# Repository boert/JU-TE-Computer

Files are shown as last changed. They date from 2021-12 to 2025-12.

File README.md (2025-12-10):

# JU+TE-Computer
Schaltpläne und z.T. Layouts für den JU+TE Computer

## JU+TE Tiny (2k-System)
Da vom JU+TE Computer kein zusammenhängender Schaltplan existierte, wurde er mit KiCAD erstellt.
Dieser Schaltplan wurde mit dem existierenden Layout verknüpft.
Schaltplan und Layout sind konsistent.

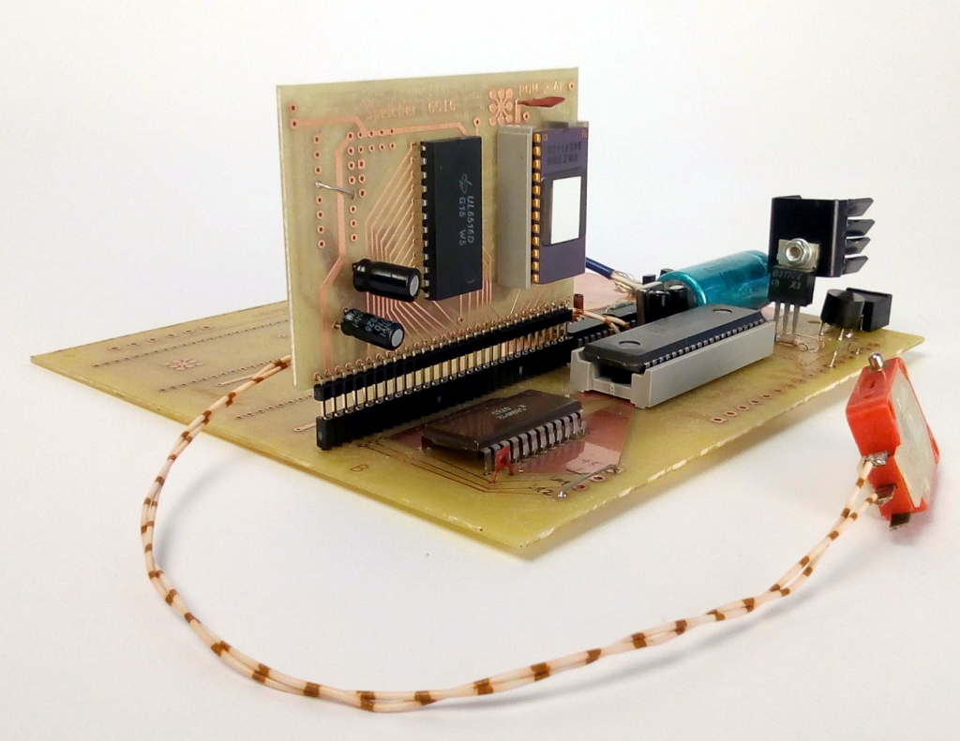
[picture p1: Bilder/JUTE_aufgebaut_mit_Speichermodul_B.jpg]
JU+TE 2k mit Speichermodul Typ B


Für den Minimalbetrieb sind ein Speichermodul (Typ A, B oder C) und eine Tastatur erforderlich.

## Erweiterungen zum JU+TE

### Speichermodul Typ A (2 kByte EPROM, 1 bis 8 kByte RAM) 
<p align="center">
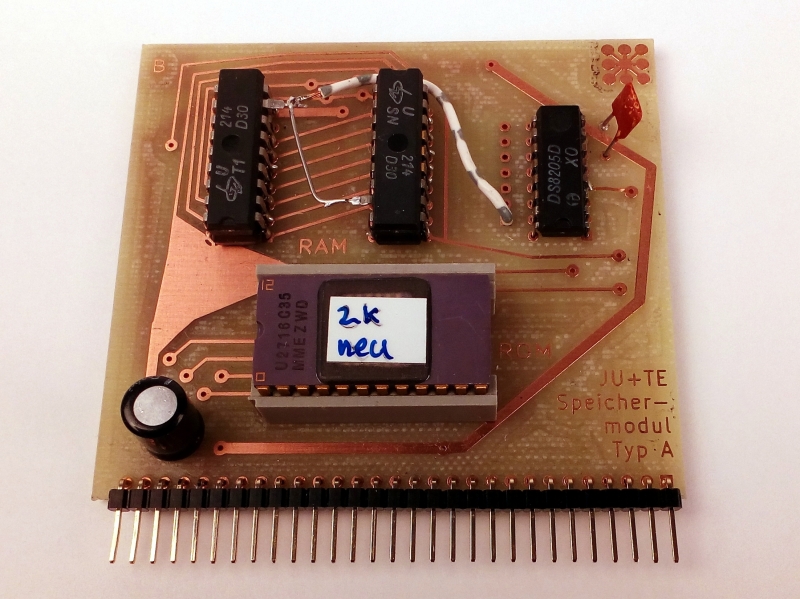
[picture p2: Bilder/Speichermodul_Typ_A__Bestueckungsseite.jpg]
Speichermodul Typ A, Bestückungsseite
  
&nbsp;
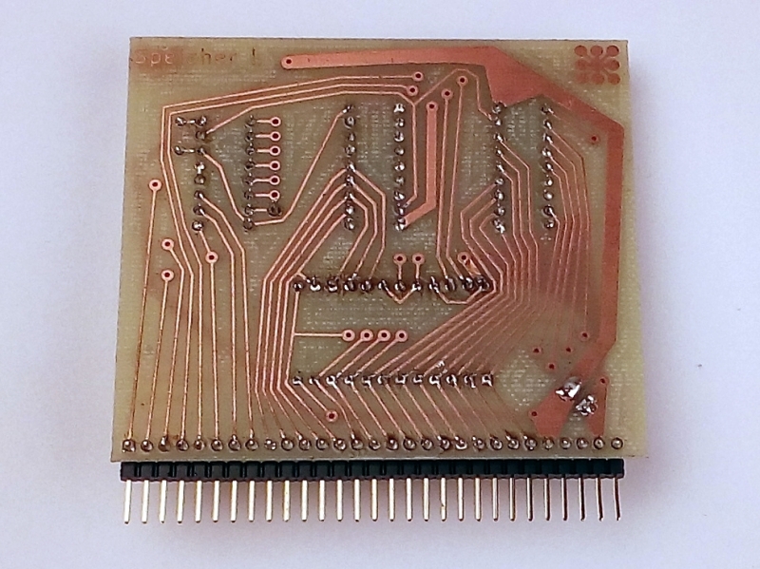
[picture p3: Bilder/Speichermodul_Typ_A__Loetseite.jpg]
Speichermodul Typ A, Lötseite
  
</p>
RAM erweiterbar bis auf 8 kByte durch zusätzliche U214 (Huckepack).
Für das 2k-System oder als unterer ROM für das 4k-System geeignet.<br>
Beim abgebildeten Modul wurde der RAM auf 2 kByte aufgestockt.
Bei mehr als 1 kByte RAM wird ein Adressdekoder DS8205D benötigt.

### Speichermodul Typ B (2 kByte EPROM, 2 bis 8 kByte RAM)
<p align="center">
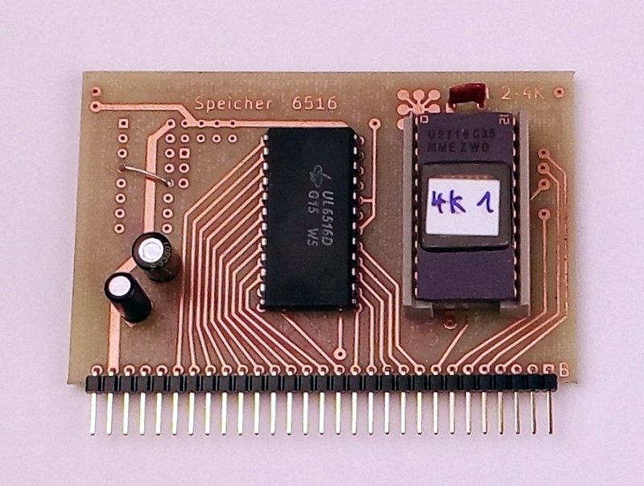
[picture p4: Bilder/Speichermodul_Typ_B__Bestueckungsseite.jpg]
Speichermodul Typ B, Bestückungsseite
  
&nbsp;
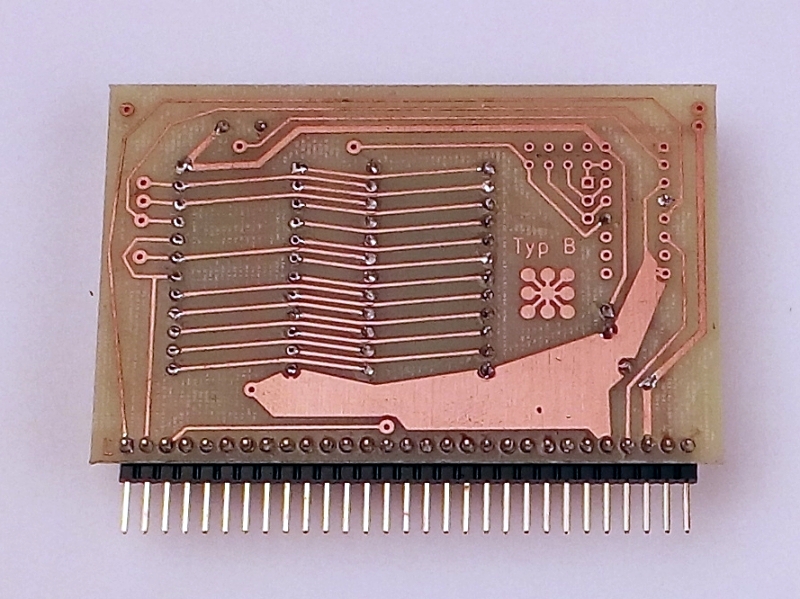
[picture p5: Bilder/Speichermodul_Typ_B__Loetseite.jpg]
Speichermodul Typ B, Lötseite
  
</p>
RAM erweiterbar bis auf 8 kByte durch zusätzliche U6516 (Huckepack).
Für das 2k-System oder als unterer ROM für das 4k-System geeignet.
Bei mehr als 2 kByte RAM wird ein Adressdekoder DS8205D benötigt.

### Speichermodul Typ C (8 kByte EPROM, 8 kByte RAM)
<p align="center">
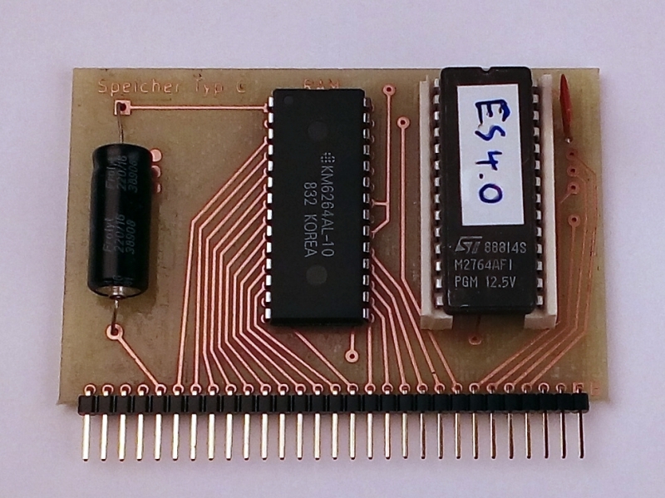
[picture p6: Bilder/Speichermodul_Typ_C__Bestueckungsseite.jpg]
Speichermodul Typ C, Bestückungsseite
  
&nbsp;
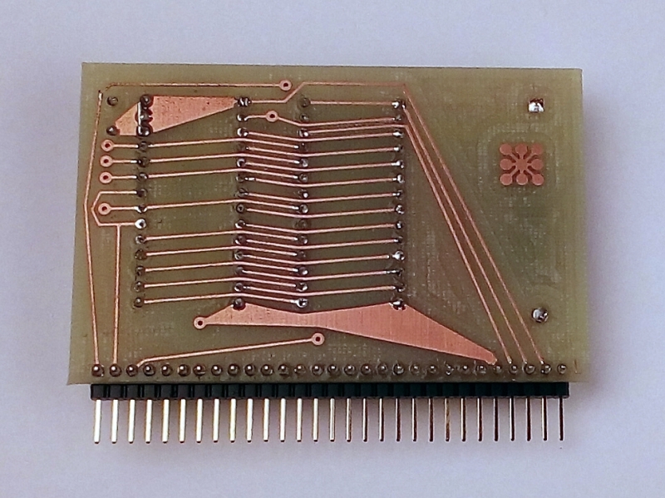
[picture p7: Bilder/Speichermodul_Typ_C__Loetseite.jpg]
Speichermodul Typ C, Lötseite
  
</p>
Für alle Ausbaustufen geeignet. Wenn das 2k-System oder das 4k-System in einen U2764 (8 kByte EPROM) gebrannt werden, muss das System ab Offset 0800h stehen.
Mit vier dieser Module läßt sich ein Vollausbau des Speichers realisieren (32 kByte RAM, 30 kByte EPROM).
Auch als Videospeicher für die Videoerweiterung nutzbar. In diesem Fall wird der EPROM nicht benötigt.

### Speichermodul Typ D (2 kByte EPROM)
<p align="center">
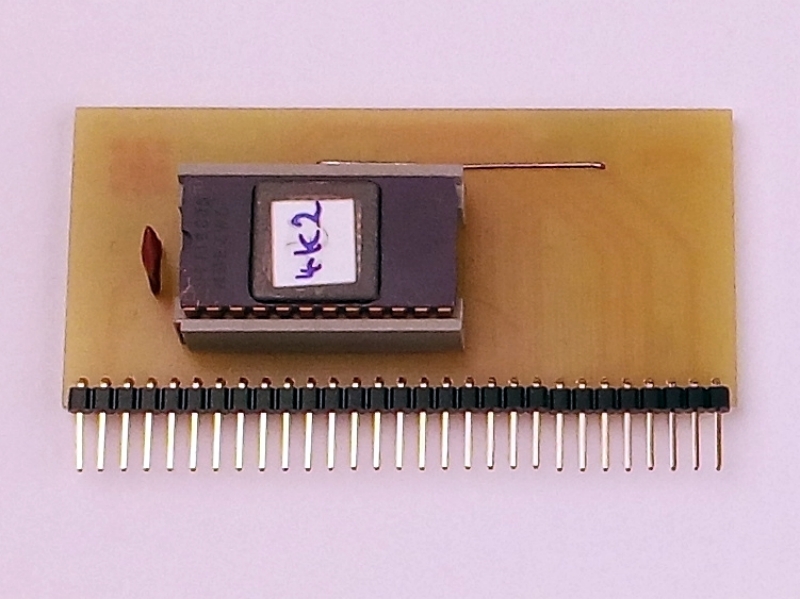
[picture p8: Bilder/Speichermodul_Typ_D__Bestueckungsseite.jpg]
Speichermodul Typ D, Bestückungsseite
  
&nbsp;
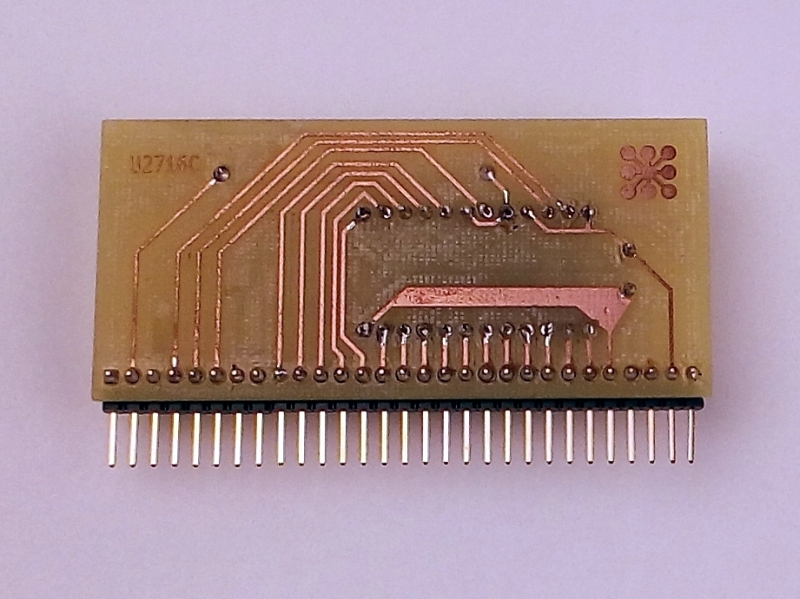
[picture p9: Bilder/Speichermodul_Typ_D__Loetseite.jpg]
Speichermodul Typ D, Lötseite
  
</p>
Das Modul wird nur als Ergänzungsspeicher für das 4k-System benötigt, falls Modul A oder Modul B schon vorhanden sind.

### RAM-Stütze
Dient dem Erhalt des RAM-Inhaltes im ausgeschalteten Zustand für Module mit CMOS-Schaltkreisen (U224, U6516 oder HM6264LP).
Mit verbesserter Reset-Schaltung. Die Reset-Schaltung nutzt die ~9V vom Ladekondesator.

### Magnetbandanschluss
<p align="center">
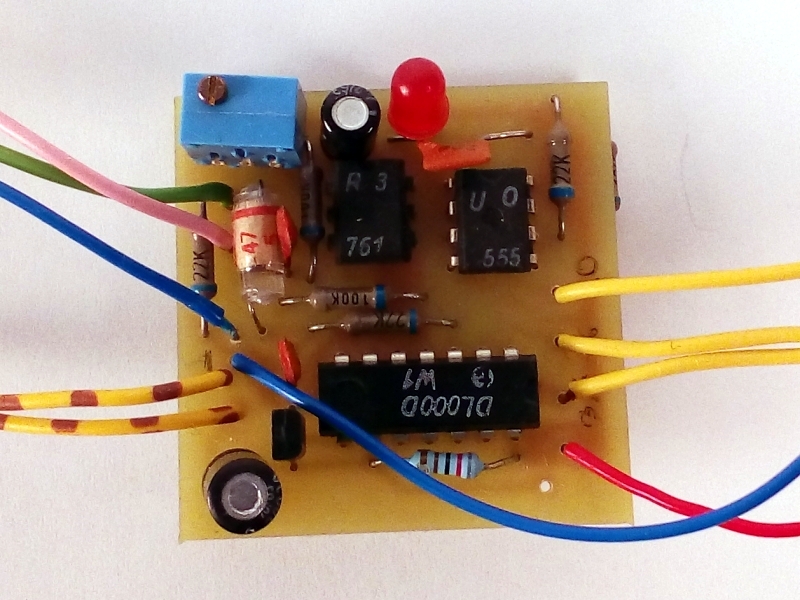
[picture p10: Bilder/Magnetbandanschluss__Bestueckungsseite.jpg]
Magnetbandanschluss, Bestückungsseite
  
&nbsp;
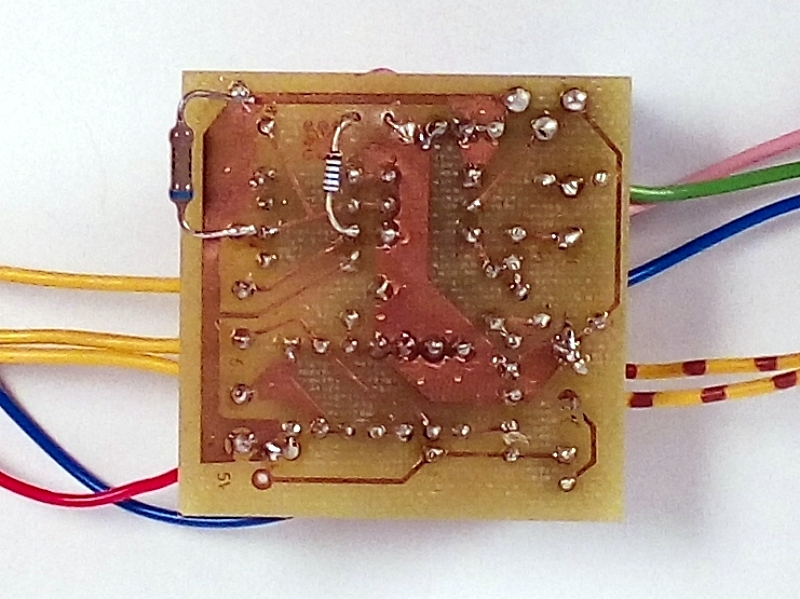
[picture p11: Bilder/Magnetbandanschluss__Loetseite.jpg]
Magnetbandanschluss, Lötseite
  
</p>
Damit lassen sich BASIC-Programme auf Band sichern und wieder zurücklesen.
Das Verfahren ist relativ einfach: Die Binärdaten werden über die SIO (Port P3.7) ausgegeben und mit 4,8 kHz vom Port P3.6 moduliert.
Es wird direkt der Speicherinhalt ausgegeben. Es gibt keine Fehlererkennung bzw. -korrektur, kein Dateiname und keine Adressinformation.
Die Schaltung läßt sich optimieren, indem der Pull-Up-Widerstand zwischen OPV (B761) und Inverter (B555) auf z.B. 8 kOhm reduziert wird.
Damit wird das Puls-/Pausverhältnis korrigiert.
Mit anderen Varianten des Magnektbankinterfaces (4k-System, 6k-System) läßt sich am 2k-System nichts mehr abspeichern, da dort der Modulator (DL000) fehlt.

### Magnetbandinterface 4k-System
<p align="center">
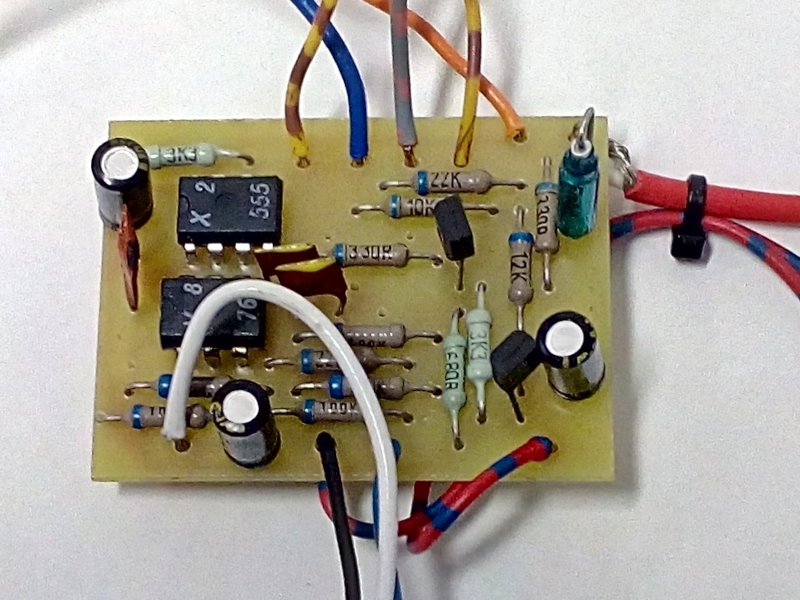
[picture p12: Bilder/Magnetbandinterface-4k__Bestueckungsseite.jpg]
Magnetbandinterface 4k-System, Bestückungsseite
  
&nbsp;
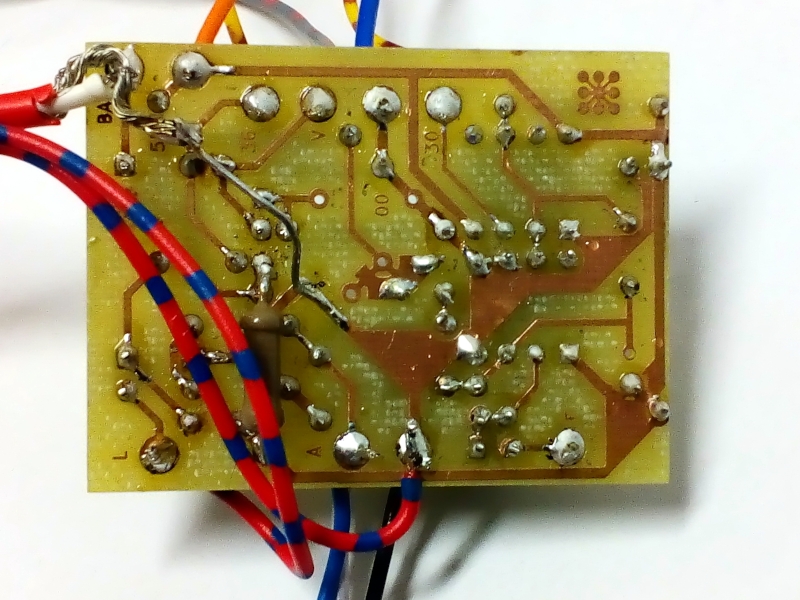
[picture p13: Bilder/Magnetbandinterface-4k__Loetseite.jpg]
Magnetbandinterface 4k-System, Lötseite
  
</p>
Weiterentwickeltes Magnetband-Interface für das 4k-System, zusätzlich mit integriertem Videosignalinverter.
Im 4k-System wird ein anderes Aufzeichnungsformat verwendet: Es gibt Trennzeichen (600 Hz), 0-Bits (1200 Hz) und 1-Bits (2400 Hz). Das Format entsprich dem des KC85 und enthält Dateinamen, Ladeadresse und Prüfsummen.

### Tastatur
Schaltungsvorschlag für eine 4x12 Matrixtastatur.

### Videoinverter
Ändert die Polarität des Videosignals und erzeugt ein BAS-Signal.
Die Originalschaltung ist sehr empfindlich. Robuster ist die Variante, die auf dem 4k-Magnetbandinterface realisiert ist. 

### UHF-Modulator
Mischt das BAS-Signal auf TV-Kanal 36. Die Erweiterung wird hier nicht weiter beschrieben.

### EPROM-Programmierzusatz
Erweiterung des JU+TE zum EPROM-Programmiergerät für die Typen U2716, U2764 und U27128.

### S3004-Interface
Potentialgetrennte Schnittstelle für die elektronische Schreibmaschine Erika S3004.
Nutzung der Schreibmaschine als Drucker.
Da der Rückkanal nicht verwendet wird, kann die Schreimaschine nicht als Tastatur genutzt werden.

### V.24-Interface
Pegelwandlerstufe zur Kopplung mit seriellen Perioheriegeräten (z.B. Drucker) oder zur Rechnerkopplung.
Die Interfaceschaltung nutzt die 9V-Spannung vom Ladekondensator.

### IFSS-Interface
Schnittstelle nach dem Prinzip der gekoppelten Stromschleifen, IFSS (Interface seriell sternförmig).
Das IFSS-Interface benötigt die 9V-Spannung vom Ladekondensator.

### AD-Wandler
Zur Messung von Spannungen zwischen 0 und 999 mV.

### Videoerweiterung
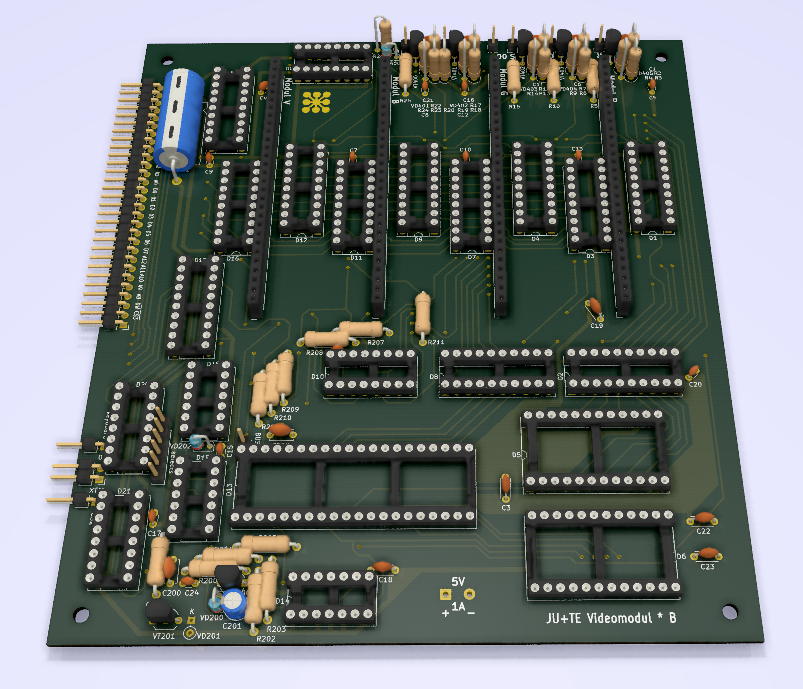
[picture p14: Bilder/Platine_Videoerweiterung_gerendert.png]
Videoerweiterung (Visualisierung)

Damit wird die Videosignalerzeugung von einem separaten Prozessor (UB8810, UB8830 oder UB8860) übernommen.
Der Bildspicher wird im Bereich zwischen %4000 und %5FFF im System eingeblendet.
Über Steuerregister (Adressen %6000-%63FF) wird festgelegt, auf welche Speicherebenen des Videospeicher zugegriffen wird.

Die mögliche Bildschirmauflösung und die nutzbare Farbtiefe hängt vom Speicherausbau ab:

Speichermodule | Video-RAM | Auflösung | Farbtiefe
-------------- | --------: | :-------: | ---------
1              | 8 kByte   |  320x192  | s/w
2              | 16 kByte  |  640x192  | s/w
4              | 32 kByte  |  320x192  | 16 Farben   
4              | 32 kByte  |  640x192  | 8 Farben

Ob es Software gibt, welche die hochauflösenden 640x192 Pixel-Modi nutzt, entzieht sich meiner Kenntniss.
Die Installation der Videoerweiterung erfordert die Verdrahtung zusätzlicher Signale, die nicht am Modulsteckplatz anliegen: TAKT, /CS3, KEY und BUSY

## JU+TE Kompakt (6k-System)
Im JU+TE Kompakt sind die Videoerweiterung, das Magnetbandinterface (4k-Version), 32 kByte RAM, die RAM-Stütze und 8 kByte EPROM integriert.
Um die Videoerweiterung zu nutzen wird im EPROM das 6k-System eingespielt.

## Nutzung der frei verfügbaren Ports

| Ports | P2.0 | P2.1 | P2.2 | P2.3 | P2.4 | P2.5 | P2.6 | P2.7 | P3.0 | P3.1 | P3.2 | P3.3 | P3.4 | P3.5 | P3.6 | P3.7 |
| --- |:----:|:----:|:----:|:----:|:----:|:----:|:----:|:----:|:----:|:----:|:----:|:----:|:----:|:----:|:----:|:---:|
| JU+TE-Grundplatine (7/1987) | | | | | | | | | | | | | (BS) | | | SYN |
| Magnetbandinterface (2k, 12/1987) | | | | | | | | | LOAD | | | | | | SAVE | Umschalt |
| Lauflicht (4/1988) | LED  | LED  | LED  | LED  | LED  | LED  | LED  | LED  | | | | | | | | |
| EPROM-Programmierzusatz (10/1988) | A+D  | A+D  | A+D  | A+D  | A+D  | A+D  | A+D  | A+D  | | | | | CTRL | CTRL | CTRL | |
| Magnetbankinterface (4k, 3/1989) | | | | | | | | | LOAD | | | | | | SAVE | |
| S3004-Interface (HW-SIO, 5/1989) | | | | | | | | | | | | | | | | TxD |
| S3004-Interface (SW, 5/1989) | | | | | | | | | | DSR  | | | | TxD  | | |
| IFSS-Inferface (10/1989) | | | | | | | | | E | | | | | | | S |
| V.24-Interface (HW-SIO, 10/1989) | | | | | | | | | RxD  | | | | | | | TxD |
| V.24-Interface (SW, K6340, 10/1989) | | | | | | | | | | DSR  | | | | TxD  | | |
| Streifenkorrektur (11/1989) | | | | | | | | | | | | | | VSYN | | |
| AD-Wandler (12/1989) | QA | QB | QC | QD | NSD  | MSD  | ISD  | | | | | | | | | |
| Magnetbankinterface (ES4.0, 1990) | | | | | | | | | LOAD | | | | | | SAVE | |
| Videoerweiterung (6/1990) | | | | | | | | | | | BUSY | | /HR  | | | |
| ROM-Bank (ES4.0, 2019) | | | | | | | | | | | | | | /BR  | | STEP |
| ROM-Bank (ES1988, 10/2021) | | | | | | | | | | | | | | STEP | | |
| | | | | | | | | | | | | | | | | |

Legende:  
A+D = Adresse und Daten  
BR = bank reset, Bank zurücksetzen  
BS = bank switch, Bankumschaltung, bisher keine Nutzung bekannt  
BUSY = Zugriff ohne Bildstörung  
CTRL = Steuerleitung  
DSR = Dataset Read, Empfangsbereitschaft  
E = Empfang  
HR = high resolution, Umschaltung Grafikmodus  
RxD = Empfangsdaten  
S = Senden  
STEP = Bank weiterschalten  
SYN = Synchronsignal für Video  
TxD = Sendedaten  
VSYN = Zeilensynchronisierung  

## Quellen  
https://hc-ddr.hucki.net/wiki/lib/exe/fetch.php/tiny/jutecomp1.pdf  
https://hc-ddr.hucki.net/wiki/lib/exe/fetch.php/tiny/jutecomp2.pdf  
https://hc-ddr.hucki.net/wiki/lib/exe/fetch.php/tiny/jutecomp3.pdf 

## Wikipedia
https://de.wikipedia.org/wiki/Ju-Te-Computer

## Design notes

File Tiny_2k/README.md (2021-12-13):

# KiCad-Projekt für JU+TE Computer

## Versionsgeschichte

### Version 1
nach Originallayout

### Version 2
- Bestückungsdruck ergänzt
- Footprint für C5 verlängert
- U14 stehend, statt liegend
- Footprint für D3 überarbeitet
- Footprints für Widerstände überarbeitet

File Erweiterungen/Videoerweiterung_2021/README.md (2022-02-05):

# JU+TE Videoerweiterung, 2021

Mit der Videoerweiterung läßt sich das Grundsystem zum 6k-System erweitern.

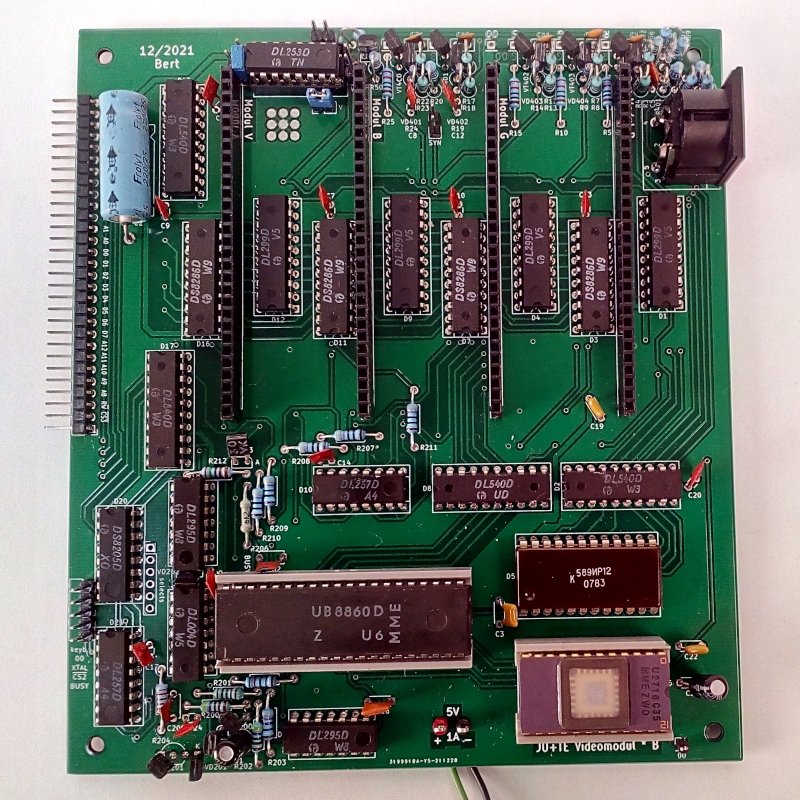
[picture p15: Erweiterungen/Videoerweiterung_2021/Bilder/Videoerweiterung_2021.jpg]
Videoerweiterung 2021


## Voraussetzungen
Folgende Voraussetzungen sind dafür zu erfüllen:
- im Steckplatz 1 (/CS0, /CS7) muß der EPROM mit dem 6k-System stecken
- im Steckplatz 1 müssen 8 kByte RAM bestückt sein
- im Steckplatz 4 wird die Videoerweiterung gesteckt
- ggf. muß eine angepasste Tastatur verwendet werden
- die Zusatzverbindungen für Takt, /CS2, /KEY und BUSY sind herzustellen
- es wird ein Bildschirm mit SCART-Eingang und ein entprechendes Adapterkabel benötigt

## Veränderungen gegenüber der Originalplatine
Die Version 2021 der Videoerweiterung enthält gegenüber dem Original von 1990 folgende Veränderungen:
- Videobuchse (DIN 5-polig) inklusive der nötigen Widerstände integriert;
  es passt das SCART-Adapterkabel vom Z9001
- Verbindungen zur Hauptplatine (Takt, /CS2, BUSY und /KEY) auf einer Steckleiste zusammengefasst
- BUSY-Signal zum Rand geführt
- Jumper für Umschaltsignal (high resolution) /HR ergänzt (Auswahl: low, high oder P3.4)
- am Videomultiplexer wurden Jumper für die Signale B und V ergänzt
- Jumper W hinzugefügt, um den Widerstandswert von R36 anpassen zu können (6,8 kOhm bzw. 2,2 kOhm)
- Jumper für SYN-Signal hinzugefügt
- frei Flächen mit 00 (GND) gefüllt
- Workaround für Timingprobleme ergänzt: R212 (1,5k) und VD203 (SAY32), Beschreibung in jutecomp3.pdf (Seite 46, Mitte unten)
- Massepunkt hinzugefügt (erleichtert die Fehlersuche)

## Belegung der Videobuchse (DIN 5-polig)
Pin    | Signal
------ | ------
1      | Grün
2      | Blau
3      | Synchronsignal bzw. BAS
4      | Rot
5      | Umschaltsignal /AV-RGB
Schirm | GND

Die Beschreibung eines passenden SCART-Kabels ist bei Ulrich Zander zu finden:
https://www.sax.de/~zander/z9001/tp.html#TV

## Anpassungen an der Grundplatine
Die Stromaufnahme der Videoerweiterung beträgt (ohne Video-RAM-Module) ca. 800 mA.
Damit ist der Spannungsregler der Grundplatine (B3170V) überfordert.
Es ist eine separate Einspeisung von geregelten 5V über die Videoerweiterung nötig.
Zum Schutz des B3170V (Spannung am Ausgang ggf. höher, als am Eingang) wird eine Diode zwischen Pin 2 (Ausgang, Anode) und Pin 3 (Eingang, Kathode) plaziert.

Für den Speicherbereich zwischen %6000 und %7FFF gibt es einen separaten Adressdekoder auf der Videoerweiterung. Damit neben der Bildschirmsteuerung die Tastatur weiterhin funktioniert, muß das /CS3-Signal zum Tastaturlatch (V40098D, Pin 1 und 15) aufgetrennt werden. Die Tastatur bekommt ihr Auswahlsignal (/KEY) nun von der Videoerweiterung.
Ein Rückbau ist durch Einsatz einer Steckbrücke möglich.

Der Videospeicher (VRAM) wird im Bereich %4000 bis %5FFF eingeblendet und benötig dazu das /CS2-Signal vom Steckplatz 3.

Außerdem wird noch der Systemtakt benötigt. Dieser läßt sich direkt nebem dem Taktgenerator abgreifen.

Das BUSY-Signal kann über einen 100 kOhm-Widerstand mit Port P3.2 der Haupt-CPU verbunden werden.

Wenn man alle zusätzlich Signale auf eine separate Buchsenleiste führt, ist der Einbau und auch der Rückbau der Videoerweiterung schnell und unkompliziert.

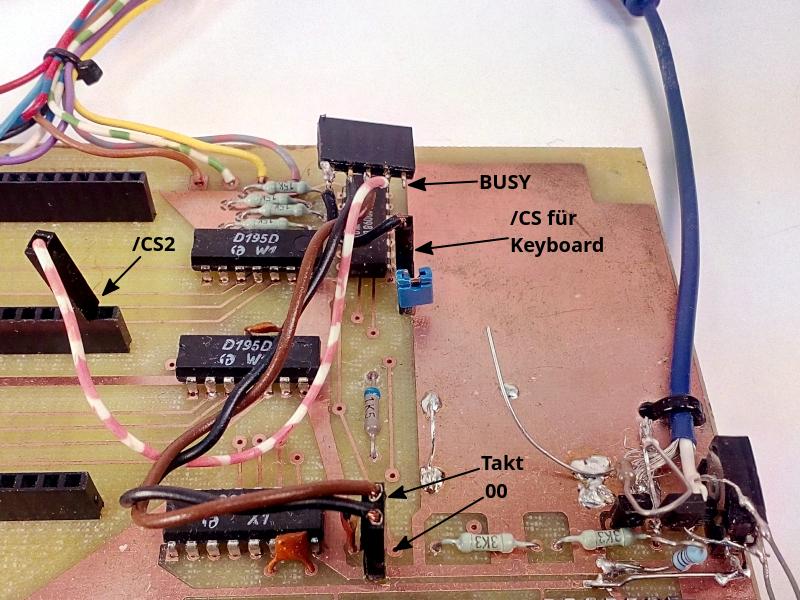
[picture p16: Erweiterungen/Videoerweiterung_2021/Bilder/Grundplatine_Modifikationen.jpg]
Videoerweiterung 2021


## Änderungen an der Grundplatine (Kurzform)
- Schutzdiode für B3170V einbauen
- Auftrennung /CS3, Steckbrücke für den Betrieb ohne Videoerweiterung ergänzen
- /CS2-Signal vom vorletzten Steckplatz verdrahten
- Systemtakt anschließen
- optional BUSY über 100 kOhm mit P3.2 verbinden

## Einbausituation
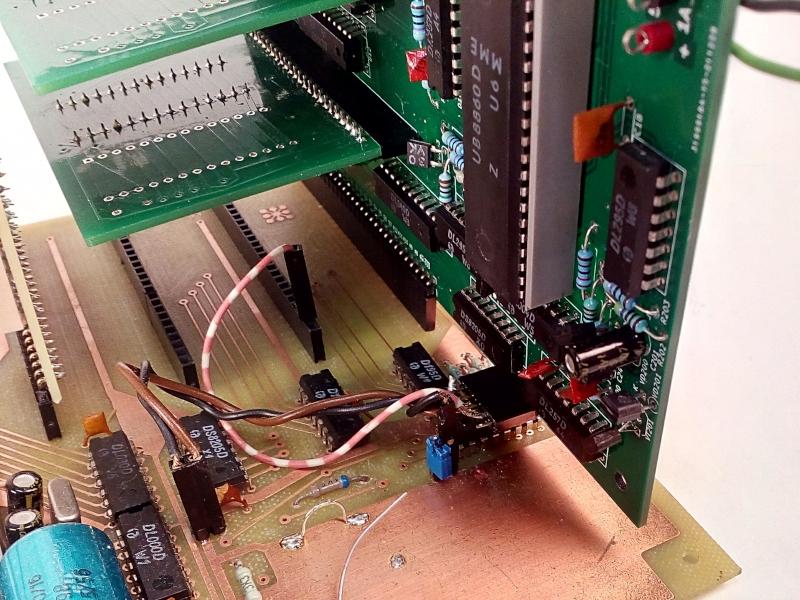
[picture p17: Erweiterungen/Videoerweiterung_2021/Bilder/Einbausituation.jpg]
Videoerweiterung 2021


Die senkrechte Montage hat den Nachteil, das hohe Speichermodule - wie der Typ C - die Modulsteckplätze 2 und 3 blockieren. Mit niedrigeren Speichermodulen oder einer waagerechten Montage (andere Steckverbinder) umgeht man das Problem.

## Quellen
https://hc-ddr.hucki.net/wiki/lib/exe/fetch.php/tiny/jutecomp3.pdf  
https://hc-ddr.hucki.net/wiki/doku.php/tiny/nachbauten

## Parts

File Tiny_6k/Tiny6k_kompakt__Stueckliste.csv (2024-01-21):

Source | Tiny6k_kompakt.sch
Kicad Rev | Eeschema 5.1.5+dfsg1-2build2
Generated Date | Sun Jan 21 20:19:16 2024
Title | JU+TE Tiny mit Videoerweiterung
Company | Jugend+Technik
Revision | 3
Date Issue | 21.01.24
Comment | Bert
Reference | Value | Library | Library Ref
D31 | UB8830 | RFT_Digitalschaltkreise | UB8830
D30 | DS8212D | RFT_Digitalschaltkreise | DS8212D
D28 | DL000D | RFT_Digitalschaltkreise | DL000D
D27 | DS8205D | RFT_Digitalschaltkreise | DS8205D
D25 | HM62256BLP | Memory_RAM | HM62256BLP
D34 | MB104 | RFT_Optoelektronik | MB104
X100 | Port 2 | Connector_Generic | Conn_01x08
X101 | Port 3 | Connector_Generic | Conn_01x08
VD105 | VQA15 | RFT_Optoelektronik | VQA15
VD104 | VQA15 | RFT_Optoelektronik | VQA15
D29 | B555D | RFT_Analogschaltkreise | B555D
VD103 | SAY | Device | D
C104 | 2.2µF | Device | CP_Small
VT101 | SC236 | RFT_Transistoren_und_Dioden | SC236
R105 | 220 | Device | R_Small
R106 | 2.4k | Device | R_Small
R107 | 1.2k | Device | R_Small
R110 | 22k | Device | R_Small
R111 | 75 | Device | R_Small
R112 | 8.2k | Device | R_Small
R100 | 1.2k | Device | R_Small
Q100 | 8 MHz | Device | Crystal_Small
VT100 | SC308 | RFT_Transistoren_und_Dioden | SC308
VD102 | SAY | Device | D
R103 | 820 | Device | R_Small
X104 | Batterie | Connector_Generic | Conn_01x02
R101 | 470 | Device | R_Small
D26 | U2764 (U27128) | RFT_Digitalschaltkreise | U27128
VD100 | 3PM 05 | Device | D_Bridge_+-AA
X103 | AC in | Connector_Generic | Conn_01x02
D100 | B3170V | RFT_Analogschaltkreise | B3170V
C101 | 4700µF | Device | CP_Small
C102 | 22nF | Device | C_Small
R108 | 180 | Device | R_Small
VD101 | SZX21/5.6 | Device | D_Zener_Small
R104 | 220 | Device | R_Small
C103 | 100nF | Device | C_Small
D24 | DL540D | RFT_Digitalschaltkreise | DL540D
X130 | Zeilen | Connector_Generic | Conn_01x08
R113 | 8x15k | Device | R_Network08
X131 | Key | Connector_Generic | Conn_01x01
D22 | DS8205D | RFT_Digitalschaltkreise | DS8205D
D23 | DS8205D | RFT_Digitalschaltkreise | DS8205D
X133 | Spalten | Connector_Generic | Conn_01x08
X132 | Spalten | Connector_Generic | Conn_01x08
X122 | Videomodul | Connector_Generic | Conn_01x29
X110 | Modul 2 | Connector_Generic | Conn_01x29
X120 | XTAL | Connector_Generic | Conn_01x02
D32 | B861D | RFT_Analogschaltkreise | B861D
R123 | 2.4k | Device | R_Small
R124 | 47k | Device | R_Small
R120 | 47k | Device | R_Small
R121 | 47k | Device | R_Small
C109 | 2.2µF | Device | CP_Small
R122 | 100k | Device | R_Small
C108 | 2.2µF | Device | CP_Small
R119 | 47k | Device | R_Small
X142 | Tape IN | Connector_Generic | Conn_01x01
R115 | 12k | Device | R_Small
VT102 | SC236 | RFT_Transistoren_und_Dioden | SC236
R114 | 220 | Device | R_Small
C105 | 1µF | Device | CP_Small
X140 | Speaker | Connector_Generic | Conn_01x02
R116 | 22k | Device | R_Small
R118 | 1k | Device | R_Small
X141 | Tape OUT | Connector_Generic | Conn_01x01
C116 | 10µF | Device | CP_Small
C117 | 10µF | Device | CP_Small
C114 | 10µF | Device | CP_Small
C115 | 10µF | Device | CP_Small
C110 | 22nF | Device | C_Small
C111 | 22nF | Device | C_Small
C112 | 22nF | Device | C_Small
C113 | 22nF | Device | C_Small
R109 | 560 | Device | R_Small
C100 | 10µF | Device | CP_Small
R102 | 10k | Device | R_Small
X121 | ~CS2 | Connector_Generic | Conn_01x01
X102 | BUSY | Connector_Generic | Conn_01x01
X106 | Bankumschaltung | Jumper | SolderJumper_2_Open
X105 | Reset | Connector_Generic | Conn_01x02
VD120 | SAY | Device | D
VD121 | SAY | Device | D
VD122 | SAY | Device | D
VD123 | SAY | Device | D
VD124 | SAY | Device | D
VD125 | SAY | Device | D
VD126 | SAY | Device | D
VD127 | SAY | Device | D
VD131 | SAY | Device | D
VD130 | SAY | Device | D
VD132 | SAY | Device | D
VD134 | SAY | Device | D
VD136 | SAY | Device | D
VD133 | SAY | Device | D
VD135 | SAY | Device | D
VD137 | SAY | Device | D
VT201 | SC236 | RFT_Transistoren_und_Dioden | SC236
VD201 | SZX21/7.5 | Diode | ZPDxx
VT200 | SC308 | RFT_Transistoren_und_Dioden | SC308
R201 | 1k | Device | R
R200 | 4.7k | Device | R
R202 | 4.7k | Device | R
R203 | 470 | Device | R
C201 | 1µF | Device | CP_Small
VD200 | SAY32 | Device | D
C200 | 33pF | Device | C_Small
R204 | 8.2k | Device | R
D19 | DL004D | RFT_Digitalschaltkreise | DL004D
R205 | 1.2k | Device | R
D5 | DS8212D | RFT_Digitalschaltkreise | DS8212D
D13 | UB8830 | RFT_Digitalschaltkreise | UB8830
D6 | U2716 | RFT_Digitalschaltkreise | U2716
D15 | DL540D | RFT_Digitalschaltkreise | DL540D
D17 | DL540D | RFT_Digitalschaltkreise | DL540D
D2 | DL540D | RFT_Digitalschaltkreise | DL540D
D8 | DL540D | RFT_Digitalschaltkreise | DL540D
D14 | DL295D | RFT_Digitalschaltkreise | DL295D
D21 | DL257D | RFT_Digitalschaltkreise | DL257D
D10 | DL257D | RFT_Digitalschaltkreise | DL257D
X200 | Bus | Connector_Generic | Conn_01x29
D20 | DS8205D | RFT_Digitalschaltkreise | DS8205D
D18 | DL295D | RFT_Digitalschaltkreise | DL295D
C202 | 220p | Device | C_Small
R206 | 6.2k | Device | R
VD202 | SAY32 | Device | D
R211 | 470 | Device | R
X203 | select | Connector_Generic | Conn_01x06
R207 | 470 | Device | R_Small
R208 | 470 | Device | R_Small
R210 | 470 | Device | R_Small
R209 | 470 | Device | R_Small
X201 | ~CS2 | Connector_Generic | Conn_01x01
X202 | XTAL | Connector_Generic | Conn_01x02
X204 | ~KEY | Connector_Generic | Conn_01x01
X205 | BUSY | Connector_Generic | Conn_01x01
D16 | DS8286D | RFT_Digitalschaltkreise | DS8286D
D12 | DL299D | RFT_Digitalschaltkreise | DL299D
X300 | 8k RAM-Modul | Connector_Generic | Conn_01x29
D11 | DS8286D | RFT_Digitalschaltkreise | DS8286D
D9 | DL299D | RFT_Digitalschaltkreise | DL299D
X302 | 8k RAM-Modul | Connector_Generic | Conn_01x29
D3 | DS8286D | RFT_Digitalschaltkreise | DS8286D
D1 | DL299D | RFT_Digitalschaltkreise | DL299D
X301 | 8k RAM-Modul | Connector_Generic | Conn_01x29
D7 | DS8286D | RFT_Digitalschaltkreise | DS8286D
D4 | DL299D | RFT_Digitalschaltkreise | DL299D
X303 | 8k RAM-Modul | Connector_Generic | Conn_01x29
X400 | SCART-F | Connector | SCART-F
R408 | 100 | Device | R
D0 | DL253D | RFT_Digitalschaltkreise | DL253D
R26 | 6.8k | Device | R_Small
R24 | 2.2k | Device | R_Small
VD400 | SAY32 | Device | D_Small
VD401 | SAY32 | Device | D_Small
R22 | 1k | Device | R_Small
R23 | 1k | Device | R_Small
VT400 | SC236 | RFT_Transistoren_und_Dioden | SC236
R25 | 220 | Device | R_Small
C21 | 33pF | Device | C_Small
R19 | 2.2k | Device | R_Small
VD402 | SAY32 | Device | D_Small
R17 | 1k | Device | R_Small
R18 | 1k | Device | R_Small
R20 | 220 | Device | R_Small
C16 | 33pF | Device | C_Small
R14 | 2.2k | Device | R_Small
VD403 | SAY32 | Device | D_Small
R12 | 1k | Device | R_Small
R13 | 1k | Device | R_Small
R15 | 220 | Device | R_Small
C11 | 33pF | Device | C_Small
R9 | 2.2k | Device | R_Small
VD404 | SAY32 | Device | D_Small
R7 | 1k | Device | R_Small
R8 | 1k | Device | R_Small
R10 | 220 | Device | R_Small
R4 | 2.2k | Device | R_Small
VD405 | SAY32 | Device | D_Small
R3 | 1k | Device | R_Small
R5 | 220 | Device | R_Small
C6 | 33pF | Device | C_Small
C1 | 33pF | Device | C_Small
VT401 | SC236 | RFT_Transistoren_und_Dioden | SC236
VT402 | SC236 | RFT_Transistoren_und_Dioden | SC236
VT404 | SC236 | RFT_Transistoren_und_Dioden | SC236
VT403 | SC236 | RFT_Transistoren_und_Dioden | SC236
R2 | 1k | Device | R_Small
R407 | 220 | Device | R_Small
R406 | 220 | Device | R_Small
R405 | 220 | Device | R_Small
R400 | 160 | Device | R_Small
R401 | 75 | Device | R_Small
R402 | 160 | Device | R_Small
R403 | 160 | Device | R_Small
R404 | 51 | Device | R_Small
JP400 | HR direkt | Device | Jumper_NC_Small
JP401 | HR_VCC | Device | Jumper_NO_Small
JP402 | HR_GND | Device | Jumper_NO_Small
D500 | U6264D | RFT_Digitalschaltkreise | U6264D
X500 | Bus | Connector_Generic | Conn_01x29
D501 | U2764 | RFT_Digitalschaltkreise | U2764
C501 | 33nF | Device | C_Small
C500 | 220µF | Device | CP_Small

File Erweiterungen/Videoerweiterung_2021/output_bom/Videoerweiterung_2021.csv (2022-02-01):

Source | Videoerweiterung.sch
Kicad Rev | Eeschema 5.1.10
Generated Date | Di 01 Feb 2022 20:56:21 CET
Title | JU+TE Videoerweiterung 2021
Company | Jugend+Technik
Revision | 3
Date Issue | 1.2.22
Comment | Bert
Reference | Value | Library | Library Ref
H1 | MountingHole | Mechanical | MountingHole
H2 | MountingHole | Mechanical | MountingHole
H4 | MountingHole | Mechanical | MountingHole
H3 | MountingHole | Mechanical | MountingHole
VT201 | SC236 | RFT_Transistoren_und_Dioden | SC236
VD201 | SZX21/7.5 | Diode | ZPDxx
VT200 | SC308 | RFT_Transistoren_und_Dioden | SC308
R201 | 1k | Device | R
R200 | 4 | 7k | Device | R
R202 | 4 | 7k | Device | R
R203 | 470 | Device | R
C201 | 1µF | Device | CP_Small
VD200 | SAY32 | Device | D
C200 | 33pF | Device | C_Small
R204 | 8 | 2k | Device | R
D19 | DL004D | RFT_Digitalschaltkreise | DL004D
R205 | 1 | 2k | Device | R
D5 | DS8212D | RFT_Digitalschaltkreise | DS8212D
D13 | UB8860 | RFT_Digitalschaltkreise | UB8830
D6 | U2716 | RFT_Digitalschaltkreise | U2716
D15 | DL540D | RFT_Digitalschaltkreise | DL540D
D17 | DL540D | RFT_Digitalschaltkreise | DL540D
D2 | DL540D | RFT_Digitalschaltkreise | DL540D
D8 | DL540D | RFT_Digitalschaltkreise | DL540D
D14 | DL295D | RFT_Digitalschaltkreise | DL295D
D21 | DL257D | RFT_Digitalschaltkreise | DL257D
D10 | DL257D | RFT_Digitalschaltkreise | DL257D
X200 | Bus | Connector_Generic | Conn_01x29
D20 | DS8205D | RFT_Digitalschaltkreise | DS8205D
D18 | DL295D | RFT_Digitalschaltkreise | DL295D
C202 | 220p | Device | C_Small
R206 | 6 | 2k | Device | R
VD202 | SAY32 | Device | D
R211 | 470 | Device | R
X203 | select | Connector_Generic | Conn_01x06
R207 | 470 | Device | R_Small
R208 | 470 | Device | R_Small
R210 | 470 | Device | R_Small
R209 | 470 | Device | R_Small
X201 | ~CS2 | Connector_Generic | Conn_01x01
X202 | XTAL | Connector_Generic | Conn_01x02
X204 | ~KEY | Connector_Generic | Conn_01x01
X205 | BUSY | Connector_Generic | Conn_01x01
X206 | POWER | Connector_Generic | Conn_01x02
TP201 | 00 | Connector | TestPoint_Small
R212 | 1 | 5k | Device | R_Small
VD203 | SAY32 | Device | D_Small
D16 | DS8286D | RFT_Digitalschaltkreise | DS8286D
D12 | DL299D | RFT_Digitalschaltkreise | DL299D
X300 | 8k RAM-Modul | Connector_Generic | Conn_01x29
D11 | DS8286D | RFT_Digitalschaltkreise | DS8286D
D9 | DL299D | RFT_Digitalschaltkreise | DL299D
X302 | 8k RAM-Modul | Connector_Generic | Conn_01x29
D3 | DS8286D | RFT_Digitalschaltkreise | DS8286D
D1 | DL299D | RFT_Digitalschaltkreise | DL299D
X301 | 8k RAM-Modul | Connector_Generic | Conn_01x29
D7 | DS8286D | RFT_Digitalschaltkreise | DS8286D
D4 | DL299D | RFT_Digitalschaltkreise | DL299D
X303 | 8k RAM-Modul | Connector_Generic | Conn_01x29
R406 | 100 | Device | R
R404 | 220 | Device | R_Small
R403 | 220 | Device | R_Small
R402 | 220 | Device | R_Small
R405 | 160 | Device | R_Small
R407 | 75 | Device | R_Small
R408 | 160 | Device | R_Small
R409 | 160 | Device | R_Small
R401 | 51 | Device | R_Small
X401 | DIN-5_180degree | Tiny2k_Bauteile | DIN-5_180degree
D0 | DL253D | RFT_Digitalschaltkreise | DL253D
R26 | 6 | 8k | Device | R_Small
R24 | 2 | 2k | Device | R_Small
VD400 | SAY32 | Device | D_Small
VD401 | SAY32 | Device | D_Small
R22 | 1k | Device | R_Small
R23 | 1k | Device | R_Small
VT400 | SC236 | RFT_Transistoren_und_Dioden | SC236
R25 | 220 | Device | R_Small
C21 | 33pF | Device | C_Small
R19 | 2 | 2k | Device | R_Small
VD402 | SAY32 | Device | D_Small
R17 | 1k | Device | R_Small
R18 | 1k | Device | R_Small
R20 | 220 | Device | R_Small
C16 | 33pF | Device | C_Small
R14 | 2 | 2k | Device | R_Small
VD403 | SAY32 | Device | D_Small
R12 | 1k | Device | R_Small
R13 | 1k | Device | R_Small
R15 | 220 | Device | R_Small
C11 | 33pF | Device | C_Small
R9 | 2 | 2k | Device | R_Small
VD404 | SAY32 | Device | D_Small
R7 | 1k | Device | R_Small
R8 | 1k | Device | R_Small
R10 | 220 | Device | R_Small
R4 | 2 | 2k | Device | R_Small
VD405 | SAY32 | Device | D_Small
R3 | 1k | Device | R_Small
R5 | 220 | Device | R_Small
C6 | 33pF | Device | C_Small
C1 | 33pF | Device | C_Small
VT401 | SC236 | RFT_Transistoren_und_Dioden | SC236
VT402 | SC236 | RFT_Transistoren_und_Dioden | SC236
VT404 | SC236 | RFT_Transistoren_und_Dioden | SC236
VT403 | SC236 | RFT_Transistoren_und_Dioden | SC236
R2 | 1k | Device | R_Small
X405 | 00 | Connector_Generic | Conn_01x01
C2 | 220µF/16V | Device | CP_Small
C3 | 100nF | Device | C_Small
C12 | 22nF | Device | C_Small
C13 | 22nF | Device | C_Small
C14 | 22nF | Device | C_Small
C15 | 22nF | Device | C_Small
C17 | 22nF | Device | C_Small
C18 | 22nF | Device | C_Small
C4 | 22nF | Device | C_Small
C5 | 22nF | Device | C_Small
C7 | 22nF | Device | C_Small
C8 | 22nF | Device | C_Small
C9 | 22nF | Device | C_Small
C10 | 22nF | Device | C_Small
C19 | 100nF | Device | C_Small
C22 | 100nF | Device | C_Small
C20 | 22nF | Device | C_Small
C24 | 22nF | Device | C_Small
JP507 | B | Device | Jumper_NO_Small
JP506 | SYN | Device | Jumper_NO_Small
JP502 | V | Device | Jumper_NO_Small
JP504 | HR_low | Device | Jumper_NO_Small
JP501 | HR_high | Device | Jumper_NO_Small
JP503 | HR_P34 | Device | Jumper_NO_Small
JP505 | W | Device | Jumper_NO_Small
R501 | 3 | 3k | Device | R_Small
TP400 | V | Connector | TestPoint_Small
TP401 | B | Connector | TestPoint_Small
TP402 | S | Connector | TestPoint_Small
TP403 | G | Connector | TestPoint_Small
TP404 | R | Connector | TestPoint_Small
C23 | 47µF/10V | Device | CP_Small

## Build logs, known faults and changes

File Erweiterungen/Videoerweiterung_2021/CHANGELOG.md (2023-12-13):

# Changelog

## 13.12.2023

* Verbindung zwischen Signal 'b' und R18 getrennt

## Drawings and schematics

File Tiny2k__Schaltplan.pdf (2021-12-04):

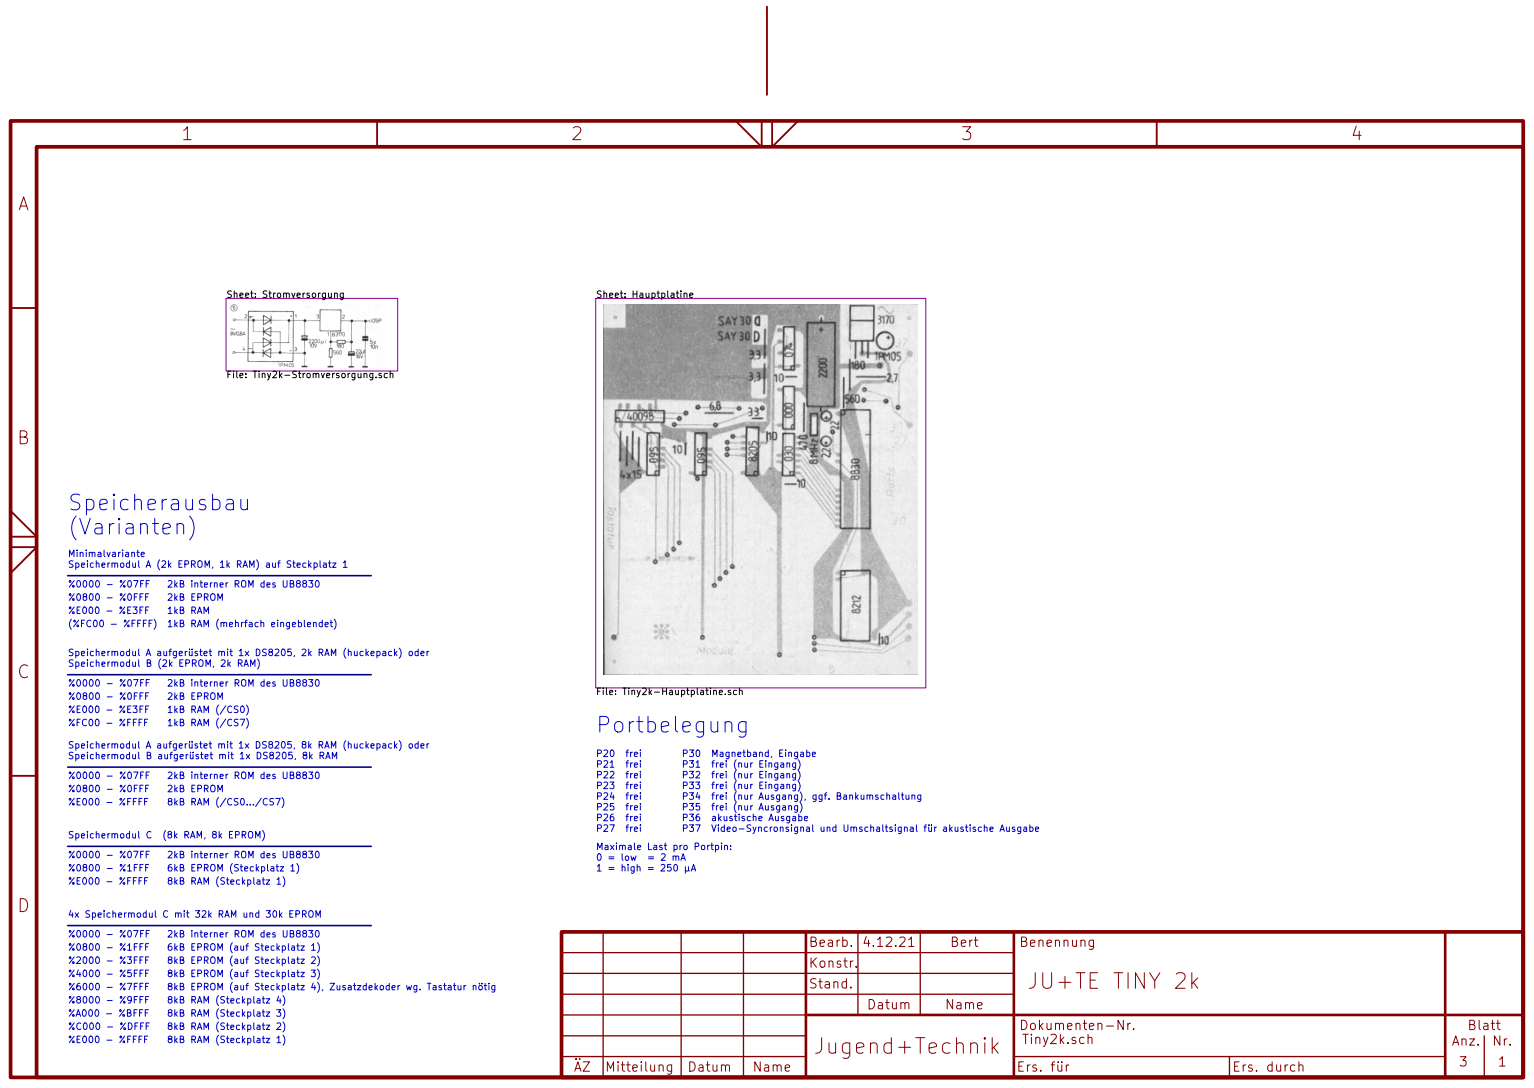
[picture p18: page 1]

Speichermodul A aufgerüstet mit 1x DS8205, 2k RAM (huckepack) oder

File: Tiny2k-Hauptplatine.sch %E000 - %FFFF %E000 - %FFFF

Speichermodul A aufgerüstet mit 1x DS8205, 8k RAM (huckepack) oder

P30 Magnetband, Eingabe
P31 frei (nur Eingang)
P32 frei (nur Eingang)
P33 frei (nur Eingang)
P34 frei (nur Ausgang), ggf. Bankumschaltung
P35 frei (nur Ausgang)
P36 akustische Ausgabe
P37 Video-Syncronsignal und Umschaltsignal für akustische Ausgabe

Maximale Last pro Portpin: 0 = low = 2 mA

Datum | Name

Dokumenten-Nr. | | Blatt

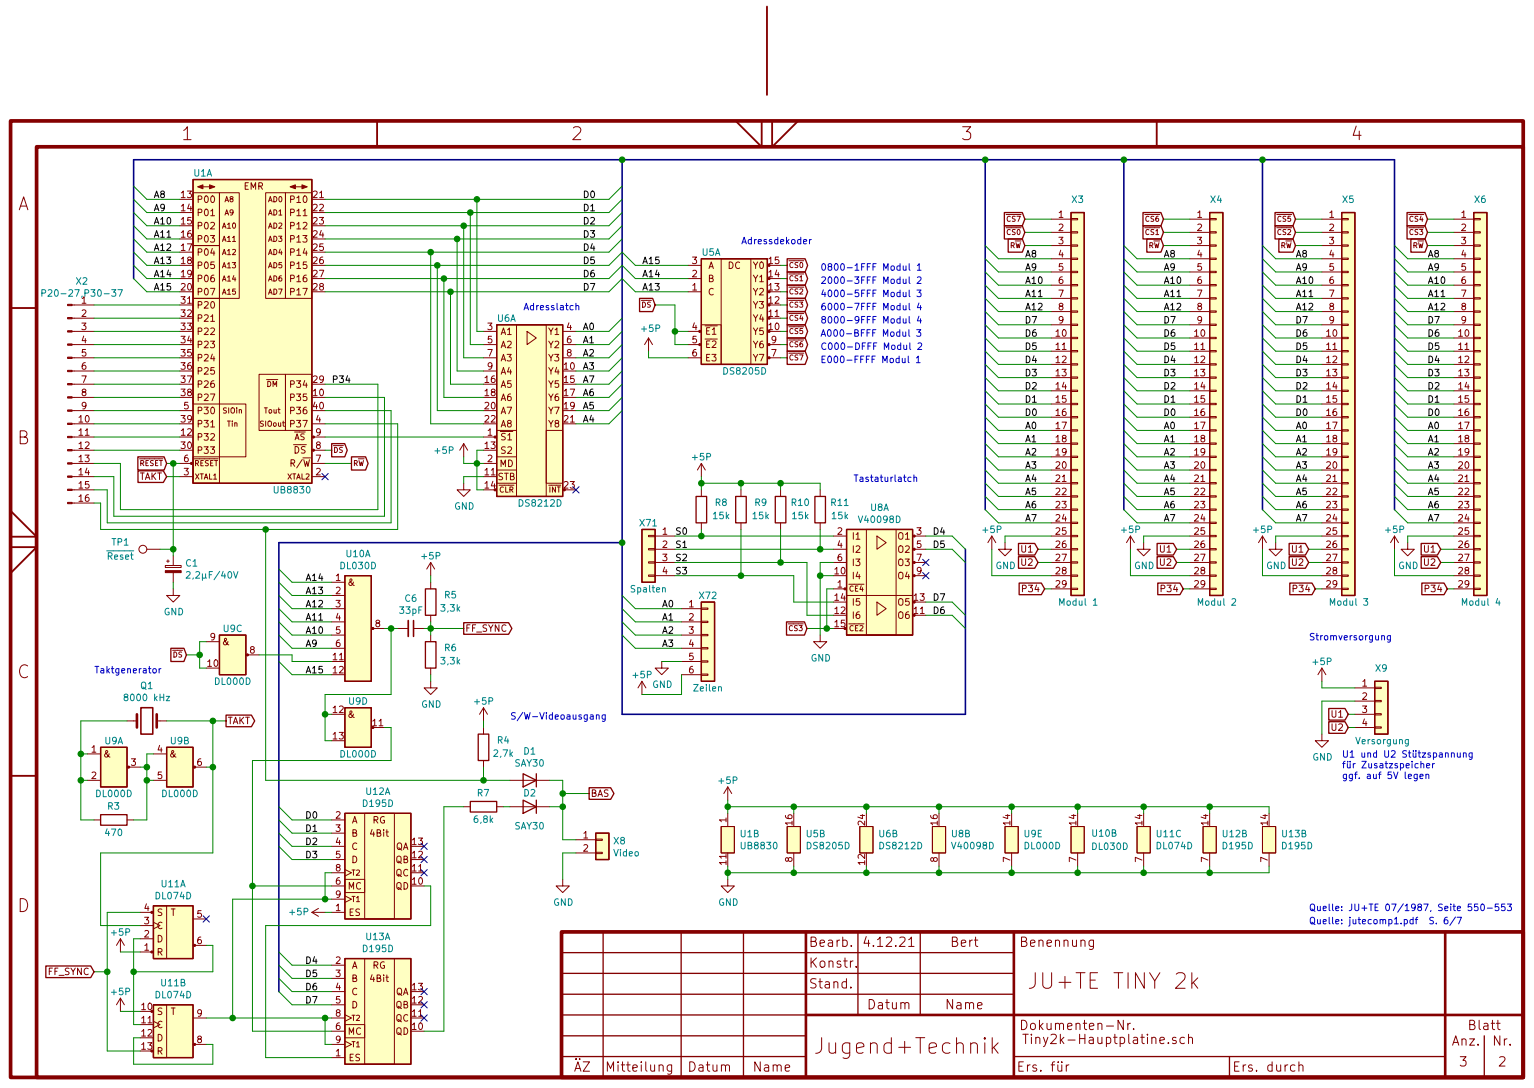
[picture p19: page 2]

0800-1FFF Modul 1 C000-DFFF Modul 2 S/W-Videoausgang

I5
12 | | 11

BC ESMC D | 4Bit A RG | QAQBQCQD

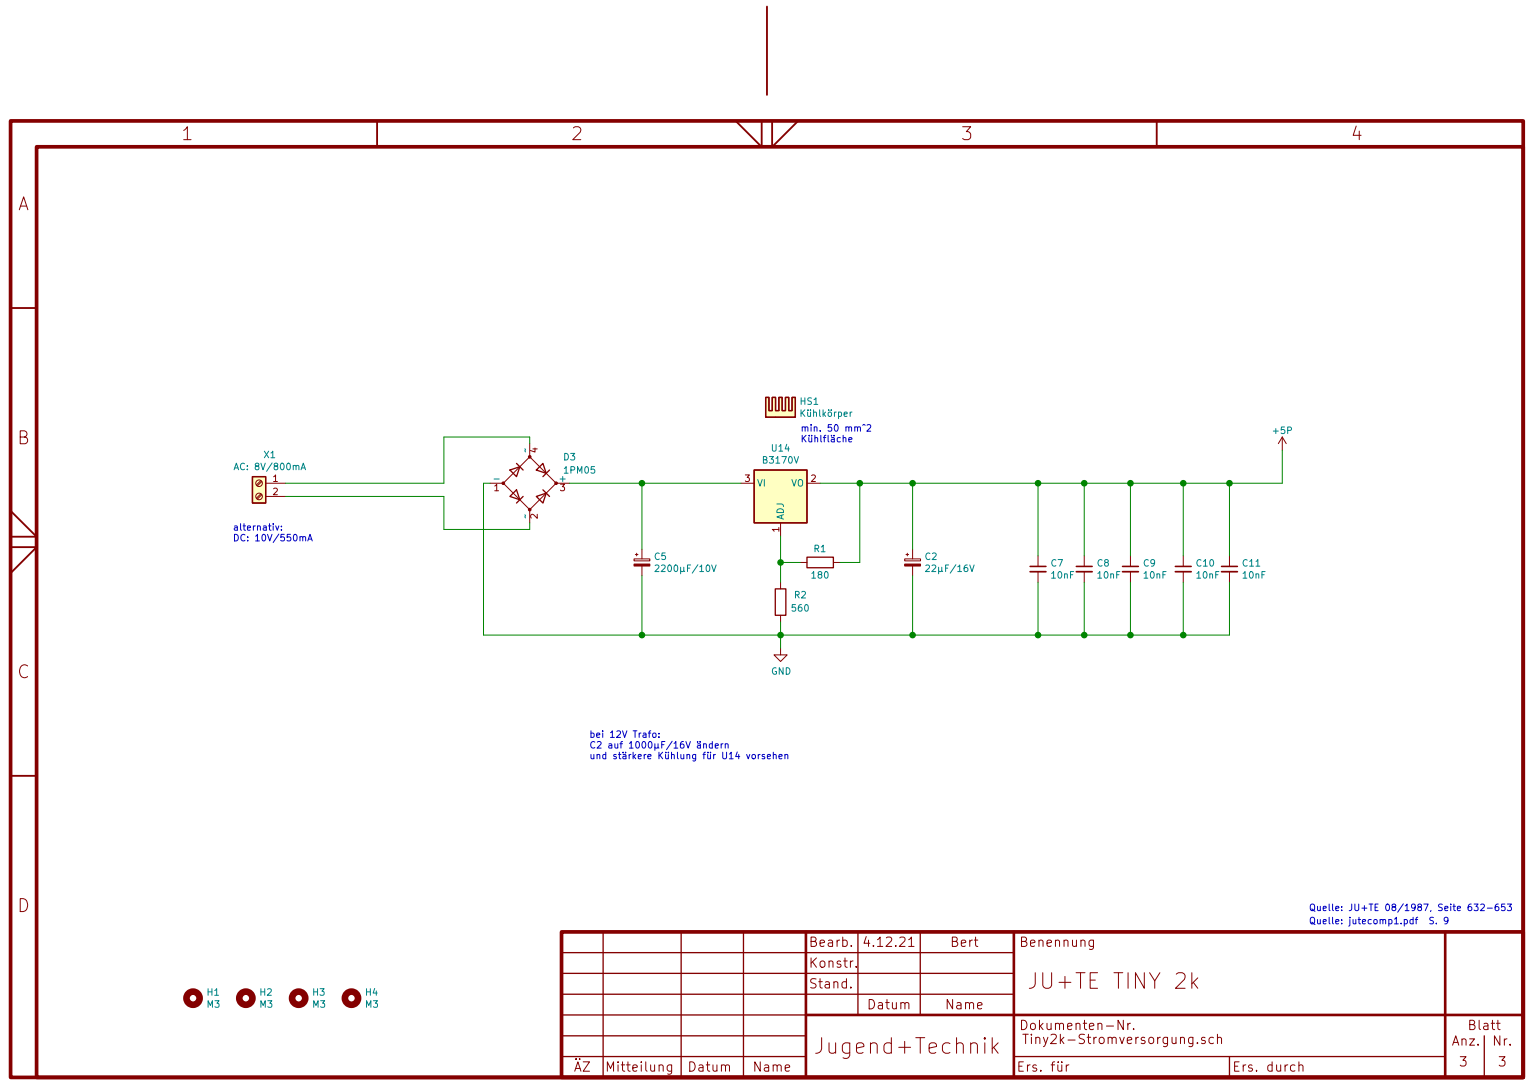
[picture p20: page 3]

bei 12V Trafo: C2 auf 1000µF/16V ändern

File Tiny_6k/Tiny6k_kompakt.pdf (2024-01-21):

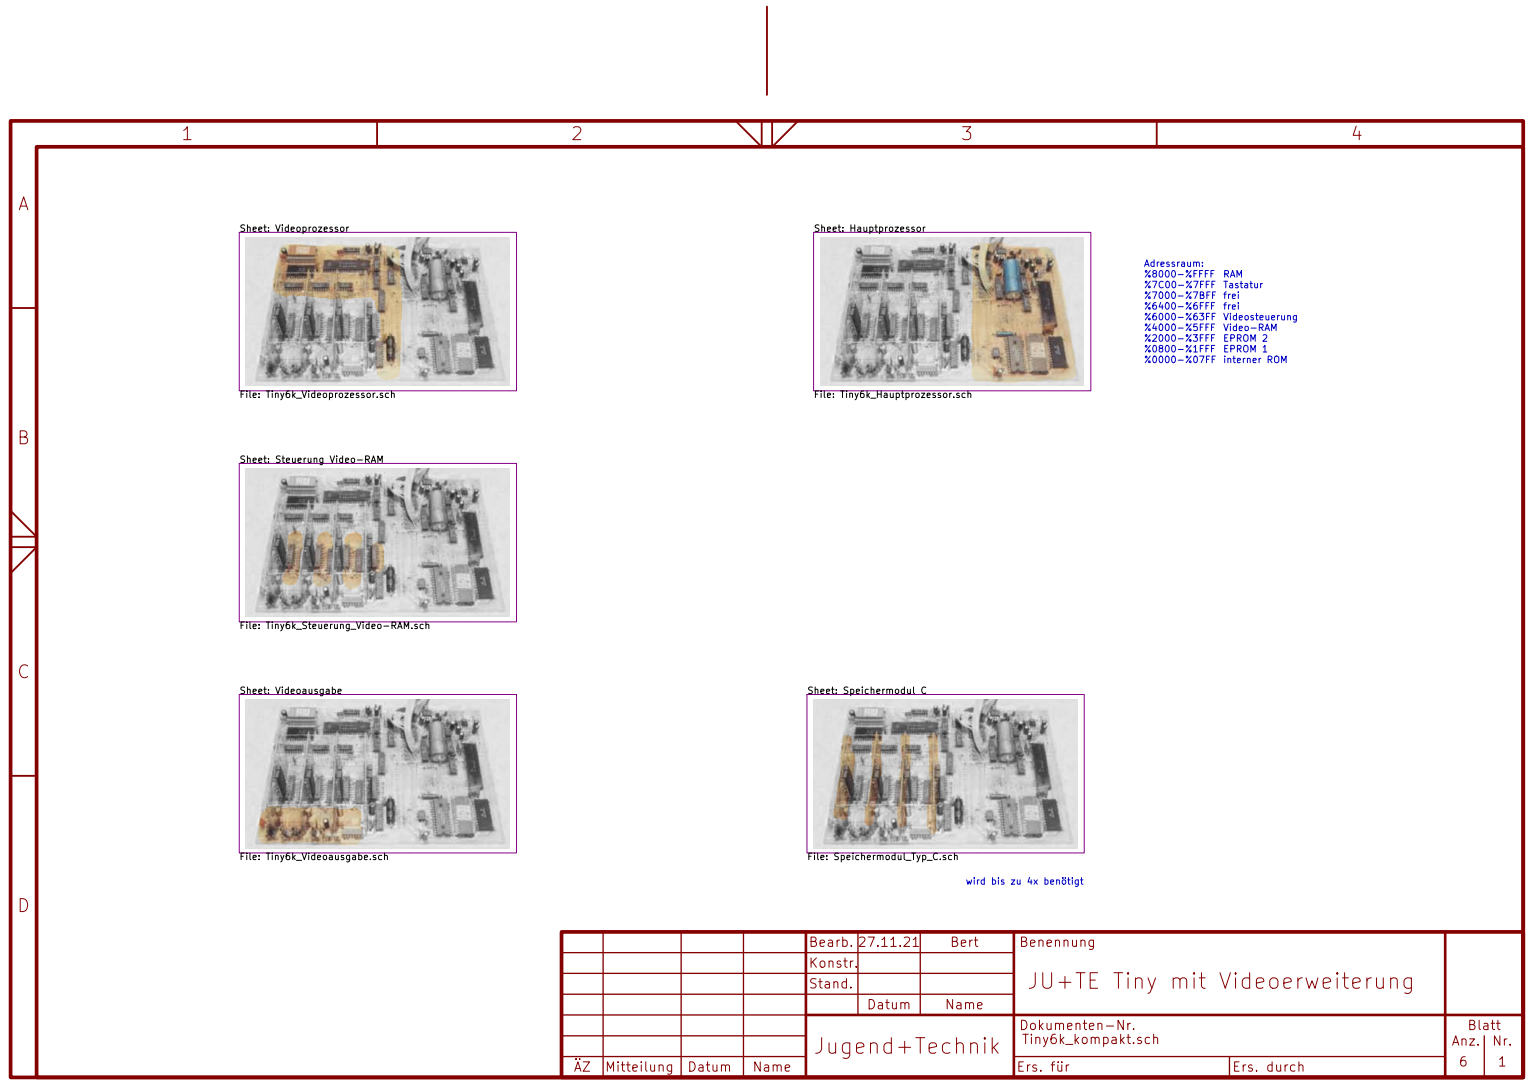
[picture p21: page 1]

Tastatur
frei frei Videosteuerung Video-RAM

Sheet: Steuerung Video-RAM

wird bis zu 4x benötigt

Benennung
JU+TE Tiny mit Videoerweiterung

Datum | Name

Dokumenten-Nr. | | Blatt

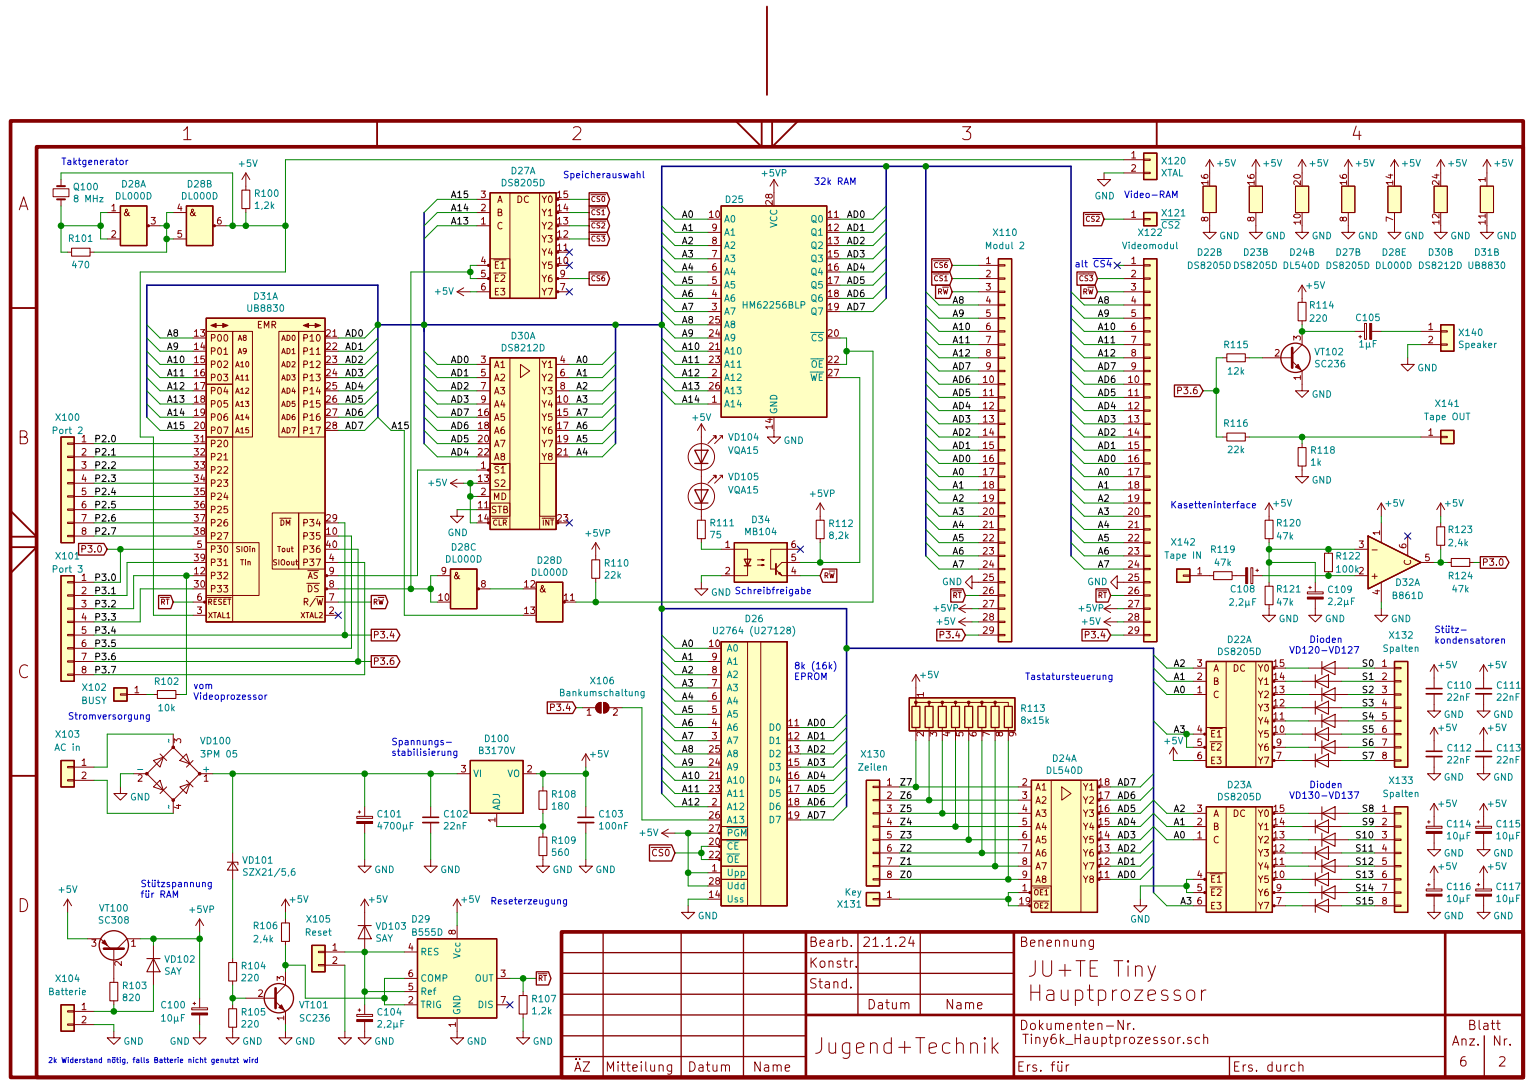
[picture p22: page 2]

Y1Y2Y3Y4Y5Y6Y7Y8 CLR INT S1 1

2 | 32
3 | 33
4 | 34 | 13

22k GND
2k Widerstand nötig, falls Batterie nicht genutzt wird Stromversorgung

Upp 1 A0 10 CE 20 A10 21 OE 22 A11 23 A9 24 A8 25 A13 26 PGM 27 Udd 28 A7 3 A6 4 A5 5 A4 6 A3 7 A2 8 A1 9 | D26 U2764 (U27128) | D0 D3 | 11 D1 12 D2 13 Uss 14 15 D4 16 D5 17 D6 18 D7 19 A12 2

3 | 4 | 16
4 | 5 | 15
5 | 6 | 14
6 | 7 | 13
7 | 8 | 12

1 TRIG 2 OUT 3 RES 4 Ref 5 COMP 6 DIS 7 Vcc 8 D29 B555D

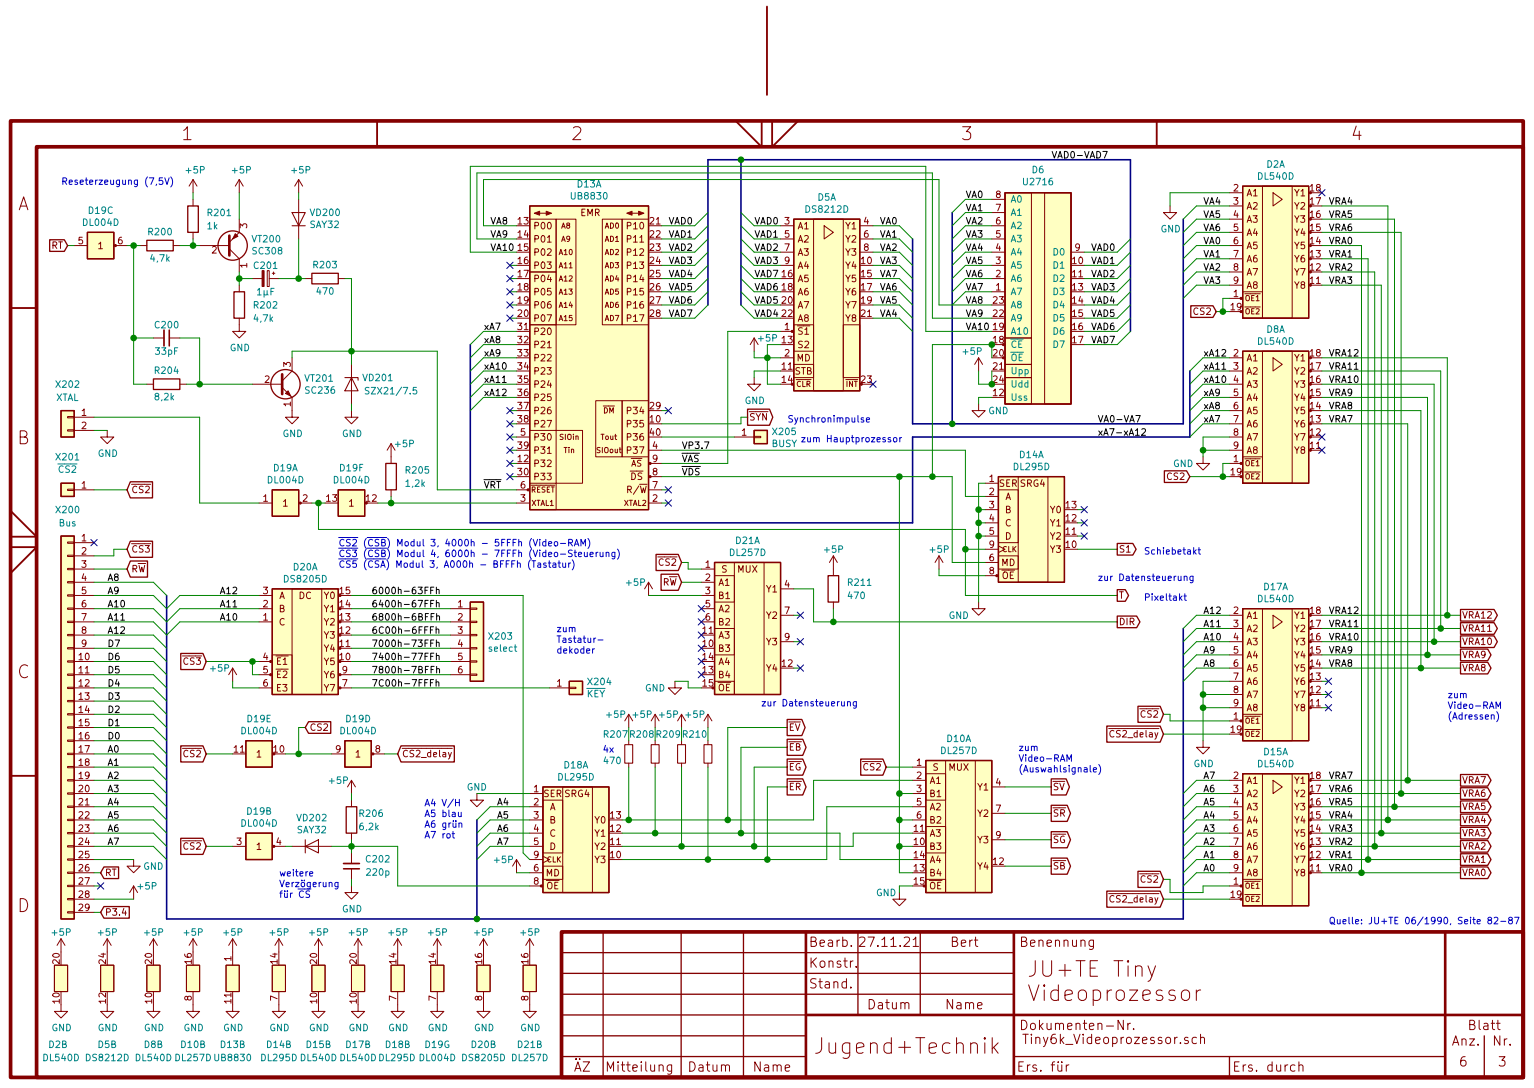
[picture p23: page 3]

CS3 (CSB) Modul 4, 6000h - 7FFFh (Video-Steuerung)
CS5 (CSA) Modul 3, A000h - BFFFh (Tastatur)

1 11 D13B UB8830 12 24 D5B DS8212D GND GND GND GND

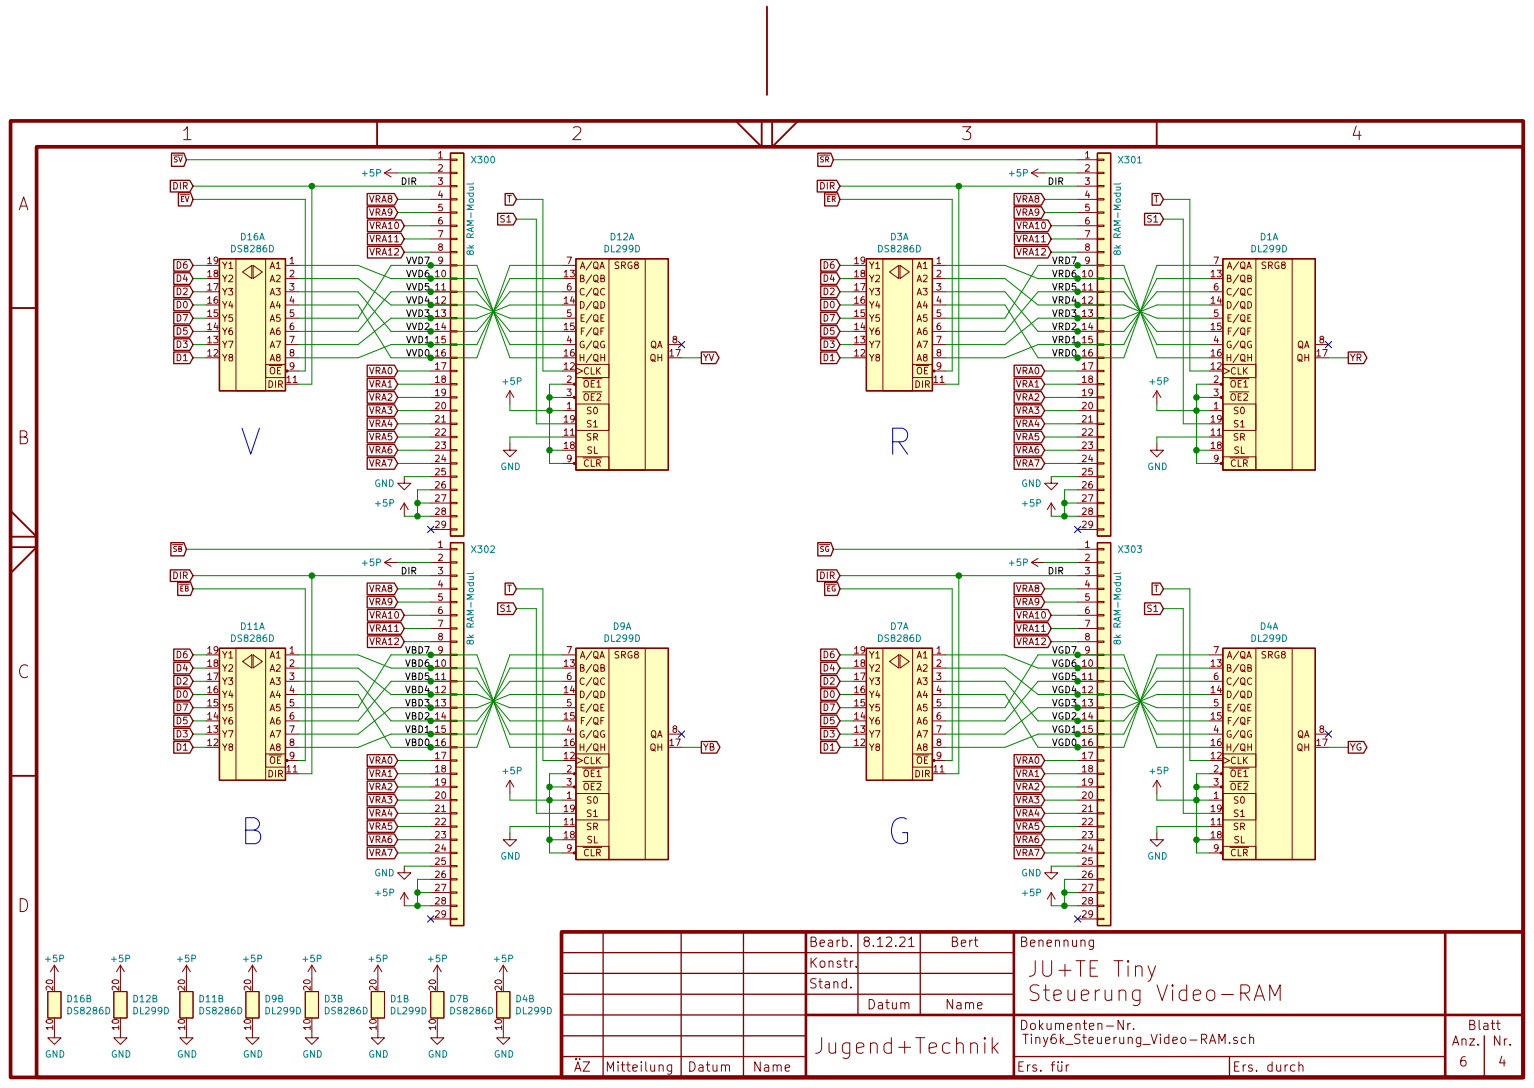
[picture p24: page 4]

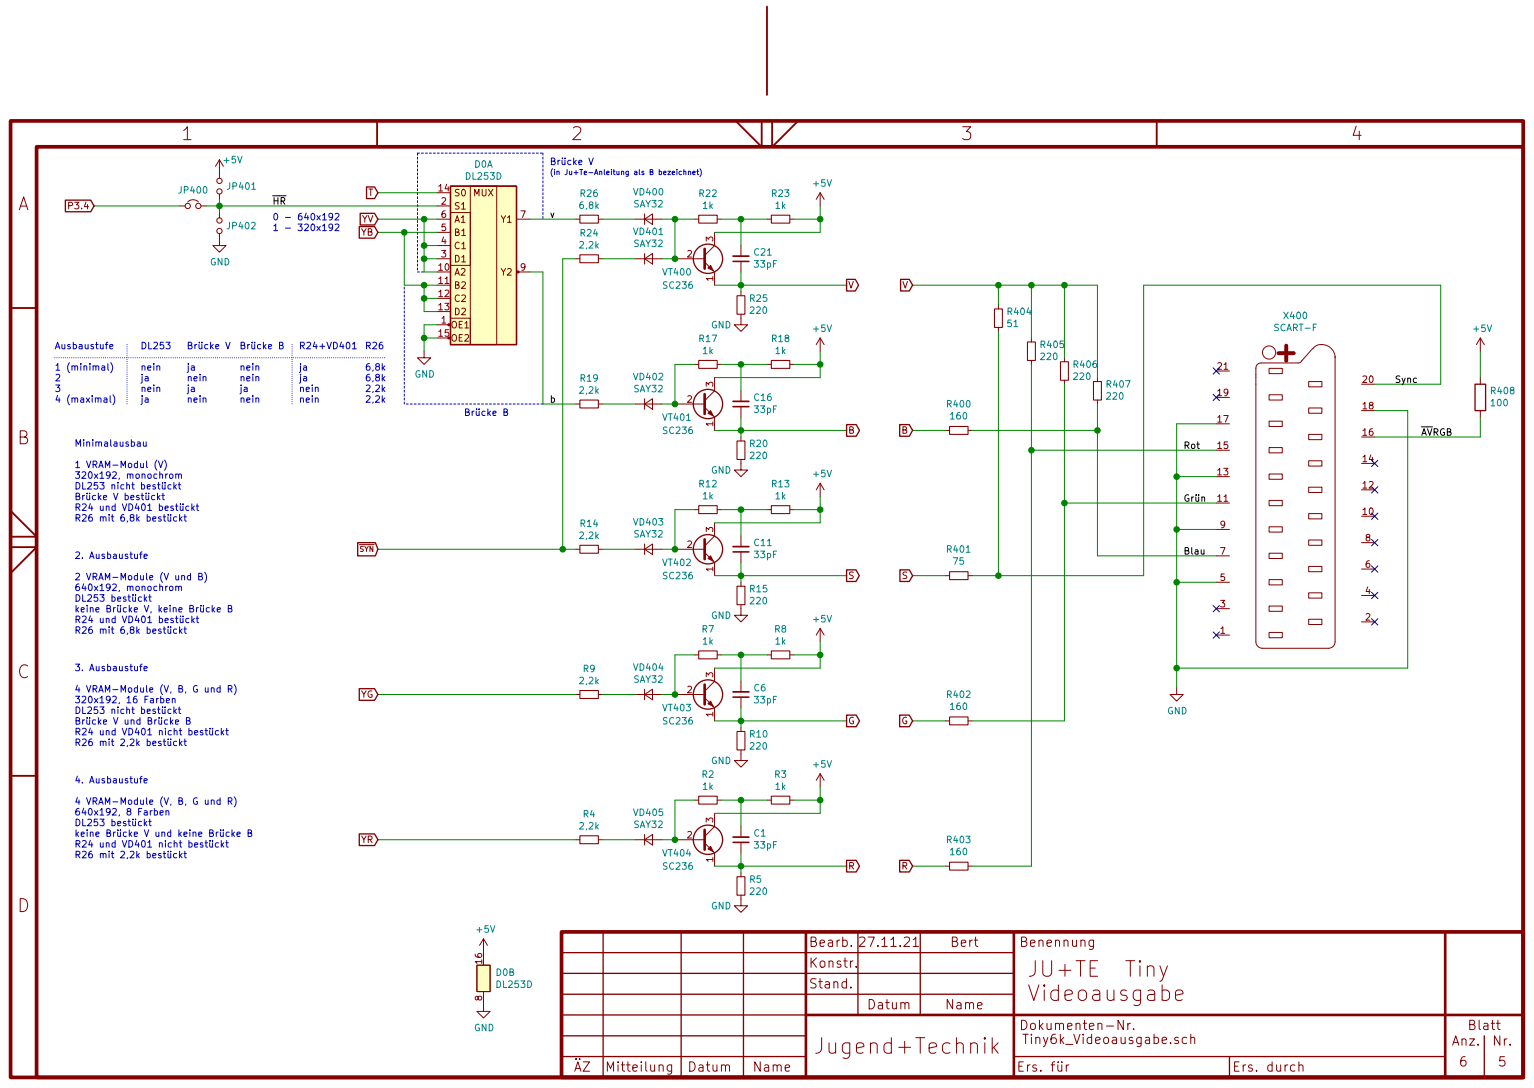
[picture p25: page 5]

(in Ju+Te-Anleitung als B bezeichnet) R26

DL253 nicht bestückt Brücke V bestückt R24 und VD401 bestückt R26 mit 6,8k bestückt

2 VRAM-Module (V und B) 640x192, monochrom

4 VRAM-Module (V, B, G und R) 320x192, 16 Farben DL253 nicht bestückt Brücke V und Brücke B R24 und VD401 nicht bestückt R26 mit 2,2k bestückt

4 VRAM-Module (V, B, G und R) 640x192, 8 Farben DL253 bestückt keine Brücke V und keine Brücke B R24 und VD401 nicht bestückt R26 mit 2,2k bestückt

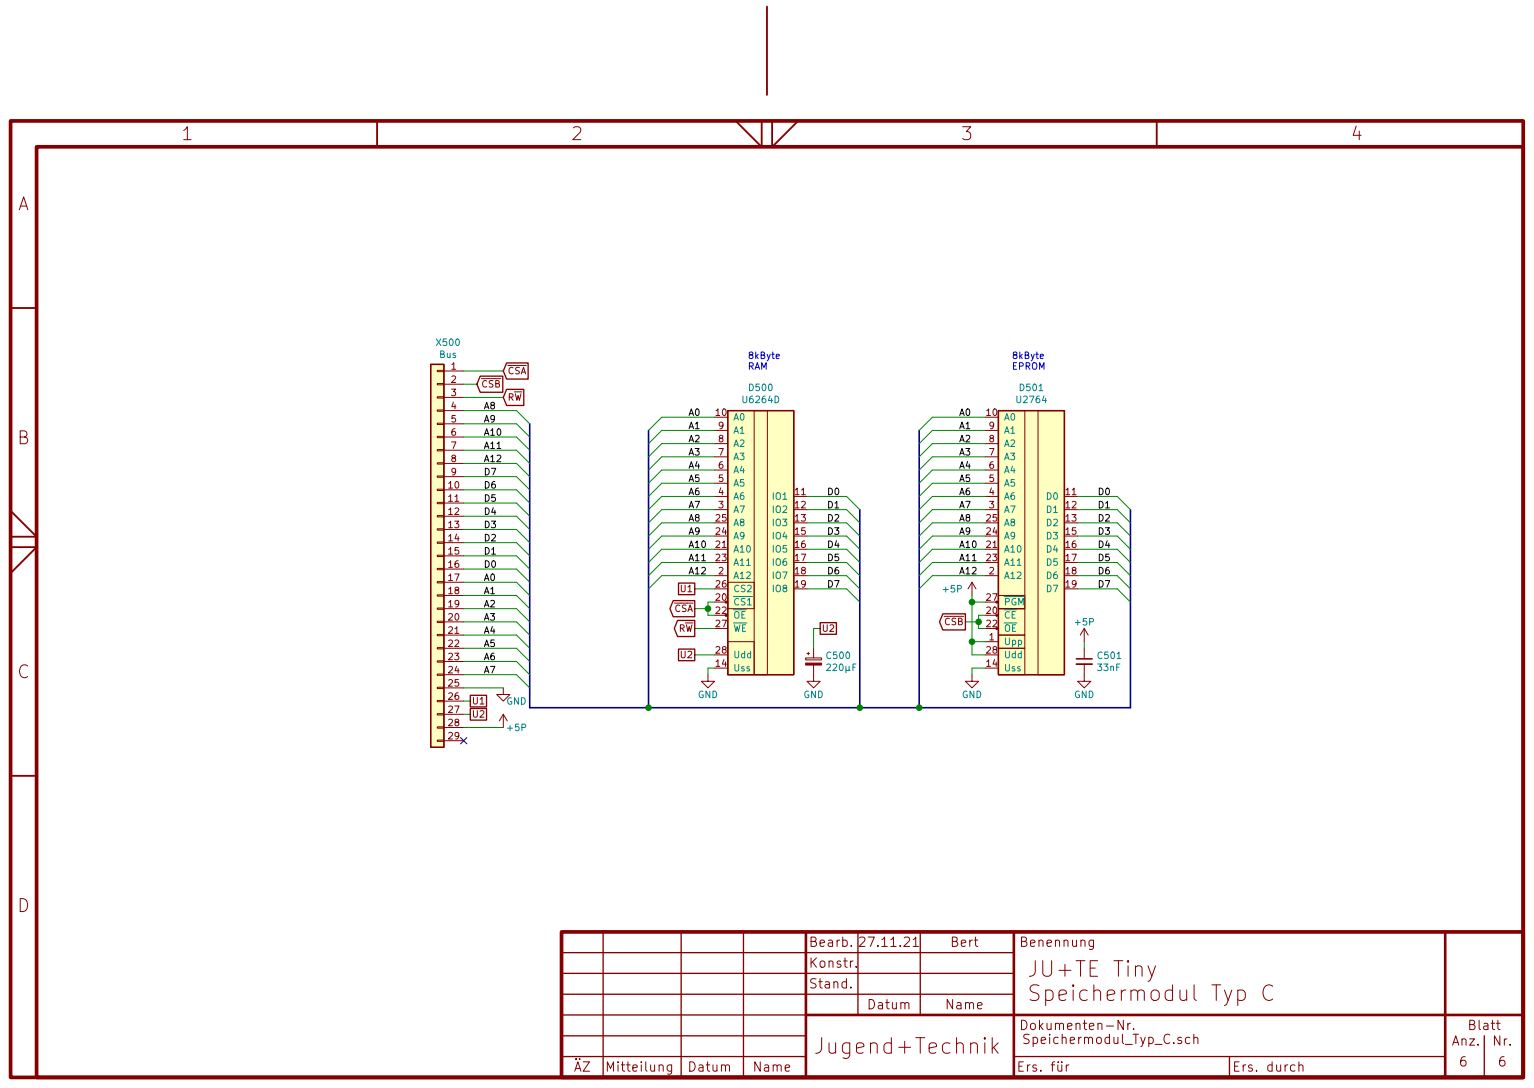
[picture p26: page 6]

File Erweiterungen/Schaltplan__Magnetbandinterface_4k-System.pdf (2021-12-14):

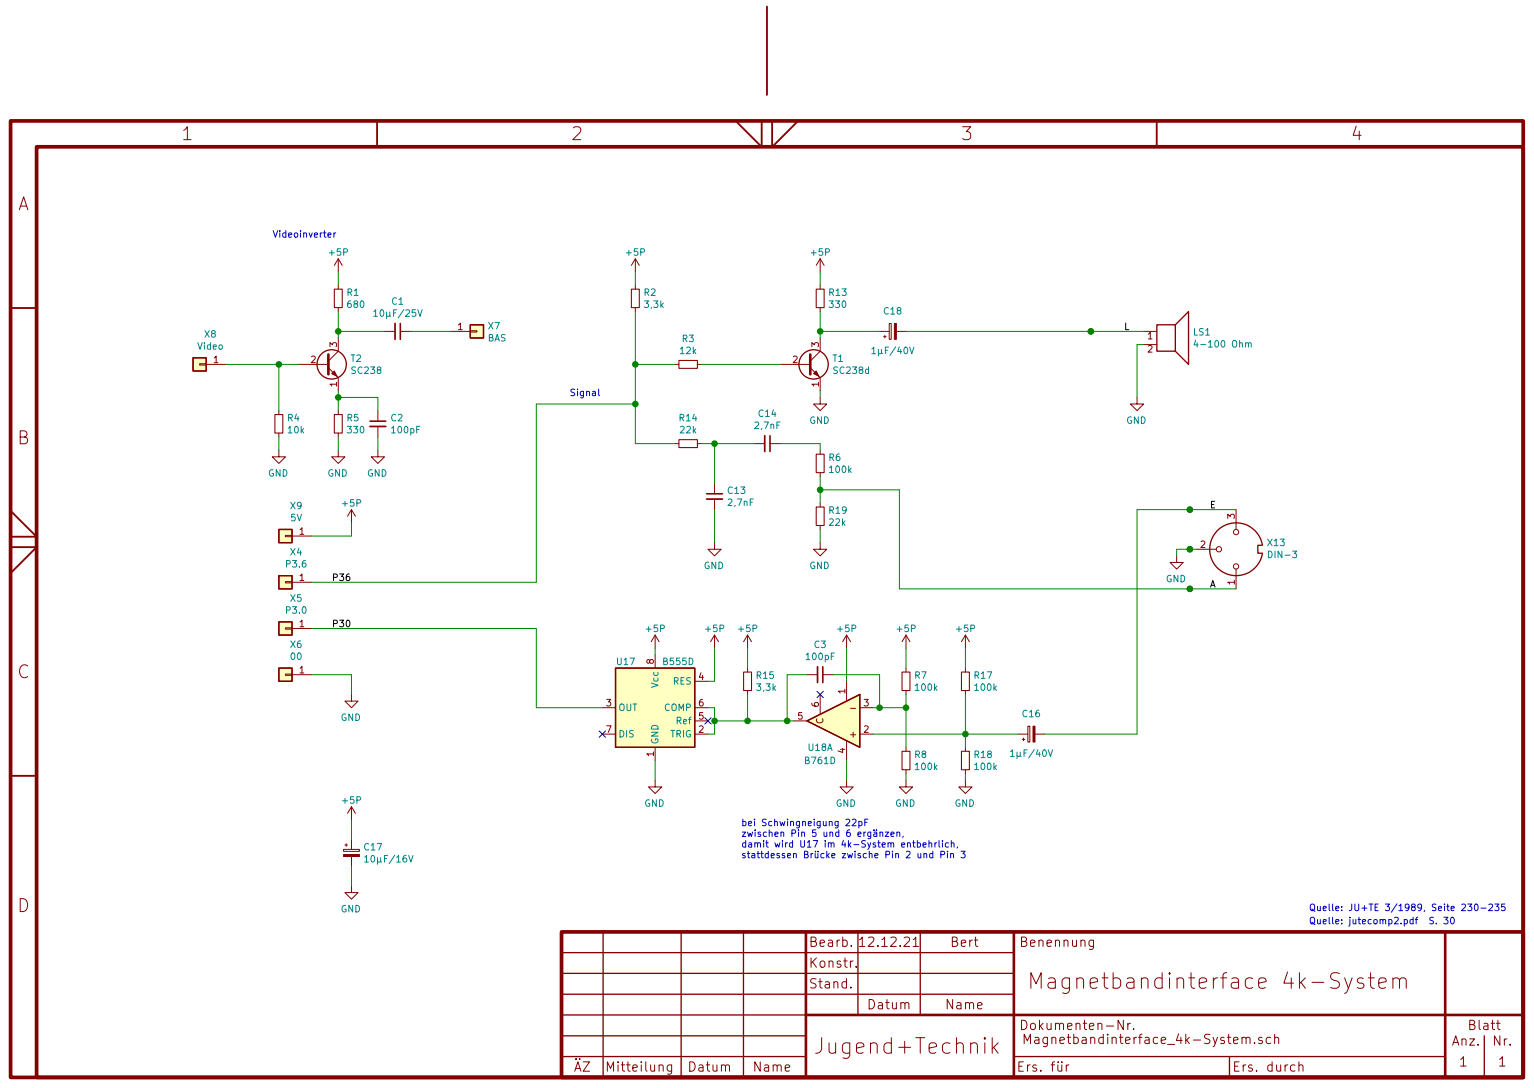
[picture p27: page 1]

1 TRIG 2 OUT 3 RES 4 Ref 5 COMP 6 DIS 7 Vcc U17 8B555D GND

bei Schwingneigung 22pF
zwischen Pin 5 und 6 ergänzen,

Datum | Name

Dokumenten-Nr. | | Blatt

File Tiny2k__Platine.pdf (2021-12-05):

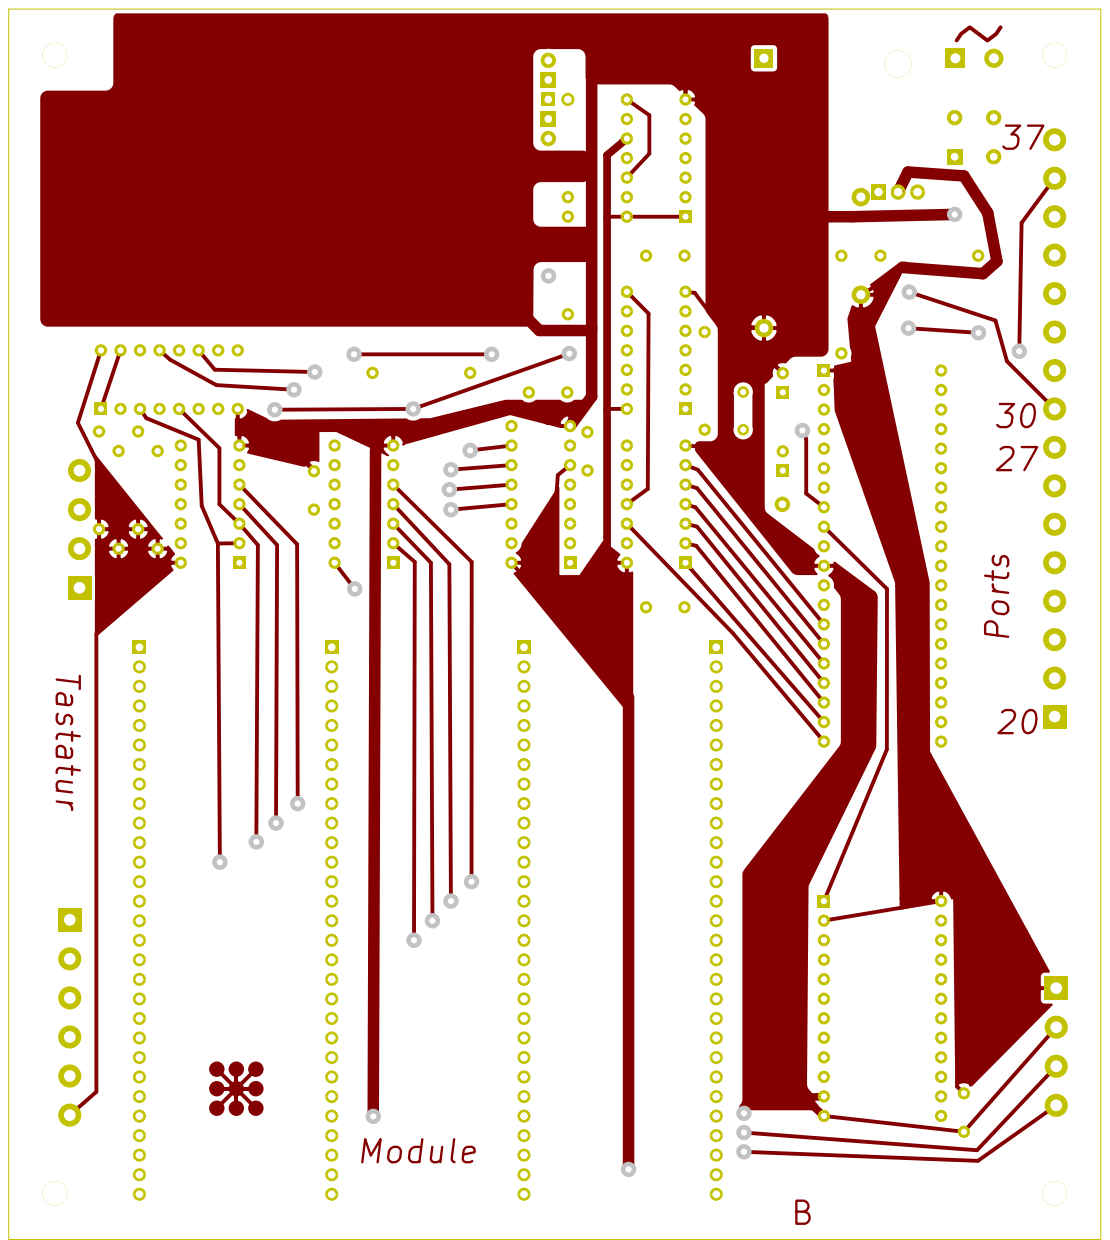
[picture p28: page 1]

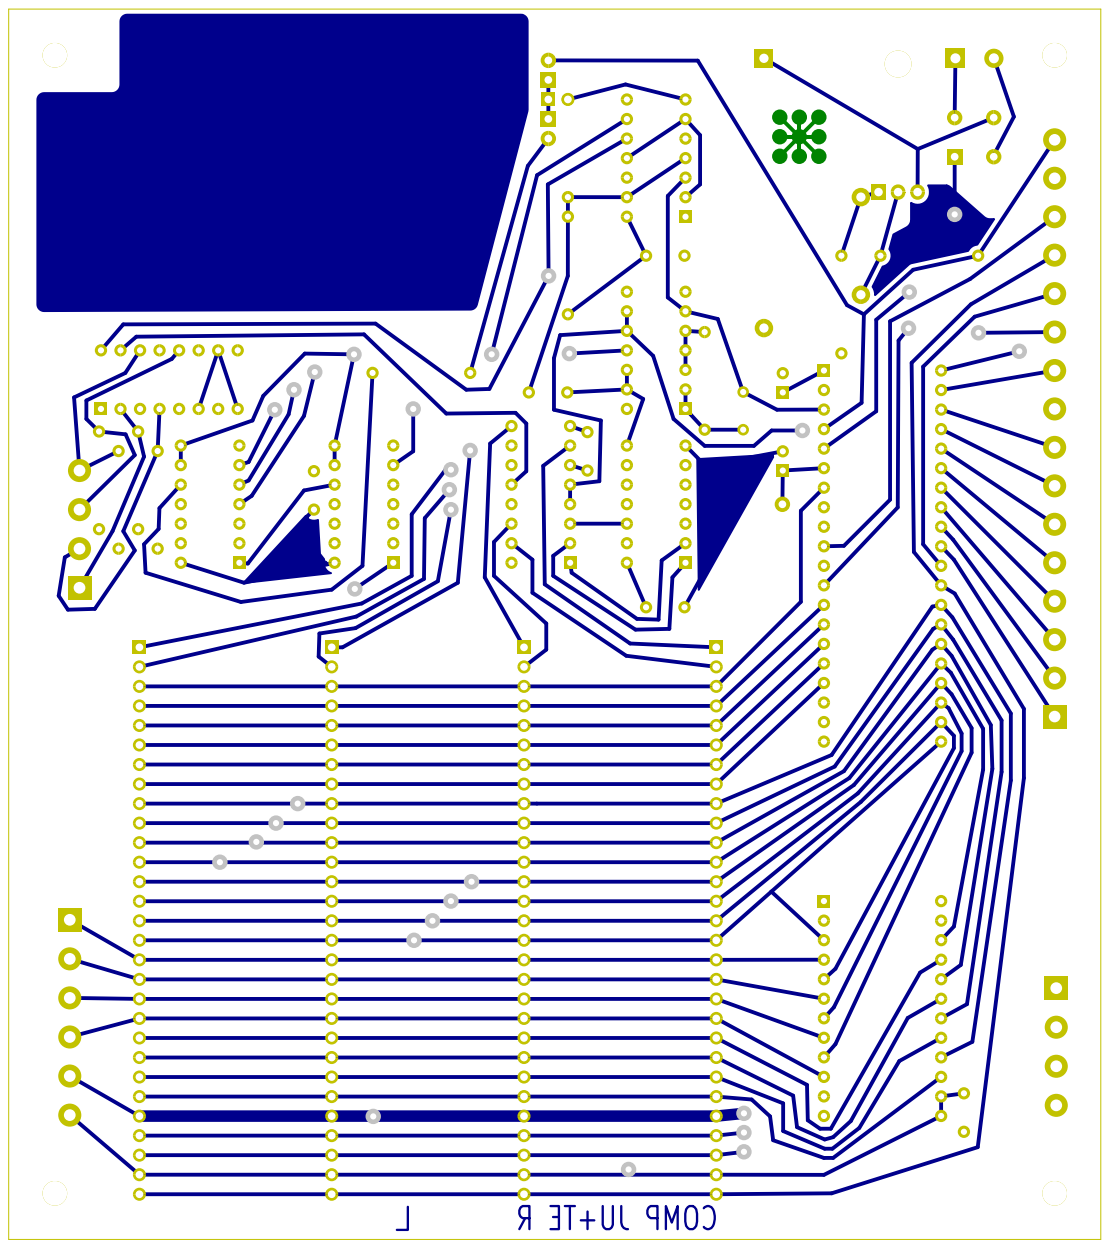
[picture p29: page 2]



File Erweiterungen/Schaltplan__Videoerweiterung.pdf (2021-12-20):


Sheet: Steuerung Video-RAM

Datum | Name

Dokumenten-Nr. | | Blatt


CS2 (CSB) Modul 3, 4000h - 5FFFh (Video-RAM)
CS3 (CSB) Modul 4, 6000h - 7FFFh (Video-Steuerung)



(in Ju+Te-Anleitung als B bezeichnet) 0 - 640x192

Brücke B DL253
DL253 nicht bestückt Brücke V bestückt R24 und VD401 bestückt R26 mit 6,8k bestückt 4. Ausbaustufe

4 VRAM-Module (V, B, G und R) 320x192, 16 Farben DL253 nicht bestückt Brücke V und Brücke B R24 und VD401 nicht bestückt R26 mit 2,2k bestückt 2. Ausbaustufe

2 VRAM-Module (V und B) 640x192, monochrom

DL253 bestückt keine Brücke V, keine Brücke B R24 und VD401 bestückt R26 mit 6,8k bestückt

4 VRAM-Module (V, B, G und R) 640x192, 8 Farben DL253 bestückt keine Brücke V und keine Brücke B R24 und VD401 nicht bestückt R26 mit 2,2k bestückt 3. Ausbaustufe

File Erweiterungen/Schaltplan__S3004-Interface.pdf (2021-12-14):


Datum | Name

Dokumenten-Nr. | | Blatt



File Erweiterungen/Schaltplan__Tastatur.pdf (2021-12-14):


SW13 CUL/CUR | 1 SW37 Space SW14 Q | 2 SW38 Y SW15 W | 3 SW39 X SW16 E | 4 SW40 C SW29 F SW17 R | 5 SW41 V | 6 SW42 B | 7 SW43 N J SW20 U | 8 SW44 M SW21 | SW10 L SW22 O | 0 SW46 > SW34 * SW23 P

SW25 Shift C12 | | | | | | | | | | SW47

Datum | Name

Dokumenten-Nr. | | Blatt

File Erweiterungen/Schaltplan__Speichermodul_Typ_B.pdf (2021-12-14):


bis auf 4 Schaltkreise erweiterbar Huckepack, CS/OE jeweils mit einem select verbinden

Datum | Name

Dokumenten-Nr. | | Blatt




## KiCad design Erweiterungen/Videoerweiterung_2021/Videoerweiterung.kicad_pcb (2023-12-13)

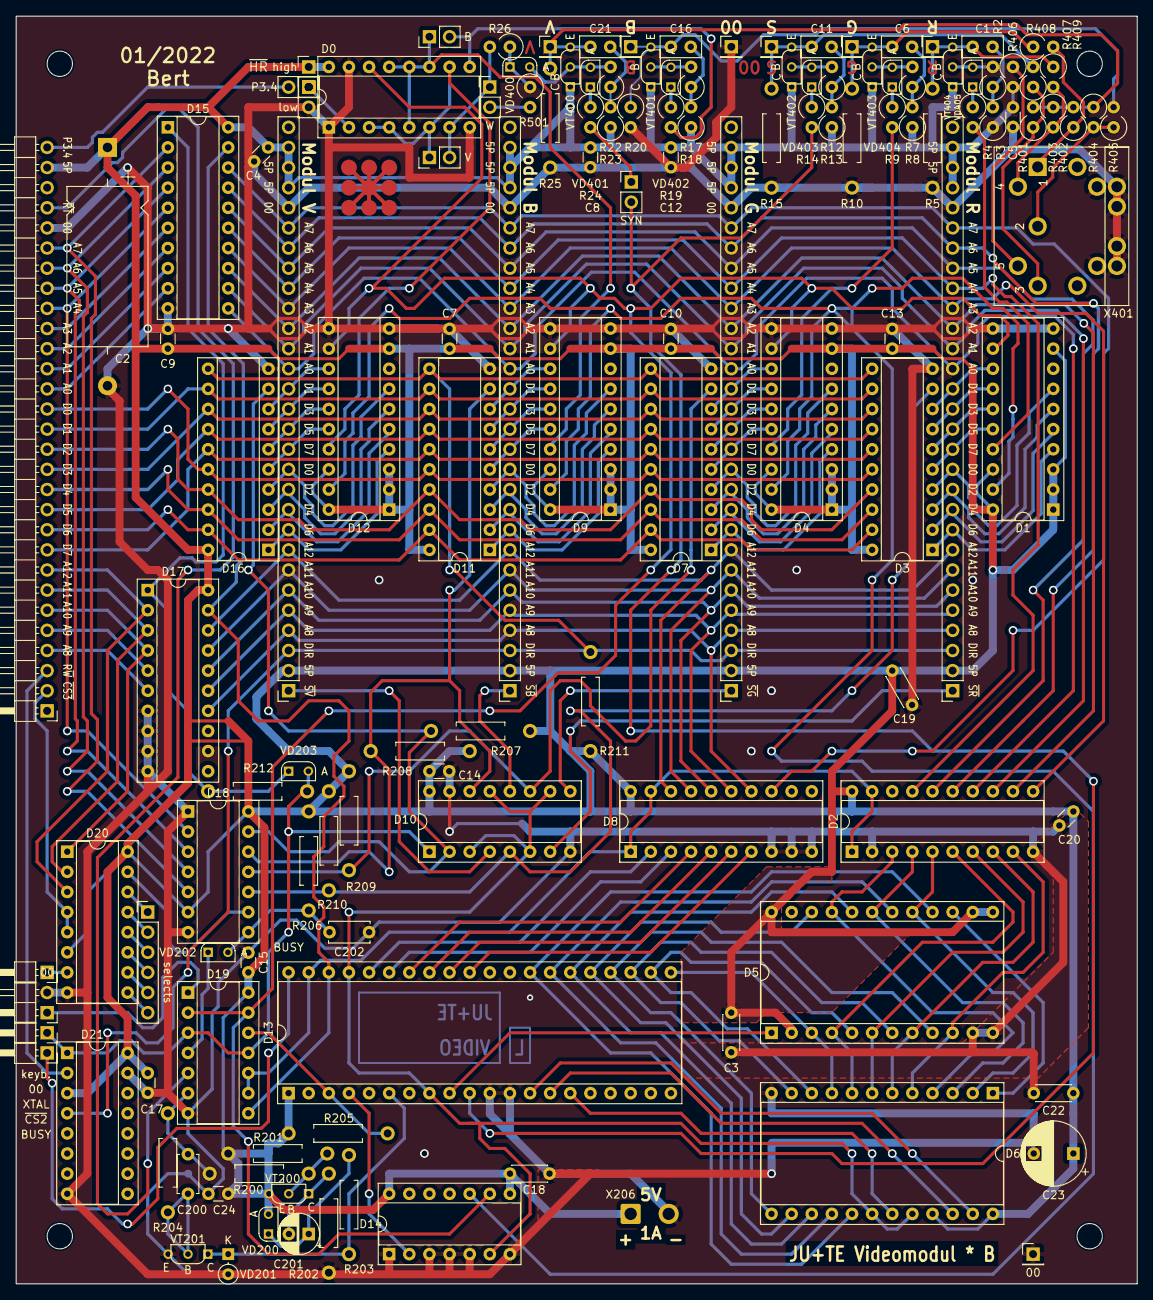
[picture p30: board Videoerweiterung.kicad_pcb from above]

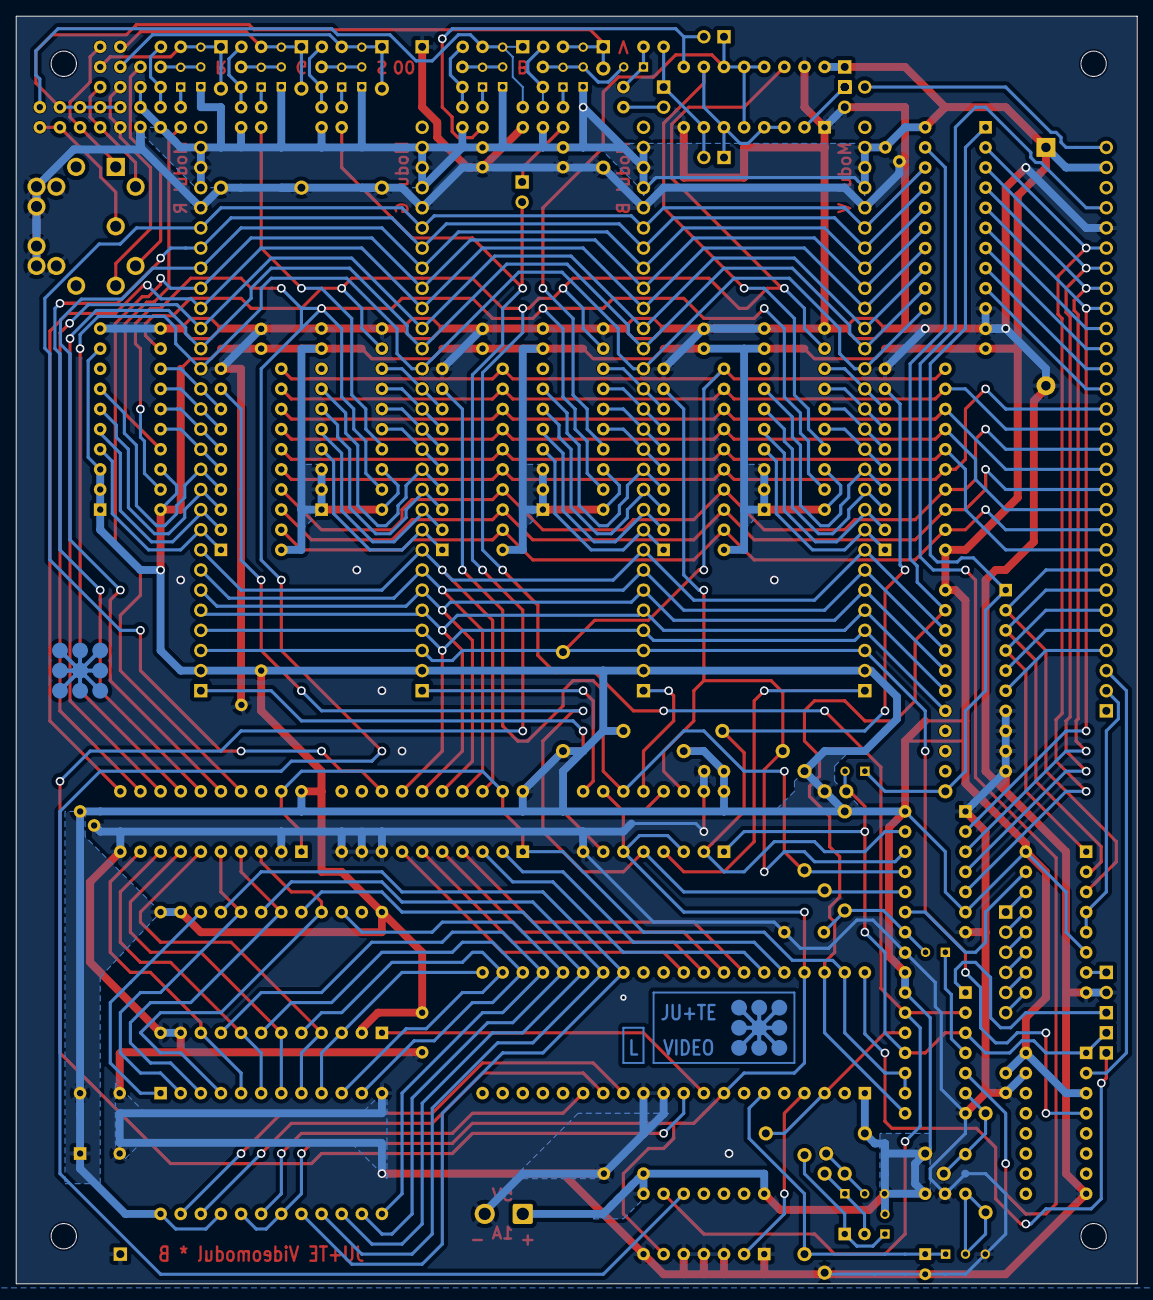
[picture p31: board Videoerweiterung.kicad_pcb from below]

Board: 2 copper layers, 141.5 x 160.0 mm, 143 parts (2 on the bottom side), 170 nets.

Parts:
C1, C6, C11, C16, C21: 33pF; C_Disc_D5.0mm_W2.5mm_P2.50mm
C2: 220µF/16V; CP_Axial_L25.0mm_D10.0mm_P30.00mm_Horizontal
C3, C19, C22: 100nF; C_Disc_D4.3mm_W1.9mm_P5.00mm
C4, C5, C7, C8, C9, C10, C12, C13, C14, C15, C17, C20, C24: 22nF; C_Disc_D3.0mm_W1.6mm_P2.50mm
C18: 22nF; C_Disc_D4.3mm_W1.9mm_P5.00mm
C23: 47µF/10V; CP_Radial_D8.0mm_P5.00mm
C200: 33pF; C_Disc_D4.7mm_W2.5mm_P5.00mm
C201: 1µF; CP_Radial_D5.0mm_P2.50mm
C202: 220p; C_Disc_D5.0mm_W2.5mm_P5.00mm
D0: DL253D; DIP-16_W7.62mm_Socket
D1, D4, D9, D12: DL299D; DIP-20_W7.62mm_Socket
D2, D8, D15, D17: DL540D; DIP-20_W7.62mm_Socket
D3, D7, D11, D16: DS8286D; DIP-20_W7.62mm_Socket
D5: DS8212D; DIP-24_W15.24mm_Socket
D6: U2716; DIP-24_W15.24mm_Socket
D10, D21: DL257D; DIP-16_W7.62mm_Socket
D13: UB8860; DIP-40_W15.24mm_Socket
D14, D18: DL295D; DIP-14_W7.62mm_Socket
D19: DL004D; DIP-14_W7.62mm_Socket
D20: DS8205D; DIP-16_W7.62mm_Socket
H1, H2, H3, H4: MountingHole; MountingHole_3.2mm_M3_DIN965
JP501: HR_high; PinHeader_1x02_P2.54mm_Vertical
JP502: V; PinHeader_1x02_P2.54mm_Vertical
JP503: HR_P34; PinHeader_1x02_P2.54mm_Vertical
JP504: HR_low; PinHeader_1x02_P2.54mm_Vertical
JP505: W; PinHeader_1x02_P2.54mm_Vertical
JP506: SYN; PinHeader_1x02_P2.54mm_Vertical
JP507: B; PinHeader_1x02_P2.54mm_Vertical
LOGO1, LOGO2, LOGO2#2: jute_pcb_logo
R2, R3, R7, R8, R12, R13, R17, R18, R22, R23: 1k; R_Axial_DIN0309_L9.0mm_D3.2mm_P2.54mm_Vertical
R4, R9, R14, R19, R24: 2,2k; R_Axial_DIN0309_L9.0mm_D3.2mm_P2.54mm_Vertical
R5, R10, R15, R25: 220; R_Axial_TGL8728_L5.9mm_D2.4mm_P12.50mm_Horizontal
R20, R402, R403, R404: 220; R_Axial_DIN0309_L9.0mm_D3.2mm_P2.54mm_Vertical
R26: 6,8k; R_Axial_DIN0309_L9.0mm_D3.2mm_P2.54mm_Vertical
R200, R202: 4,7k; R_Axial_TGL8728_L5.9mm_D2.4mm_P12.50mm_Horizontal
R201: 1k; R_Axial_TGL8728_L5.9mm_D2.4mm_P12.50mm_Horizontal
R203, R207, R208, R209, R210, R211: 470; R_Axial_TGL8728_L5.9mm_D2.4mm_P12.50mm_Horizontal
R204: 8,2k; R_Axial_TGL8728_L5.9mm_D2.4mm_P12.50mm_Horizontal
R205: 1,2k; R_Axial_TGL8728_L5.9mm_D2.4mm_P12.50mm_Horizontal
R206: 6,2k; R_Axial_TGL8728_L5.9mm_D2.4mm_P12.50mm_Horizontal
R212: 1,5k; R_Axial_TGL8728_L5.9mm_D2.4mm_P12.50mm_Horizontal
R401: 51; R_Axial_DIN0309_L9.0mm_D3.2mm_P2.54mm_Vertical
R405, R408, R409: 160; R_Axial_DIN0309_L9.0mm_D3.2mm_P2.54mm_Vertical
R406: 100; R_Axial_DIN0309_L9.0mm_D3.2mm_P2.54mm_Vertical
R407: 75; R_Axial_DIN0309_L9.0mm_D3.2mm_P2.54mm_Vertical
R501: 3,3k; R_Axial_DIN0309_L9.0mm_D3.2mm_P2.54mm_Vertical
TP201: 00; PinHeader_1x01_P2.54mm_Vertical
TP400: V; PinHeader_1x01_P2.54mm_Vertical
TP401: B; PinHeader_1x01_P2.54mm_Vertical
TP402: S; PinHeader_1x01_P2.54mm_Vertical
TP403: G; PinHeader_1x01_P2.54mm_Vertical
TP404: R; PinHeader_1x01_P2.54mm_Vertical
VD200, VD202, VD203, VD400, VD401, VD402, VD403, VD404, VD405: SAY32; D_E-Line_P2.5mm_Vertical
VD201: SZX21/7.5; D_DO-34_SOD68_P2.54mm_Vertical_KathodeUp
VT200: SC308; T_E-Line_Wide_P2.5mm_Vertical
VT201, VT400, VT401, VT402, VT403, VT404: SC236; T_E-Line_Wide_P2.5mm_Vertical
X200: Bus; PinHeader_1x29_P2.54mm_Horizontal
X201: ~{CS2}; PinHeader_1x01_P2.54mm_Horizontal
X202: XTAL; PinHeader_1x02_P2.54mm_Horizontal
X203: select; PinHeader_1x06_P2.54mm_Vertical
X204: ~{KEY}; PinHeader_1x01_P2.54mm_Horizontal
X205: BUSY; PinHeader_1x01_P2.54mm_Horizontal
X206: POWER; SolderWire-0.75sqmm_1x02_P4.8mm_D1.25mm_OD2.3mm
X300, X301, X302, X303: 8k RAM-Modul; PinSocket_1x29_P2.54mm_Vertical
X401: DIN-5_180degree; DIN-Buchse_5polig_halbrund_Print_erweitert
X405: 00; PinHeader_1x01_P2.54mm_Vertical

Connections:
+5V: C2.1, C3.1, C4.1, C5.1, C7.1, C8.1, C9.1, C10.1, C12.1, C13.1, C14.1, C15.1, C17.1, C18.1, C19.1, C20.1, C22.1, C23.1, C24.1, D0.16, D1.1, D1.2, D1.3, D1.9, D1.18, D1.20, D2.20, D3.20, D4.1, D4.2, D4.3, D4.9, D4.18, D4.20, D5.2, D5.13, D5.14, D5.24, D6.21, D6.24, D7.20, D8.20, D9.1, D9.2, D9.3, D9.9, D9.18, D9.20, D10.16, D11.20, D12.1, D12.2, D12.3, D12.9, D12.18, D12.20, D13.1, D14.8, D14.14, D15.20, D16.20, D17.20, D18.6, D18.14, D19.14, D20.6, D20.16, D21.3, D21.16, JP501.1, R3.1, R8.1, R13.1, R18.1, R23.1, R201.1, R205.1, R206.1, R207.1, R208.1, R209.1, R210.1, R211.1, R406.2, VD200.2, VT200.3, VT400.1, VT401.1, VT402.1, VT403.1, VT404.1, X200.28, X206.1, X300.2, X300.26, X300.27, X300.28, X301.2, X301.26, X301.27, X301.28, X302.2, X302.26, X302.27, X302.28, X303.2, X303.26, X303.27, X303.28
/Scart-Ausgang/Blau: R404.2, R405.1, X401.2
/Scart-Ausgang/Grün: R402.1, R408.2, X401.1
/Scart-Ausgang/Rot: R403.2, R409.2, X401.4
/Scart-Ausgang/Sync_BAS: R401.1, R407.1, X401.3
/Scart-Ausgang/~AVRGB: R406.1, X401.5
/Steuerung Video-RAM/VBD0: D9.7, D11.4, X302.12
/Steuerung Video-RAM/VBD1: D9.13, D11.8, X302.16
/Steuerung Video-RAM/VBD2: D9.6, D11.3, X302.11
/Steuerung Video-RAM/VBD3: D9.14, D11.7, X302.15
/Steuerung Video-RAM/VBD4: D9.5, D11.2, X302.10
/Steuerung Video-RAM/VBD5: D9.15, D11.6, X302.14
/Steuerung Video-RAM/VBD6: D9.4, D11.1, X302.9
/Steuerung Video-RAM/VBD7: D9.16, D11.5, X302.13
/Steuerung Video-RAM/VGD0: D4.7, D7.4, X303.12
/Steuerung Video-RAM/VGD1: D4.13, D7.8, X303.16
/Steuerung Video-RAM/VGD2: D4.6, D7.3, X303.11
/Steuerung Video-RAM/VGD3: D4.14, D7.7, X303.15
/Steuerung Video-RAM/VGD4: D4.5, D7.2, X303.10
/Steuerung Video-RAM/VGD5: D4.15, D7.6, X303.14
/Steuerung Video-RAM/VGD6: D4.4, D7.1, X303.9
/Steuerung Video-RAM/VGD7: D4.16, D7.5, X303.13
/Steuerung Video-RAM/VRD0: D1.7, D3.4, X301.12
/Steuerung Video-RAM/VRD1: D1.13, D3.8, X301.16
/Steuerung Video-RAM/VRD2: D1.6, D3.3, X301.11
/Steuerung Video-RAM/VRD3: D1.14, D3.7, X301.15
/Steuerung Video-RAM/VRD4: D1.5, D3.2, X301.10
/Steuerung Video-RAM/VRD5: D1.15, D3.6, X301.14
/Steuerung Video-RAM/VRD6: D1.4, D3.1, X301.9
/Steuerung Video-RAM/VRD7: D1.16, D3.5, X301.13
/Steuerung Video-RAM/VVD0: D12.7, D16.4, X300.12
/Steuerung Video-RAM/VVD1: D12.13, D16.8, X300.16
/Steuerung Video-RAM/VVD2: D12.6, D16.3, X300.11
/Steuerung Video-RAM/VVD3: D12.14, D16.7, X300.15
/Steuerung Video-RAM/VVD4: D12.5, D16.2, X300.10
/Steuerung Video-RAM/VVD5: D12.15, D16.6, X300.14
/Steuerung Video-RAM/VVD6: D12.4, D16.1, X300.9
/Steuerung Video-RAM/VVD7: D12.16, D16.5, X300.13
/Videoausgabe/b: D0.9, JP507.2, R19.2
/Videoausgabe/v: D0.7, JP502.2, JP505.1, R26.2
/Videoausgabe/~HR: D0.2, JP501.2, JP503.1, JP504.1
/Videoprozessor/6C00h-6FFFh: D20.12, X203.3
/Videoprozessor/7C00h-7FFFh: D20.7, X204.1
/Videoprozessor/6000h-63FFh: D18.9, D20.15
/Videoprozessor/6400h-67FFh: D20.14, X203.1
/Videoprozessor/6800h-6BFFh: D20.13, X203.2
/Videoprozessor/7000h-73FFh: D20.11, X203.4
/Videoprozessor/7400h-77FFh: D20.10, X203.5
/Videoprozessor/7800h-7BFFh: D20.9, X203.6
/Videoprozessor/A0: D15.9, X200.17
/Videoprozessor/A1: D15.8, X200.18
/Videoprozessor/A2: D15.7, X200.19
/Videoprozessor/A3: D15.6, X200.20
/Videoprozessor/A4: D15.5, D18.2, X200.21
/Videoprozessor/A5: D15.4, D18.3, X200.22
/Videoprozessor/A6: D15.3, D18.4, X200.23
/Videoprozessor/A7: D15.2, D18.5, X200.24
/Videoprozessor/A8: D17.6, X200.4
/Videoprozessor/A9: D17.5, X200.5
/Videoprozessor/A10: D17.4, D20.1, X200.6
/Videoprozessor/A11: D17.3, D20.2, X200.7
/Videoprozessor/A12: D17.2, D20.3, X200.8
/Videoprozessor/BUSY: D13.40, X205.1
/Videoprozessor/VA0: D2.6, D5.4, D6.8
/Videoprozessor/VA1: D2.7, D5.6, D6.7
/Videoprozessor/VA2: D2.8, D5.8, D6.6
/Videoprozessor/VA3: D2.9, D5.10, D6.5
/Videoprozessor/VA4: D2.3, D5.21, D6.4
/Videoprozessor/VA5: D2.4, D5.19, D6.3
/Videoprozessor/VA6: D2.5, D5.17, D6.2
/Videoprozessor/VA7: D5.15, D6.1
/Videoprozessor/VA8: D6.23, D13.13
/Videoprozessor/VA9: D6.22, D13.14
/Videoprozessor/VA10: D6.19, D13.15
/Videoprozessor/VAD0: D5.3, D6.9, D13.21
/Videoprozessor/VAD1: D5.5, D6.10, D13.22
/Videoprozessor/VAD2: D5.7, D6.11, D13.23
/Videoprozessor/VAD3: D5.9, D6.13, D13.24
/Videoprozessor/VAD4: D5.22, D6.14, D13.25
/Videoprozessor/VAD5: D5.20, D6.15, D13.26
/Videoprozessor/VAD6: D5.18, D6.16, D13.27
/Videoprozessor/VAD7: D5.16, D6.17, D13.28
/Videoprozessor/VP3.7: D13.4, D14.2
/Videoprozessor/xA7: D8.7, D13.31
/Videoprozessor/xA8: D8.6, D13.32
/Videoprozessor/xA9: D8.5, D13.33
/Videoprozessor/xA10: D8.4, D13.34
/Videoprozessor/xA11: D8.3, D13.35
/Videoprozessor/xA12: D8.2, D13.36
/Videoprozessor/~VAS: D5.1, D13.9
/Videoprozessor/~VDS: D6.18, D6.20, D10.3, D10.6, D10.10, D10.13, D13.8, D13.37, D14.6
/Videoprozessor/~VRT: D13.6, R203.1, VD201.1, VT201.1
B: C16.1, R20.1, R405.2, TP401.1, VT401.3
CS2: D2.1, D2.19, D8.1, D8.19, D13.39, D19.9, D19.10
D0: D3.16, D7.16, D11.16, D16.16, X200.16
D1: D3.12, D7.12, D11.12, D16.12, X200.15
D2: D3.17, D7.17, D11.17, D16.17, X200.14
D3: D3.13, D7.13, D11.13, D16.13, X200.13
D4: D3.18, D7.18, D11.18, D16.18, X200.12
D5: D3.14, D7.14, D11.14, D16.14, X200.11
D6: D3.19, D7.19, D11.19, D16.19, X200.10
D7: D3.15, D7.15, D11.15, D16.15, X200.9
DIR: D3.11, D7.11, D11.11, D16.11, D21.4, R211.2, X300.3, X301.3, X302.3, X303.3
G: C6.1, R10.2, R408.1, TP403.1, VT403.3
GND: C2.2, C3.2, C4.2, C5.2, C7.2, C8.2, C9.2, C10.2, C12.2, C13.2, C14.2, C15.2, C17.2, C18.2, C19.2, C20.2, C22.2, C23.2, C24.2, C202.1, D0.1, D0.8, D0.15, D1.10, D1.11, D2.2, D2.10, D3.10, D4.10, D4.11, D5.11, D5.12, D6.12, D7.10, D8.8, D8.9, D8.10, D9.10, D9.11, D10.8, D10.15, D11.10, D12.10, D12.11, D13.11, D13.12, D14.1, D14.3, D14.4, D14.5, D14.7, D15.10, D16.10, D17.7, D17.8, D17.9, D17.10, D18.1, D18.7, D19.7, D20.8, D21.8, D21.15, JP504.2, R5.1, R10.1, R15.1, R20.2, R25.1, R202.2, TP201.1, VD201.2, VT201.3, X200.25, X202.2, X206.2, X300.25, X301.25, X302.25, X303.25, X401.S, X405.1
unnamed: C1.2, R2.1, R3.2
unnamed: C6.2, R7.1, R8.2
unnamed: C11.2, R12.1, R13.2
unnamed: C16.2, R17.1, R18.2
unnamed: C21.2, R22.1, R23.2
unnamed: C200.1, R204.1, VT201.2
unnamed: C200.2, D19.6, R200.2, R204.2
unnamed: C201.1, R203.2, VD200.1
unnamed: C201.2, R202.1, VT200.1
unnamed: C202.2, D18.8, R206.2, VD202.2
unnamed: D13.3, D19.12, R205.2
unnamed: D15.1, D17.1, R212.1, VD203.1
unnamed: D19.1, X202.1
unnamed: D19.4, VD202.1
unnamed: JP505.2, R501.2
unnamed: JP506.1, R24.2
unnamed: R2.2, VD405.2, VT404.2
unnamed: R4.1, VD405.1
unnamed: R7.2, VD404.2, VT403.2
unnamed: R9.1, VD404.1
unnamed: R12.2, VD403.2, VT402.2
unnamed: R14.1, VD403.1
unnamed: R17.2, VD402.2, VT401.2
unnamed: R19.1, VD402.1
unnamed: R22.2, VD400.2, VD401.2, VT400.2
unnamed: R24.1, VD401.1
unnamed: R26.1, R501.1, VD400.1
unnamed: R200.1, R201.2, VT200.2
P3.4: JP503.2, X200.29
R: C1.1, R5.2, R409.1, TP404.1, VT404.3
RT: D19.5, X200.26
R~W: D21.2, X200.3
S: C11.1, R15.2, R407.2, TP402.1, VT402.3
S1: D1.19, D4.19, D9.19, D12.19, D14.10
T: D0.14, D1.12, D4.12, D9.12, D12.12, D14.9, D19.2, D19.13
V: C21.1, R25.2, R401.2, R402.2, R403.1, R404.1, TP400.1, VT400.3
VRA0: D2.14, D15.11, X300.17, X301.17, X302.17, X303.17
VRA1: D2.13, D15.12, X300.18, X301.18, X302.18, X303.18
VRA2: D2.12, D15.13, X300.19, X301.19, X302.19, X303.19
VRA3: D2.11, D15.14, X300.20, X301.20, X302.20, X303.20
VRA4: D2.17, D15.15, X300.21, X301.21, X302.21, X303.21
VRA5: D2.16, D15.16, X300.22, X301.22, X302.22, X303.22
VRA6: D2.15, D15.17, X300.23, X301.23, X302.23, X303.23
VRA7: D8.13, D15.18, X300.24, X301.24, X302.24, X303.24
VRA8: D8.14, D17.14, X300.4, X301.4, X302.4, X303.4
VRA9: D8.15, D17.15, X300.5, X301.5, X302.5, X303.5
VRA10: D8.16, D17.16, X300.6, X301.6, X302.6, X303.6
VRA11: D8.17, D17.17, X300.7, X301.7, X302.7, X303.7
VRA12: D8.18, D17.18, X300.8, X301.8, X302.8, X303.8
YB: D0.5, D0.11, D0.12, D0.13, D9.17, JP507.1
YG: D4.17, R9.2
YR: D1.17, R4.2
YV: D0.3, D0.4, D0.6, D0.10, D12.17, JP502.1
~CS2_delay: D13.38, D15.19, D17.19, D19.8
~CS2: D10.1, D19.3, D19.11, D21.1, R212.2, VD203.2, X201.1
~CS3: D20.4, D20.5, X200.2
~EB: D10.14, D11.9, D18.12, R208.2
~EG: D7.9, D10.11, D18.11, R209.2
~ER: D3.9, D10.5, D18.10, R210.2
~EV: D10.2, D16.9, D18.13, R207.2
~SB: D10.12, X302.1
~SG: D10.9, X303.1
~SR: D10.7, X301.1
~SV: D10.4, X300.1
~SYN: D13.10, JP506.2, R14.2

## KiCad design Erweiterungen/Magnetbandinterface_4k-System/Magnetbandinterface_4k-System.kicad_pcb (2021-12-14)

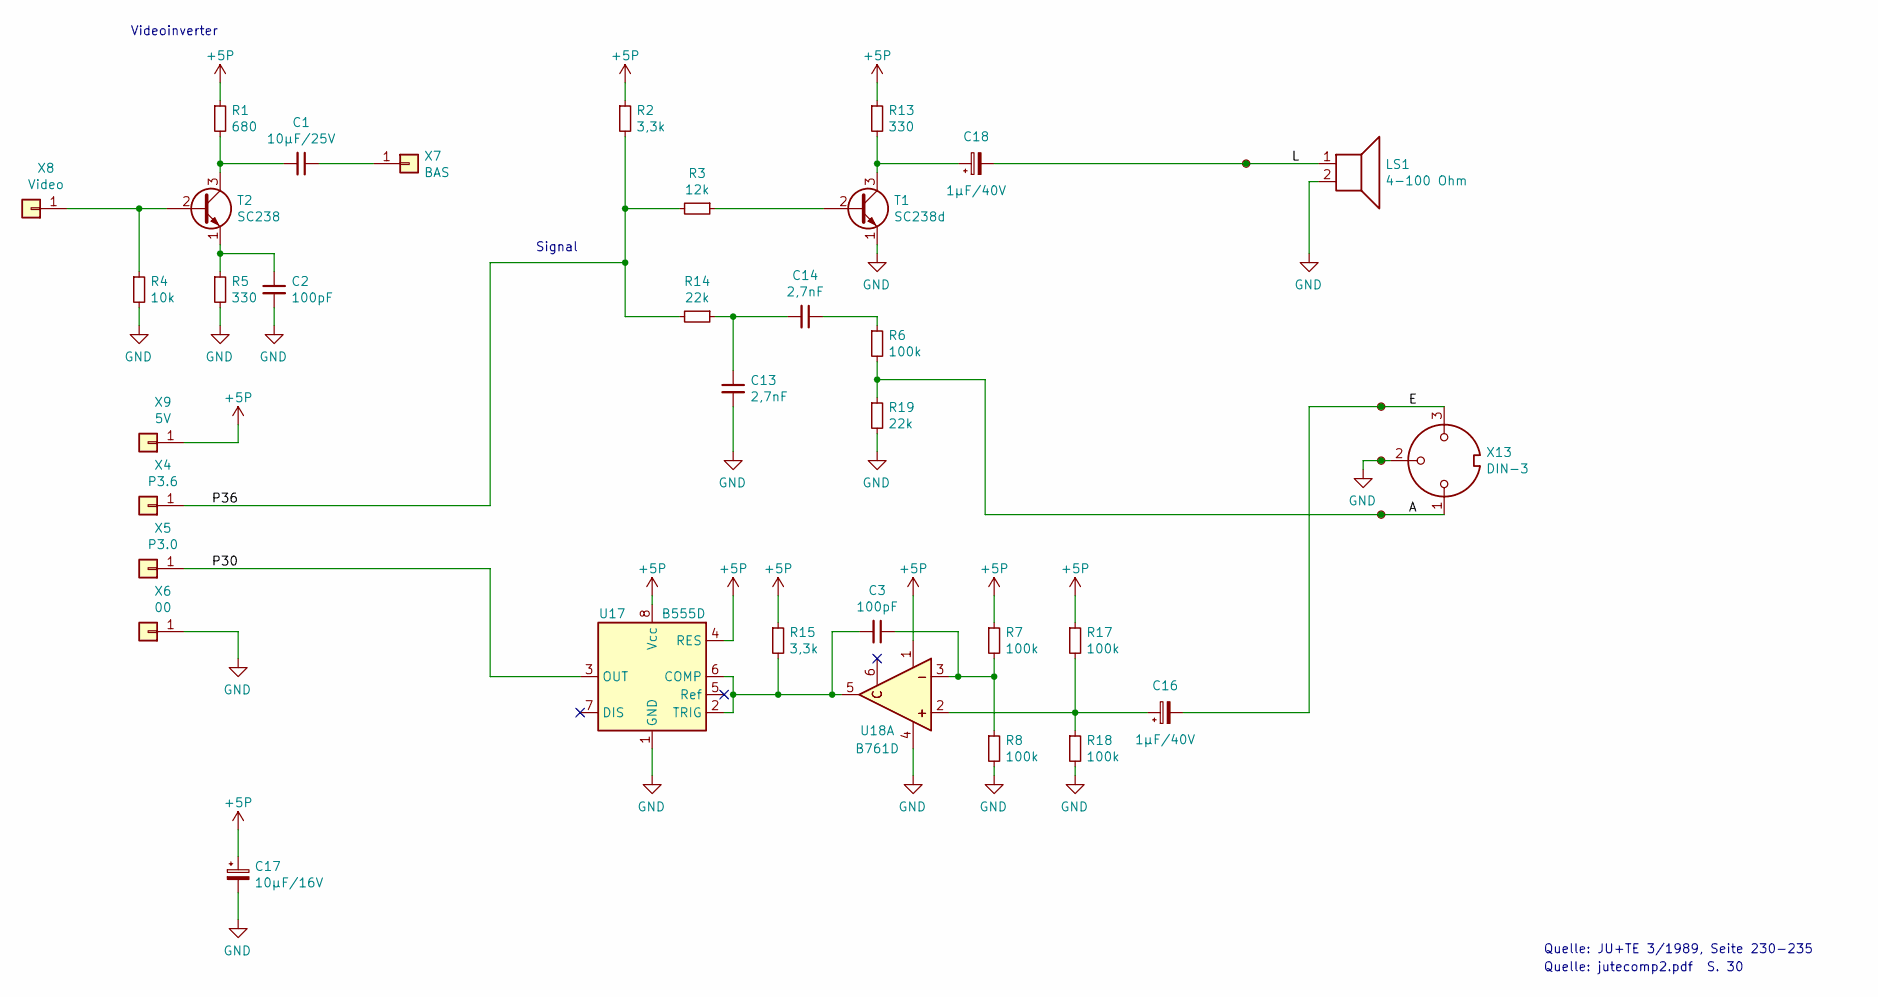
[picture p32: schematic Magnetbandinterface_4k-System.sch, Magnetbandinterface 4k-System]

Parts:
C1: 10µF/25V; CP_Radial_D6.3mm_P2.50mm
C2: 100pF; C_Rect_L9.0mm_W2.5mm_P7.50mm_MKT
C3: 100pF; C_Disc_D4.3mm_W1.9mm_P5.00mm
C13, C14: 2,7nF; C_Rect_L9.0mm_W2.5mm_P7.50mm_MKT
C16, C18: 1µF/40V; CP_Radial_D6.3mm_P2.50mm
C17: 10µF/16V; CP_Radial_D6.3mm_P2.50mm
LS1: 4-100 Ohm; TerminalBlock_RND_205-00001_1x02_P5.00mm_Horizontal
R1: 680; R_Axial_TGL8728_L5.9mm_D2.4mm_P12.50mm_Horizontal
R2, R15: 3,3k; R_Axial_TGL8728_L5.9mm_D2.4mm_P12.50mm_Horizontal
R3: 12k; R_Axial_TGL8728_L5.9mm_D2.4mm_P12.50mm_Horizontal
R4: 10k; R_Axial_TGL8728_L5.9mm_D2.4mm_P12.50mm_Horizontal
R5, R13: 330; R_Axial_TGL8728_L5.9mm_D2.4mm_P12.50mm_Horizontal
R6, R7, R8, R17, R18: 100k; R_Axial_TGL8728_L5.9mm_D2.4mm_P12.50mm_Horizontal
R14, R19: 22k; R_Axial_TGL8728_L5.9mm_D2.4mm_P12.50mm_Horizontal
T1: SC238d; TO-92_Inline_Wide
T2: SC238; TO-92_Inline_Wide
TP1: E; TestPoint_Loop_D2.54mm_Drill1.5mm_Beaded
TP2: 00; TestPoint_Loop_D2.54mm_Drill1.5mm_Beaded
TP3: A; TestPoint_Loop_D2.54mm_Drill1.5mm_Beaded
TP10: L; TestPoint_Loop_D2.54mm_Drill1.5mm_Beaded
U17: B555D; DIP-8_W7.62mm
U18: B761D; DIP-6_W7.62mm
X4: P3.6; TestPoint_Loop_D2.54mm_Drill1.5mm_Beaded
X5: P3.0; TestPoint_Loop_D2.54mm_Drill1.5mm_Beaded
X6: 00; TestPoint_Loop_D2.54mm_Drill1.5mm_Beaded
X7: BAS; TestPoint_Loop_D2.54mm_Drill1.5mm_Beaded
X8: Video; TestPoint_Loop_D2.54mm_Drill1.5mm_Beaded
X9: 5V; TestPoint_Loop_D2.54mm_Drill1.5mm_Beaded
X13: DIN-3; PinHeader_1x03_P2.54mm_Vertical

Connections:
+5P: C17.1, R1.1, R2.1, R7.1, R13.1, R15.1, R17.1, U17.4 (RES), U17.8 (Vcc), U18.1 (+), X9.1
/A: R6.2, R19.1, TP3.1, X13.1
/E: C16.2, TP1.1, X13.3
/L: C18.2, LS1.1, TP10.1
/P30: U17.3 (OUT), X5.1
/P36: R2.2, R3.2, R14.2, X4.1
GND: C2.2, C13.2, C17.2, LS1.2, R4.2, R5.2, R8.2, R18.2, R19.2, T1.1 (E), TP2.1, U17.1 (GND), U18.4 (-), X6.1, X13.2
unnamed: C1.1, X7.1
unnamed: C1.2, R1.2, T2.3 (C)
unnamed: C2.1, R5.1, T2.1 (E)
unnamed: C3.1, R7.2, R8.1, U18.3 (-)
unnamed: C3.2, R15.2, U17.2 (TRIG), U17.6 (COMP), U18.5
unnamed: C13.1, C14.2, R14.1
unnamed: C14.1, R6.1
unnamed: C16.1, R17.2, R18.1, U18.2 (+)
unnamed: C18.1, R13.2, T1.3 (C)
unnamed: R3.1, T1.2 (B)
unnamed: R4.1, T2.2 (B), X8.1

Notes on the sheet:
Quelle: jutecomp2.pdf S. 30
Quelle: JU+TE 3/1989, Seite 230-235
Signal
Videoinverter

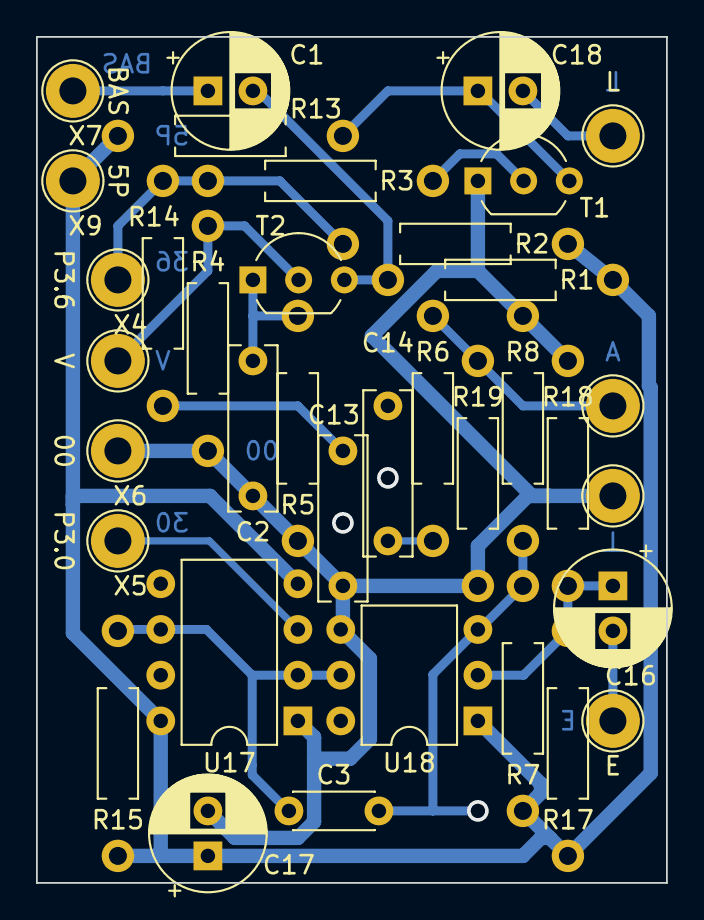
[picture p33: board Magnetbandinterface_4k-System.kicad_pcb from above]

Board: 2 copper layers, 35.0 x 47.0 mm, 36 parts (0 on the bottom side), 18 nets.

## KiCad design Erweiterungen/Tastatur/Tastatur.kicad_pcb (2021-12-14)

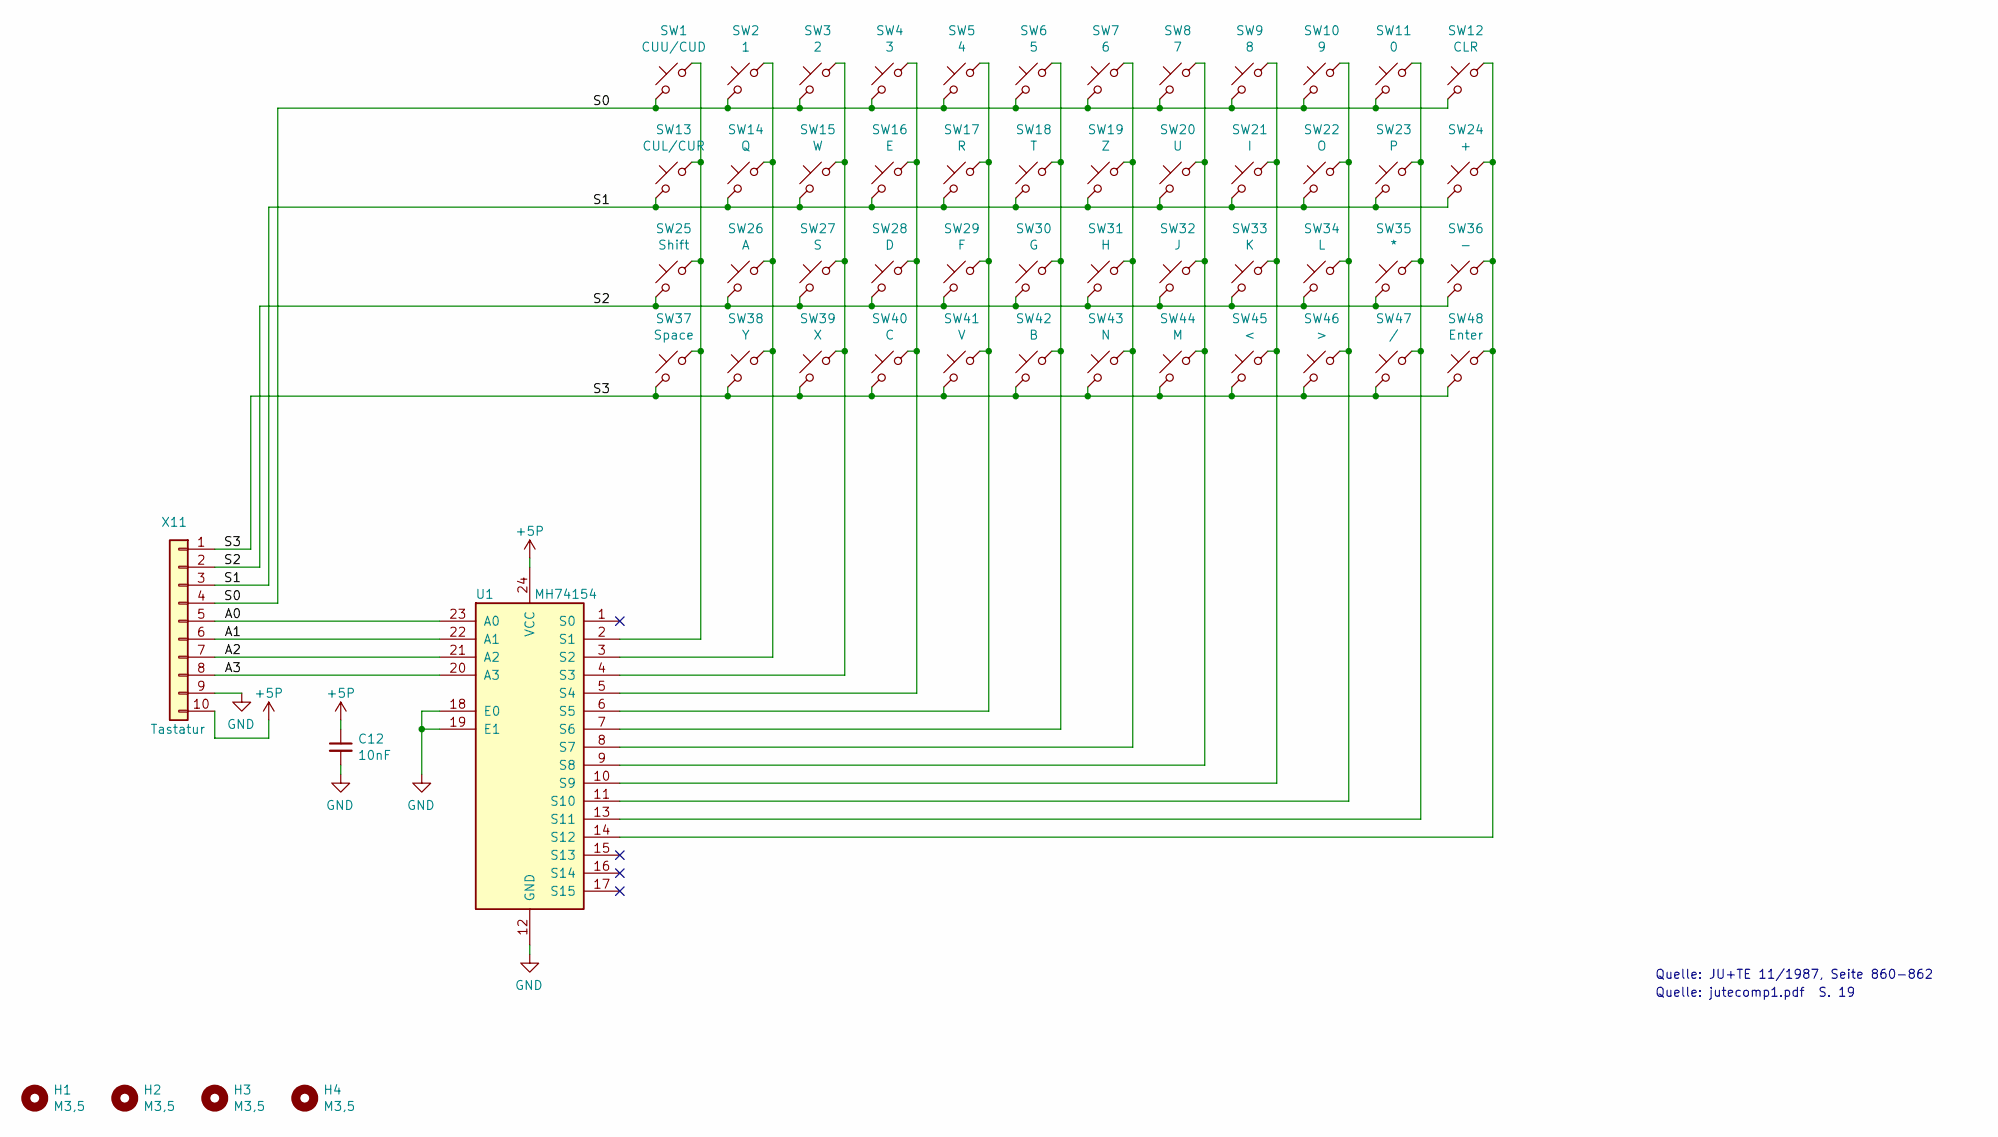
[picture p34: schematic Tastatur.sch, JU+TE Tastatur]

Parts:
C12: 10nF; C_Disc_D4.3mm_W1.9mm_P5.00mm
H1, H2, H3, H4: M3,5; MountingHole_3.5mm
SW1: CUU/CUD; TSE15_stehend_ohne_Beleuchtung
SW2: 1; TSE15_stehend_ohne_Beleuchtung
SW3: 2; TSE15_stehend_ohne_Beleuchtung
SW4: 3; TSE15_stehend_ohne_Beleuchtung
SW5: 4; TSE15_stehend_ohne_Beleuchtung
SW6: 5; TSE15_stehend_ohne_Beleuchtung
SW7: 6; TSE15_stehend_ohne_Beleuchtung
SW8: 7; TSE15_stehend_ohne_Beleuchtung
SW9: 8; TSE15_stehend_ohne_Beleuchtung
SW10: 9; TSE15_stehend_ohne_Beleuchtung
SW11: 0; TSE15_stehend_ohne_Beleuchtung
SW12: CLR; TSE15_stehend_ohne_Beleuchtung
SW13: CUL/CUR; TSE15_stehend_ohne_Beleuchtung
SW14: Q; TSE15_stehend_ohne_Beleuchtung
SW15: W; TSE15_stehend_ohne_Beleuchtung
SW16: E; TSE15_stehend_ohne_Beleuchtung
SW17: R; TSE15_stehend_ohne_Beleuchtung
SW18: T; TSE15_stehend_ohne_Beleuchtung
SW19: Z; TSE15_stehend_ohne_Beleuchtung
SW20: U; TSE15_stehend_ohne_Beleuchtung
SW21: I; TSE15_stehend_ohne_Beleuchtung
SW22: O; TSE15_stehend_ohne_Beleuchtung
SW23: P; TSE15_stehend_ohne_Beleuchtung
SW24: +; TSE15_stehend_ohne_Beleuchtung
SW25: Shift; TSE15_stehend_ohne_Beleuchtung
SW26: A; TSE15_stehend_ohne_Beleuchtung
SW27: S; TSE15_stehend_ohne_Beleuchtung
SW28: D; TSE15_stehend_ohne_Beleuchtung
SW29: F; TSE15_stehend_ohne_Beleuchtung
SW30: G; TSE15_stehend_ohne_Beleuchtung
SW31: H; TSE15_stehend_ohne_Beleuchtung
SW32: J; TSE15_stehend_ohne_Beleuchtung
SW33: K; TSE15_stehend_ohne_Beleuchtung
SW34: L; TSE15_stehend_ohne_Beleuchtung
SW35: *; TSE15_stehend_ohne_Beleuchtung
SW36: -; TSE15_stehend_ohne_Beleuchtung
SW37: Space; TSE15_stehend_ohne_Beleuchtung
SW38: Y; TSE15_stehend_ohne_Beleuchtung
SW39: X; TSE15_stehend_ohne_Beleuchtung
SW40: C; TSE15_stehend_ohne_Beleuchtung
SW41: V; TSE15_stehend_ohne_Beleuchtung
SW42: B; TSE15_stehend_ohne_Beleuchtung
SW43: N; TSE15_stehend_ohne_Beleuchtung
SW44: M; TSE15_stehend_ohne_Beleuchtung
SW45: <; TSE15_stehend_ohne_Beleuchtung
SW46: >; TSE15_stehend_ohne_Beleuchtung
SW47: /; TSE15_stehend_ohne_Beleuchtung
SW48: Enter; TSE15_stehend_ohne_Beleuchtung
U1: MH74154; DIP-24_W15.24mm_Socket
X11: Tastatur; Molex_SL_171971-0010_1x10_P2.54mm_Vertical

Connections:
+5P: C12.1, U1.24 (VCC), X11.10
/A0: U1.23 (A0), X11.5
/A1: U1.22 (A1), X11.6
/A2: U1.21 (A2), X11.7
/A3: U1.20 (A3), X11.8
/S0: SW1.2, SW2.2, SW3.2, SW4.2, SW5.2, SW6.2, SW7.2, SW8.2, SW9.2, SW10.2, SW11.2, SW12.2, X11.4
/S1: SW13.2, SW14.2, SW15.2, SW16.2, SW17.2, SW18.2, SW19.2, SW20.2, SW21.2, SW22.2, SW23.2, SW24.2, X11.3
/S2: SW25.2, SW26.2, SW27.2, SW28.2, SW29.2, SW30.2, SW31.2, SW32.2, SW33.2, SW34.2, SW35.2, SW36.2, X11.2
/S3: SW37.2, SW38.2, SW39.2, SW40.2, SW41.2, SW42.2, SW43.2, SW44.2, SW45.2, SW46.2, SW47.2, SW48.2, X11.1
GND: C12.2, U1.12 (GND), U1.18 (E0), U1.19 (E1), X11.9
unnamed: SW1.1, SW13.1, SW25.1, SW37.1, U1.2 (S1)
unnamed: SW10.1, SW22.1, SW34.1, SW46.1, U1.11 (S10)
unnamed: SW11.1, SW23.1, SW35.1, SW47.1, U1.13 (S11)
unnamed: SW12.1, SW24.1, SW36.1, SW48.1, U1.14 (S12)
unnamed: SW2.1, SW14.1, SW26.1, SW38.1, U1.3 (S2)
unnamed: SW3.1, SW15.1, SW27.1, SW39.1, U1.4 (S3)
unnamed: SW4.1, SW16.1, SW28.1, SW40.1, U1.5 (S4)
unnamed: SW5.1, SW17.1, SW29.1, SW41.1, U1.6 (S5)
unnamed: SW6.1, SW18.1, SW30.1, SW42.1, U1.7 (S6)
unnamed: SW7.1, SW19.1, SW31.1, SW43.1, U1.8 (S7)
unnamed: SW8.1, SW20.1, SW32.1, SW44.1, U1.9 (S8)
unnamed: SW9.1, SW21.1, SW33.1, SW45.1, U1.10 (S9)

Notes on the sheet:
Quelle: jutecomp1.pdf S. 19
Quelle: JU+TE 11/1987, Seite 860-862

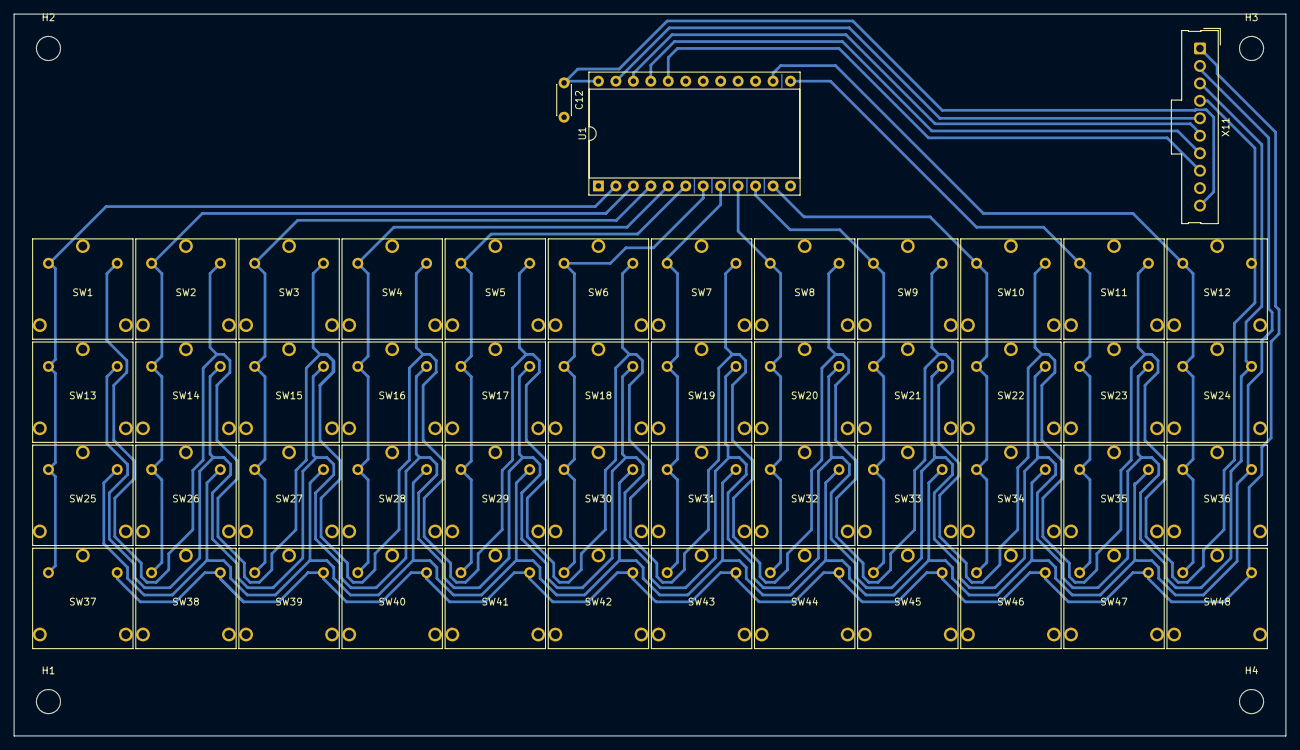
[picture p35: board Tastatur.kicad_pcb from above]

Board: 2 copper layers, 185.0 x 105.0 mm, 55 parts (0 on the bottom side), 22 nets.

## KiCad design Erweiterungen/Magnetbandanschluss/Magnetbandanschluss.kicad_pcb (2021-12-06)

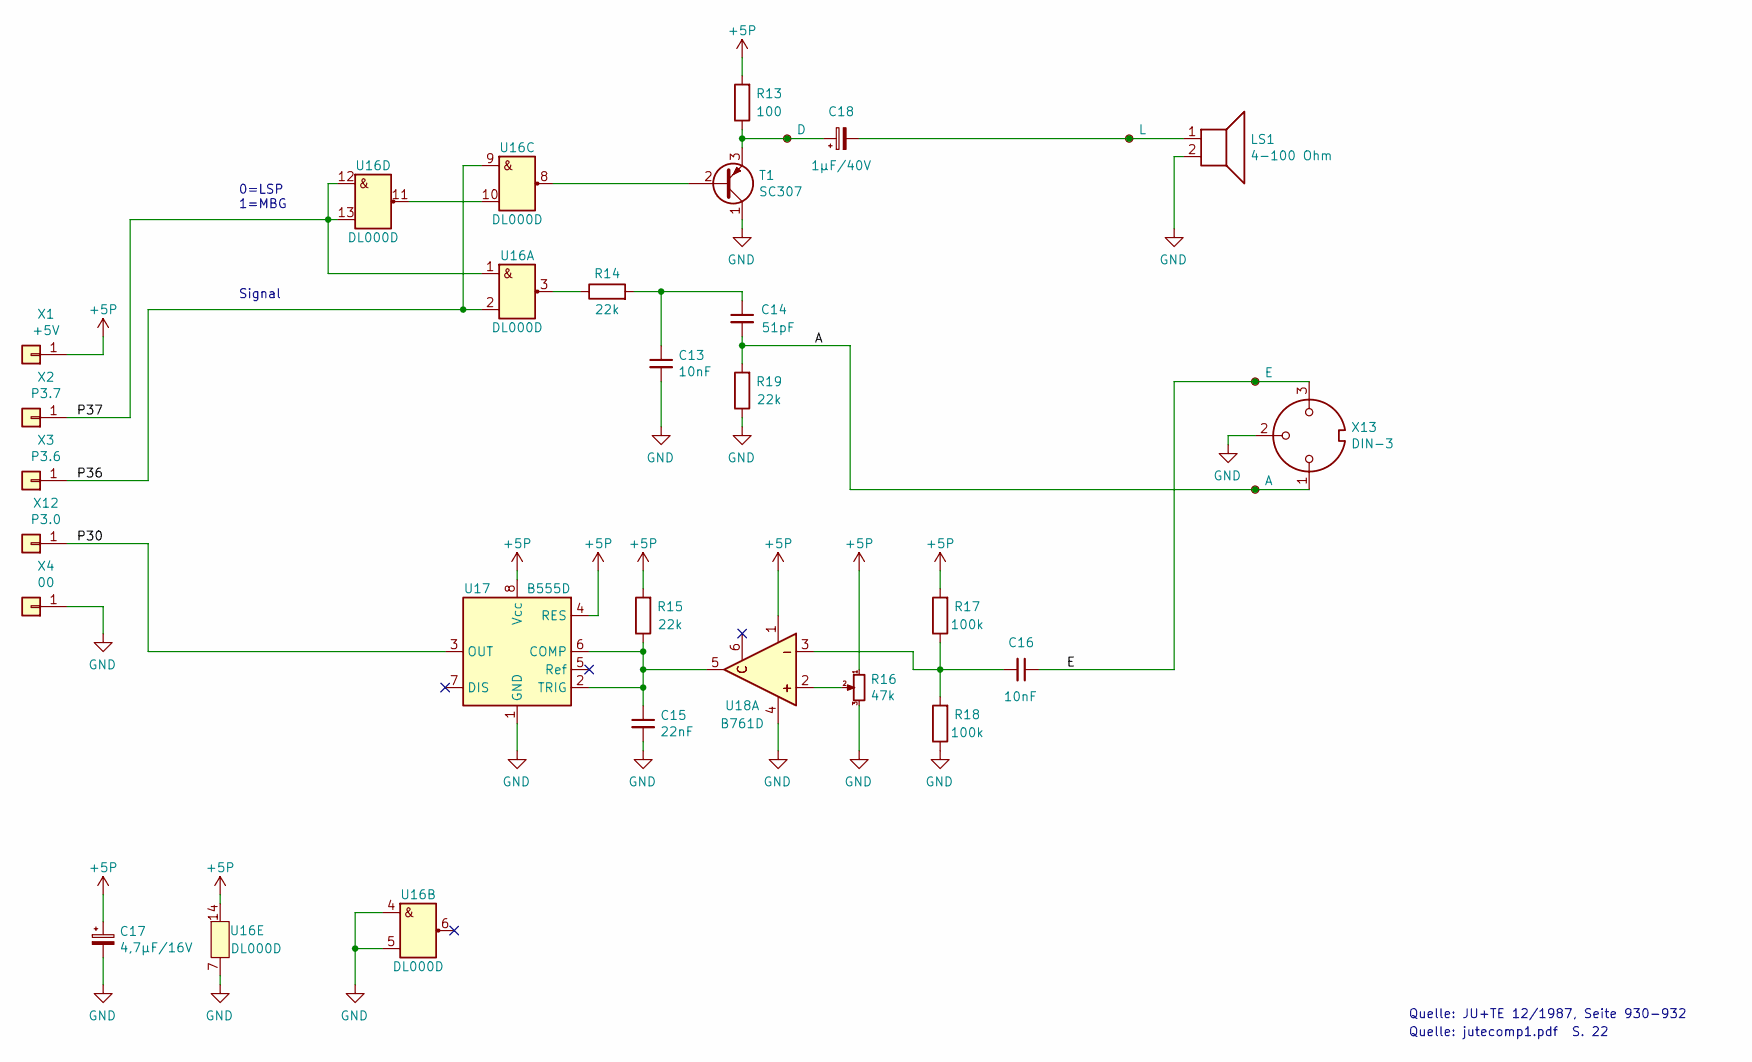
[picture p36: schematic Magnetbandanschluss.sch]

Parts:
C13, C16: 10nF; C_Disc_D3.0mm_W1.6mm_P2.50mm
C14: 51pF; C_Axial_L3.8mm_D2.6mm_P12.50mm_Horizontal
C15: 22nF; C_Axial_L3.8mm_D2.6mm_P12.50mm_Horizontal
C17: 4,7µF/16V; CP_Radial_D5.0mm_P2.50mm
C18: 1µF/40V; CP_Radial_D6.3mm_P2.50mm
LS1: 4-100 Ohm
R13: 100; R_Axial_DIN0309_L9.0mm_D3.2mm_P12.70mm_Horizontal
R14, R15, R19: 22k; R_Axial_DIN0309_L9.0mm_D3.2mm_P12.70mm_Horizontal
R16: 47k; Potentiometer_Piher_PT-10-H01_Horizontal
R17, R18: 100k; R_Axial_DIN0309_L9.0mm_D3.2mm_P12.70mm_Horizontal
T1: SC307; TO-92L_Inline_Wide
TP1: E; Pin_D1.0mm_L10.0mm
TP2: A; Pin_D1.0mm_L10.0mm
TP3: L; Pin_D1.0mm_L10.0mm
TP4: D; Pin_D1.0mm_L10.0mm
U16: DL000D; DIP-14_W7.62mm_Socket
U17: B555D; DIP-8_W7.62mm_Socket
U18: B761D; DIP-6_W7.62mm_Socket
X1: +5V; Pin_D1.0mm_L10.0mm
X2: P3.7; Pin_D1.0mm_L10.0mm
X3: P3.6; Pin_D1.0mm_L10.0mm
X4: 00; Pin_D1.0mm_L10.0mm
X12: P3.0; Pin_D1.0mm_L10.0mm
X13: DIN-3

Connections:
+5P: C17.1, R13.2, R15.2, R16.1, R17.2, U16.14 (Vcc), U17.4 (RES), U17.8 (Vcc), U18.1 (+), X1.1
/A: C14.2, R19.2, TP2.1, X13.1
/E: C16.1, TP1.1, X13.3
/P30: U17.3 (OUT), X12.1
/P36: U16.2 (B1), U16.9 (A3), X3.1
/P37: U16.1 (A1), U16.12 (A4), U16.13 (B4), X2.1
GND: C13.2, C15.2, C17.2, LS1.2, R16.3, R18.1, R19.1, T1.1 (C), U16.4 (A2), U16.5 (B2), U16.7 (GND), U17.1 (GND), U18.4 (-), X4.1, X13.2
unnamed: C13.1, C14.1, R14.2
unnamed: C15.1, R15.1, U17.2 (TRIG), U17.6 (COMP), U18.5
unnamed: C16.2, R17.1, R18.2, U18.3 (-)
unnamed: C18.1, R13.1, T1.3 (E), TP4.1
unnamed: C18.2, LS1.1, TP3.1
unnamed: R14.1, U16.3 (Y1)
unnamed: R16.2, U18.2 (+)
unnamed: T1.2 (B), U16.8 (Y3)
unnamed: U16.10 (B3), U16.11 (Y4)

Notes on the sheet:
Quelle: jutecomp1.pdf S. 22
Quelle: JU+TE 12/1987, Seite 930-932
Signal
0=LSP 1=MBG

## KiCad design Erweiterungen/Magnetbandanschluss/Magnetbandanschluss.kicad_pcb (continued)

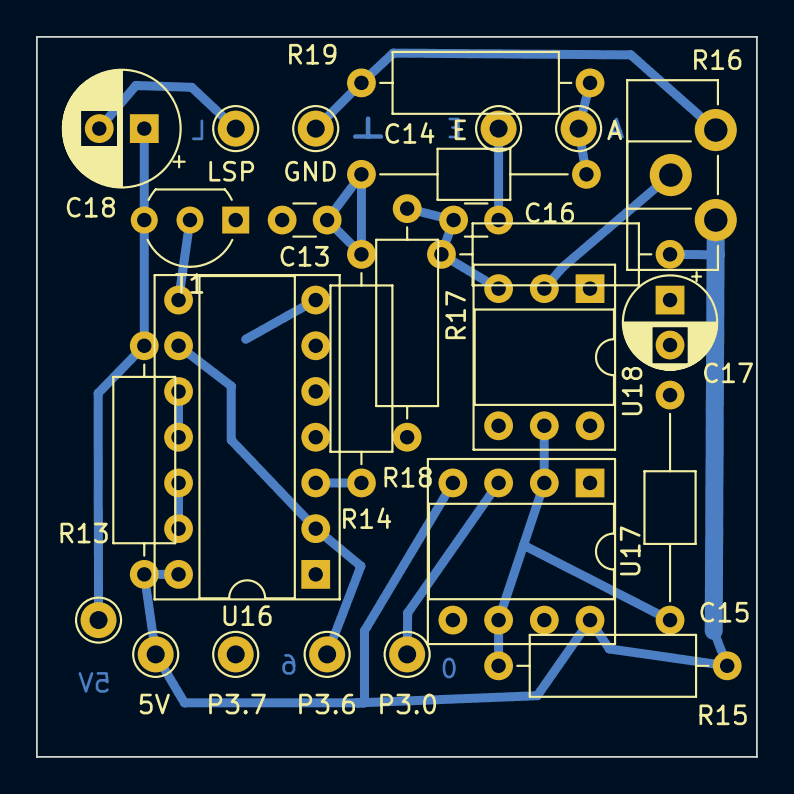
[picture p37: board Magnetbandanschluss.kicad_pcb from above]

Board: 2 copper layers, 40.0 x 40.0 mm, 26 parts (0 on the bottom side), 16 nets.

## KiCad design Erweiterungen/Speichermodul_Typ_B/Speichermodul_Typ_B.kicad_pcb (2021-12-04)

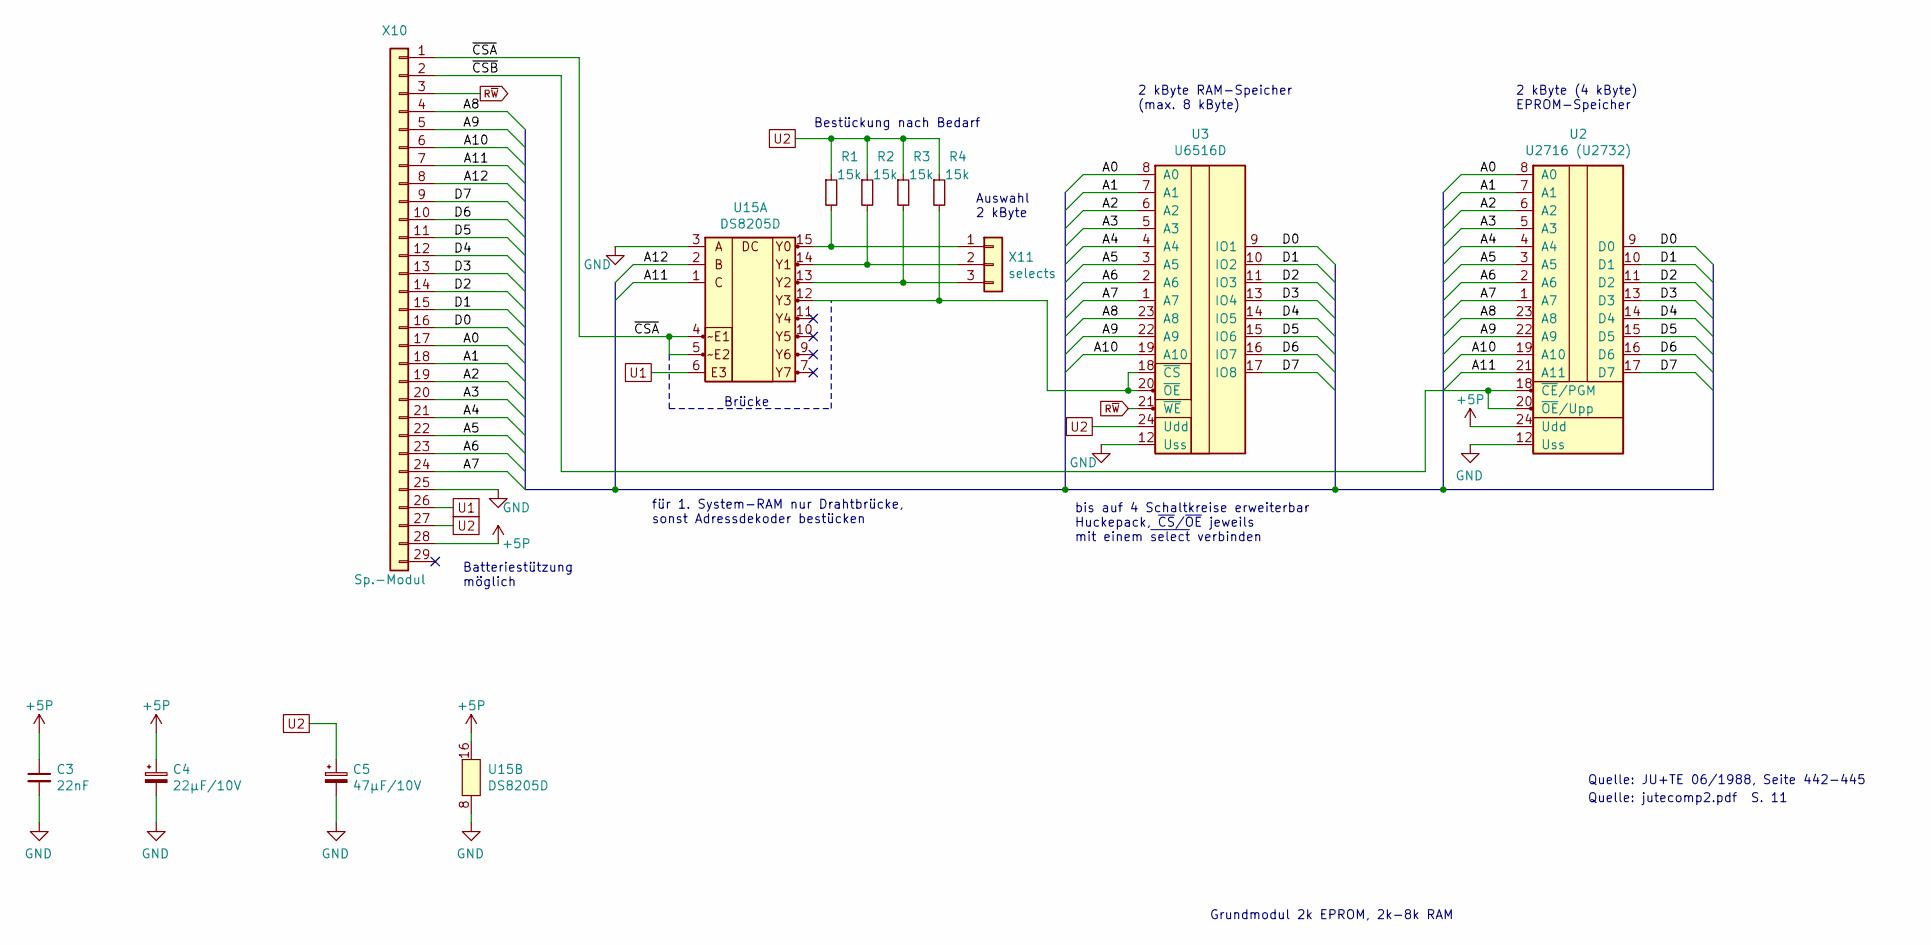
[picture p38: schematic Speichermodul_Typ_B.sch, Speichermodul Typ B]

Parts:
C3: 22nF; C_Disc_D4.3mm_W1.9mm_P5.00mm
C4: 22µF/10V; CP_Radial_D6.3mm_P2.50mm
C5: 47µF/10V; CP_Radial_D8.0mm_P3.50mm
R1, R2, R3, R4: 15k; R_Axial_DIN0204_L3.6mm_D1.6mm_P2.54mm_Vertical
U2: U2716 (U2732); DIP-24_W15.24mm_Socket
U3: U6516D; DIP-24_W15.24mm_Socket
U15: DS8205D; DIP-16_W7.62mm_Socket
X10: Sp.-Modul; PinHeader_1x29_P2.54mm_Horizontal
X11: selects; PinHeader_1x03_P2.54mm_Vertical

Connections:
+5P: C3.1, C4.1, U2.24 (Udd), U15.16 (Vcc), X10.28
/A0: U2.8 (A0), U3.8 (A0), X10.17
/A1: U2.7 (A1), U3.7 (A1), X10.18
/A2: U2.6 (A2), U3.6 (A2), X10.19
/A3: U2.5 (A3), U3.5 (A3), X10.20
/A4: U2.4 (A4), U3.4 (A4), X10.21
/A5: U2.3 (A5), U3.3 (A5), X10.22
/A6: U2.2 (A6), U3.2 (A6), X10.23
/A7: U2.1 (A7), U3.1 (A7), X10.24
/A8: U2.23 (A8), U3.23 (A8), X10.4
/A9: U2.22 (A9), U3.22 (A9), X10.5
/A10: U2.19 (A10), U3.19 (A10), X10.6
/A11: U2.21 (A11), U15.1 (C), X10.7
/A12: U15.2 (B), X10.8
/D0: U2.9 (D0), U3.9 (IO1), X10.16
/D1: U2.10 (D1), U3.10 (IO2), X10.15
/D2: U2.11 (D2), U3.11 (IO3), X10.14
/D3: U2.13 (D3), U3.13 (IO4), X10.13
/D4: U2.14 (D4), U3.14 (IO5), X10.12
/D5: U2.15 (D5), U3.15 (IO6), X10.11
/D6: U2.16 (D6), U3.16 (IO7), X10.10
/D7: U2.17 (D7), U3.17 (IO8), X10.9
/~CSA: U15.4 (~E1), U15.5 (~E2), X10.1
GND: C3.2, C4.2, C5.2, U2.12 (Uss), U3.12 (Uss), U15.3 (A), U15.8 (GND), X10.25
unnamed: R1.2, U15.15 (Y0), X11.1
unnamed: R2.2, U15.14 (Y1), X11.2
unnamed: R3.2, U15.13 (Y2), X11.3
unnamed: R4.2, U3.18 (~CS), U3.20 (~OE), U15.12 (Y3)
R~W: U3.21 (~WE), X10.3
U1: U15.6 (E3), X10.26
U2: C5.1, R1.1, R2.1, R3.1, R4.1, U3.24 (Udd), X10.27
~CSB: U2.18 (~CE~/PGM), U2.20 (~OE~/Upp), X10.2

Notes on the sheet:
für 1. System-RAM nur Drahtbrücke, sonst Adressdekoder bestücken
Quelle: JU+TE 06/1988, Seite 442-445
Quelle: jutecomp2.pdf S. 11
Bestückung nach Bedarf
Auswahl 2 kByte
Batteriestützung möglich
2 kByte RAM-Speicher (max. 8 kByte)
2 kByte (4 kByte) EPROM-Speicher
bis auf 4 Schaltkreise erweiterbar Huckepack, ~CS~/~OE~ jeweils mit einem ~select~ verbinden
Brücke
Grundmodul 2k EPROM, 2k-8k RAM

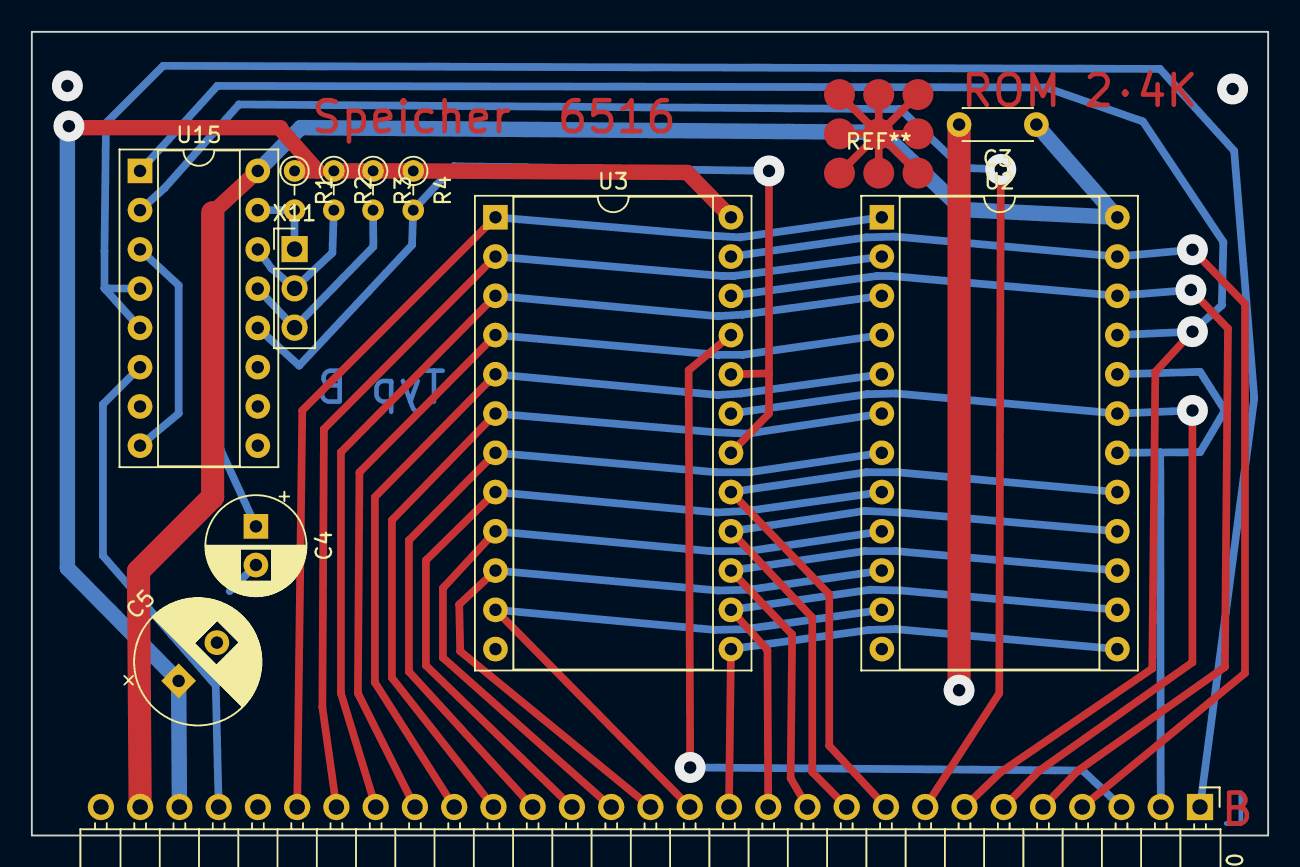
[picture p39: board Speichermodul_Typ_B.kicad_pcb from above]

Board: 2 copper layers, 80.0 x 52.0 mm, 12 parts (0 on the bottom side), 32 nets.

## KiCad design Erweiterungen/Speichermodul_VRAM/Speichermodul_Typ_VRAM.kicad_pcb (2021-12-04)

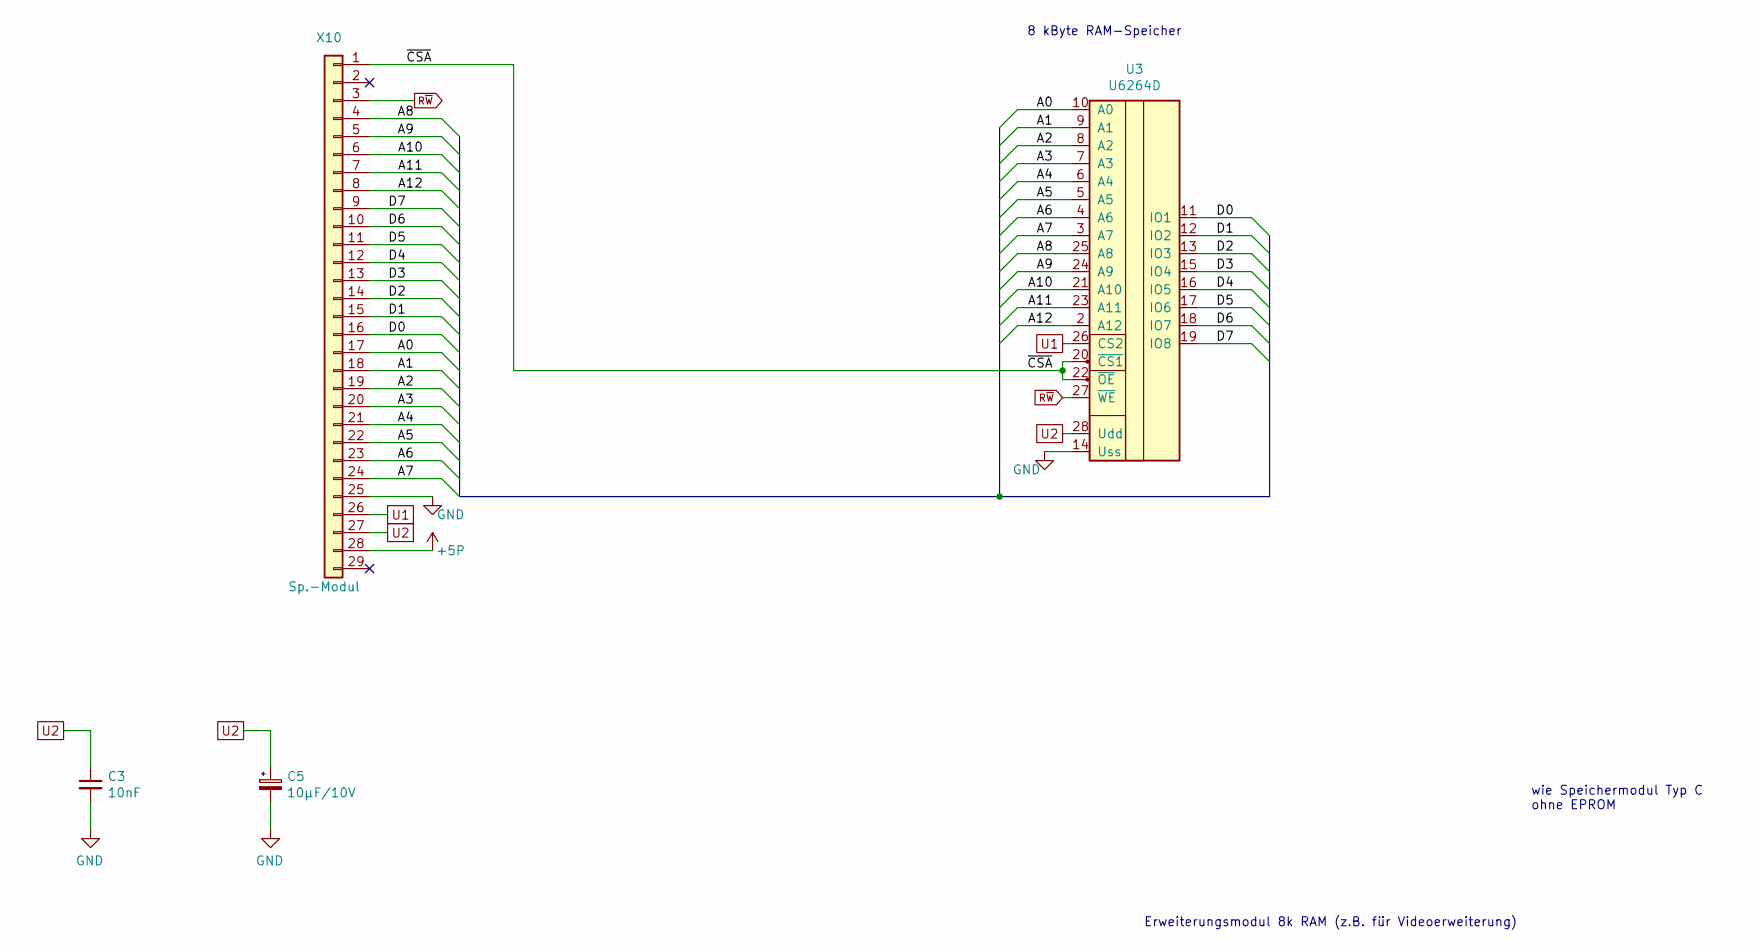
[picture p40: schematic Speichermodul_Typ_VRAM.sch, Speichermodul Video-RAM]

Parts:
C3: 10nF; C_Disc_D4.3mm_W1.9mm_P5.00mm
C5: 10µF/10V; CP_Radial_D6.3mm_P2.50mm
U3: U6264D; DIP-28_W15.24mm_Socket
X10: Sp.-Modul; PinHeader_1x29_P2.54mm_Horizontal

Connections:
+5P: X10.28
/A0: U3.10 (A0), X10.17
/A1: U3.9 (A1), X10.18
/A2: U3.8 (A2), X10.19
/A3: U3.7 (A3), X10.20
/A4: U3.6 (A4), X10.21
/A5: U3.5 (A5), X10.22
/A6: U3.4 (A6), X10.23
/A7: U3.3 (A7), X10.24
/A8: U3.25 (A8), X10.4
/A9: U3.24 (A9), X10.5
/A10: U3.21 (A10), X10.6
/A11: U3.23 (A11), X10.7
/A12: U3.2 (A12), X10.8
/D0: U3.11 (IO1), X10.16
/D1: U3.12 (IO2), X10.15
/D2: U3.13 (IO3), X10.14
/D3: U3.15 (IO4), X10.13
/D4: U3.16 (IO5), X10.12
/D5: U3.17 (IO6), X10.11
/D6: U3.18 (IO7), X10.10
/D7: U3.19 (IO8), X10.9
/~CSA: U3.20 (~CS1), U3.22 (~OE), X10.1
GND: C3.2, C5.2, U3.14 (Uss), X10.25
R~W: U3.27 (~WE), X10.3
U1: U3.26 (CS2), X10.26
U2: C3.1, C5.1, U3.28 (Udd), X10.27

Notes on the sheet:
wie Speichermodul Typ C ohne EPROM
8 kByte RAM-Speicher
Erweiterungsmodul 8k RAM (z.B. für Videoerweiterung)

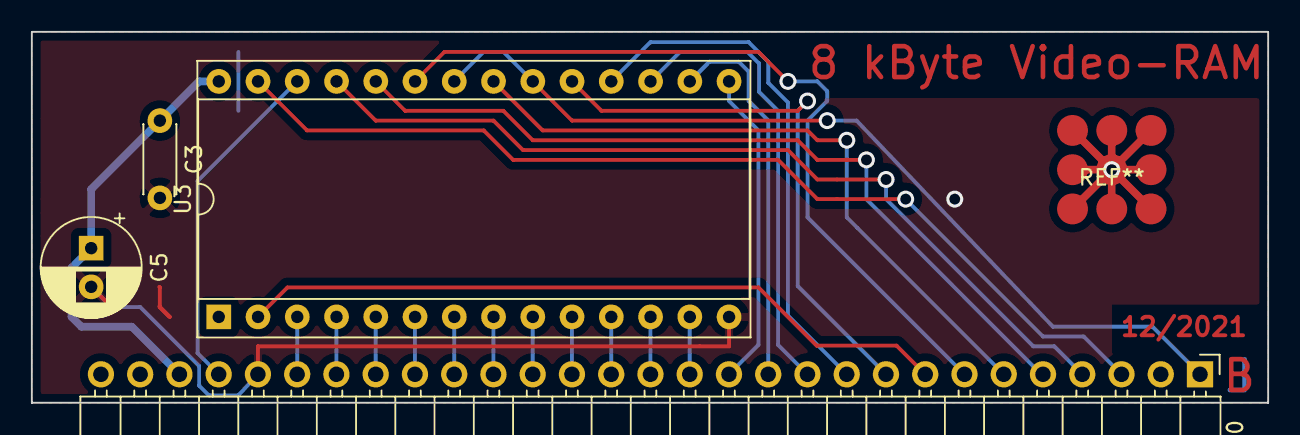
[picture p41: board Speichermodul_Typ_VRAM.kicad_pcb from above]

Board: 2 copper layers, 80.0 x 24.0 mm, 4 parts (0 on the bottom side), 26 nets.

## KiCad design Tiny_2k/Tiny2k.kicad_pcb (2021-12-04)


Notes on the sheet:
%0000 - %07FF
2kB interner ROM des UB8830
%0800 - %0FFF
2kB EPROM
%E000 - %E3FF
1kB RAM
(%FC00 - %FFFF)
1kB RAM (mehrfach eingeblendet)
Minimalvariante Speichermodul A (2k EPROM, 1k RAM) auf Steckplatz 1
1kB RAM (/CS0)
%FC00 - %FFFF
1kB RAM (/CS7)
Speichermodul A aufgerüstet mit 1x DS8205, 2k RAM (huckepack) oder Speichermodul B (2k EPROM, 2k RAM)
%E000 - %FFFF
8kB RAM (/CS0.../CS7)
Speichermodul A aufgerüstet mit 1x DS8205, 8k RAM (huckepack) oder Speichermodul B aufgerüstet mit 1x DS8205, 8k RAM
%0800 - %1FFF
6kB EPROM (Steckplatz 1)
8kB RAM (Steckplatz 1)
Speichermodul C (8k RAM, 8k EPROM)
6kB EPROM (auf Steckplatz 1)
%C000 - %DFFF
8kB RAM (Steckplatz 2)
4x Speichermodul C mit 32k RAM und 30k EPROM
%8000 - %9FFF
8kB RAM (Steckplatz 4)
%A000 - %BFFF
8kB RAM (Steckplatz 3)
%2000 - %3FFF
8kB EPROM (auf Steckplatz 2)
%4000 - %5FFF
8kB EPROM (auf Steckplatz 3)
%6000 - %7FFF
8kB EPROM (auf Steckplatz 4), Zusatzdekoder wg. Tastatur nötig
Speicherausbau (Varianten)
Portbelegung
Maximale Last pro Portpin: 0 = low = 2 mA 1 = high = 250 µA
P20 frei P21 frei P22 frei P23 frei P24 frei P25 frei P26 frei P27 frei
P30 Magnetband, Eingabe P31 frei (nur Eingang) P32 frei (nur Eingang) P33 frei (nur Eingang) P34 frei (nur Ausgang), ggf. Bankumschaltung P35 frei (nur Ausgang) P36 akustische Ausgabe P37 Video-Syncronsignal und Umschaltsignal für akustische Ausgabe

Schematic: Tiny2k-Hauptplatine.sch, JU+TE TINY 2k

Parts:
C1: 2,2µF/40V; CP_Radial_D6.3mm_P2.50mm
C6: 33pF; C_Disc_D4.3mm_W1.9mm_P5.00mm
D1, D2: SAY30; D_T-1_P2.54mm_Vertical_AnodeUp
Q1: 8000 kHz; Crystal_HC18-U_Vertical
R3: 470; R_Axial_DIN0309_L9.0mm_D3.2mm_P12.70mm_Horizontal
R4: 2,7k; R_Axial_DIN0309_L9.0mm_D3.2mm_P12.70mm_Horizontal
R5, R6: 3,3k; R_Axial_DIN0309_L9.0mm_D3.2mm_P12.70mm_Horizontal
R7: 6,8k; R_Axial_DIN0309_L9.0mm_D3.2mm_P12.70mm_Horizontal
R8, R9, R10, R11: 15k; R_Axial_DIN0309_L9.0mm_D3.2mm_P12.70mm_Horizontal
TP1: ~Reset; TestPoint_THTPad_D2.0mm_Drill1.0mm
U1: UB8830; DIP-40_W15.24mm_Socket
U5: DS8205D; DIP-16_W7.62mm_Socket
U6: DS8212D; DIP-24_W15.24mm_Socket
U8: V40098D; DIP-16_W7.62mm_Socket
U9: DL000D; DIP-14_W7.62mm_Socket
U10: DL030D; DIP-14_W7.62mm_Socket
U11: DL074D; DIP-14_W7.62mm_Socket
U12, U13: D195D; DIP-14_W7.62mm_Socket
X2: P20-27,P30-37; Altech_AK300_1x16_P5.00mm_45-Degree
X3: Modul 1; PinSocket_1x29_P2.54mm_Vertical
X4: Modul 2; PinSocket_1x29_P2.54mm_Vertical
X5: Modul 3; PinSocket_1x29_P2.54mm_Vertical
X6: Modul 4; PinSocket_1x29_P2.54mm_Vertical
X8: Video; PinSocket_1x02_P2.54mm_Vertical
X9: Versorgung; TerminalBlock_bornier-4_P5.08mm
X71: Spalten; TerminalBlock_bornier-4_P5.08mm
X72: Zeilen; TerminalBlock_bornier-6_P5.08mm

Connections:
+5P: R4.2, R5.2, R8.2, R9.2, R10.2, R11.2, U1.1 (Vcc), U5.6 (E3), U5.16 (Vcc), U6.2 (MD), U6.13 (S2), U6.14 (~CLR), U6.24 (Vcc), U8.16 (Vcc), U9.14 (Vcc), U10.14 (Vcc), U11.1 (R1), U11.10 (S2), U11.14 (Vcc), U12.1 (ES), U12.14 (Vcc), U13.14 (Vcc), X3.28, X4.28, X5.28, X6.28, X9.1, X72.6; also elsewhere on the board
/Hauptplatine/A0: U6.4 (Y1), X3.17, X4.17, X5.17, X6.17, X72.1
/Hauptplatine/A1: U6.6 (Y2), X3.18, X4.18, X5.18, X6.18, X72.2
/Hauptplatine/A2: U6.8 (Y3), X3.19, X4.19, X5.19, X6.19, X72.3
/Hauptplatine/A3: U6.10 (A4), X3.20, X4.20, X5.20, X6.20, X72.4
/Hauptplatine/A4: U6.21 (Y8), X3.21, X4.21, X5.21, X6.21
/Hauptplatine/A5: U6.19 (Y7), X3.22, X4.22, X5.22, X6.22
/Hauptplatine/A6: U6.17 (Y6), X3.23, X4.23, X5.23, X6.23
/Hauptplatine/A7: U6.15 (Y5), X3.24, X4.24, X5.24, X6.24
/Hauptplatine/A8: U1.13 (P00), X3.4, X4.4, X5.4, X6.4
/Hauptplatine/A9: U1.14 (P01), U10.6 (F), X3.5, X4.5, X5.5, X6.5
/Hauptplatine/A10: U1.15 (P02), U10.5 (E), X3.6, X4.6, X5.6, X6.6
/Hauptplatine/A11: U1.16 (P03), U10.4 (D), X3.7, X4.7, X5.7, X6.7
/Hauptplatine/A12: U1.17 (P04), U10.3 (C), X3.8, X4.8, X5.8, X6.8
/Hauptplatine/A13: U1.18 (P05), U5.1 (C), U10.2 (B)
/Hauptplatine/A14: U1.19 (P06), U5.2 (B), U10.1 (A)
/Hauptplatine/A15: U1.20 (P07), U5.3 (A), U10.12 (H)
/Hauptplatine/D0: U1.21 (P10), U6.3 (A1), U12.2 (A), X3.16, X4.16, X5.16, X6.16
/Hauptplatine/D1: U1.22 (P11), U6.5 (A2), U12.3 (B), X3.15, X4.15, X5.15, X6.15
/Hauptplatine/D2: U1.23 (P12), U6.7 (A3), U12.4 (C), X3.14, X4.14, X5.14, X6.14
/Hauptplatine/D3: U1.24 (P13), U6.9 (A4), U12.5 (D), X3.13, X4.13, X5.13, X6.13
/Hauptplatine/D4: U1.25 (P14), U6.22 (A8), U8.3 (O1), U13.2 (A), X3.12, X4.12, X5.12, X6.12
/Hauptplatine/D5: U1.26 (P15), U6.20 (A7), U8.5 (O2), U13.3 (B), X3.11, X4.11, X5.11, X6.11
/Hauptplatine/D6: U1.27 (P16), U6.18 (A6), U8.11 (O6), U13.4 (C), X3.10, X4.10, X5.10, X6.10
/Hauptplatine/D7: U1.28 (P17), U6.16 (A5), U8.13 (O5), U13.5 (D), X3.9, X4.9, X5.9, X6.9
/Hauptplatine/S0: R8.1, U8.2 (I1), X71.1
/Hauptplatine/S1: R11.1, U8.4 (I2), X71.2
/Hauptplatine/S2: R10.1, U8.12 (I6), X71.3
/Hauptplatine/S3: R9.1, U8.14 (I5), X71.4
BAS: D1.1 (K), D2.1 (K), X8.1
FF_SYNC: C6.1, R5.1, R6.2, U11.4 (S1), U11.13 (R2)
GND: C1.2, R6.1, U1.11 (GND), U5.8 (GND), U6.11 (STB), U6.12 (GND), U8.6 (I3), U8.8 (GND), U8.10 (I4), U9.7 (GND), U10.7 (GND), U11.7 (GND), U12.7 (GND), U13.7 (GND), X3.25, X4.25, X5.25, X6.25, X8.2, X9.2, X72.5; also elsewhere on the board
unnamed: C6.2, U9.12 (A4), U9.13 (B4), U10.8 (Y)
unnamed: D1.2 (A), R4.1, U1.4 (P37), X2.16
unnamed: D2.2 (A), R7.2
unnamed: Q1.1, R3.1, U9.1 (A1), U9.2 (B1)
unnamed: R3.2, U9.3 (Y1), U9.4 (A2), U9.5 (B2)
unnamed: R7.1, U13.10 (QD)
unnamed: U1.5 (P30), X2.9
unnamed: U1.9 (~AS), U6.1 (~S1)
unnamed: U1.10 (P35), X2.14
unnamed: U1.12 (P32), X2.11
unnamed: U1.30 (P33), X2.12
unnamed: U1.31 (P20), X2.1
unnamed: U1.32 (P21), X2.2
unnamed: U1.33 (P22), X2.3
unnamed: U1.34 (P23), X2.4
unnamed: U1.35 (P24), X2.5
unnamed: U1.36 (P25), X2.6
unnamed: U1.37 (P26), X2.7
unnamed: U1.38 (P27), X2.8
unnamed: U1.39 (P31), X2.10
unnamed: U1.40 (P36), X2.15
unnamed: U9.8 (Y3), U10.11 (G)
unnamed: U11.9 (Q2), U12.8 (T2), U12.9 (T1), U13.8 (T2), U13.9 (T1)
unnamed: U11.2 (D1), U11.6 (/Q1), U11.11 (T2)
unnamed: U11.8 (/Q2), U11.12 (D2)
unnamed: U9.11 (Y4), U12.6 (MC), U13.6 (MC)
unnamed: U12.10 (QD), U13.1 (ES)
P34: U1.29 (P34), X2.13, X3.29, X4.29, X5.29, X6.29
R~W: U1.7 (R/~W), X3.3, X4.3, X5.3, X6.3
TAKT: Q1.2, U1.3 (XTAL1), U9.6 (Y2), U11.3 (T1)
U1: X3.26, X4.26, X5.26, X6.26, X9.3
U2: X3.27, X4.27, X5.27, X6.27, X9.4
~CS0: U5.15 (Y0), X3.2
~CS1: U5.14 (Y1), X4.2
~CS2: U5.13 (Y2), X5.2
~CS3: U5.12 (Y3), U8.1 (~CE4), U8.15 (~CE2), X6.2
~CS4: U5.11 (Y4), X6.1
~CS5: U5.10 (Y5), X5.1
~CS6: U5.9 (Y6), X4.1
~CS7: U5.7 (Y7), X3.1
~DS: U1.8 (~DS), U5.4 (~E1), U5.5 (~E2), U9.9 (A3), U9.10 (B3)
~RESET: C1.1, TP1.1, U1.6 (~RESET)

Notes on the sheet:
E000-FFFF Modul 1
C000-DFFF Modul 2
A000-BFFF Modul 3
8000-9FFF Modul 4
6000-7FFF Modul 4
4000-5FFF Modul 3
2000-3FFF Modul 2
0800-1FFF Modul 1
Taktgenerator
Adressdekoder
Quelle: jutecomp1.pdf S. 6/7
Adresslatch
Stromversorgung
Tastaturlatch
S/W-Videoausgang
Quelle: JU+TE 07/1987, Seite 550-553
U1 und U2 Stützspannung für Zusatzspeicher ggf. auf 5V legen

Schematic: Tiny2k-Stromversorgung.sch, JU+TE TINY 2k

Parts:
C2: 22µF/16V; CP_Radial_D6.3mm_P2.50mm
C5: 2200µF/10V; CP_Axial_L25.0mm_D10.0mm_P35.00mm_Horizontal
C7, C8, C9, C10, C11: 10nF; C_Disc_D4.3mm_W1.9mm_P5.00mm
D3: 1PM05; Diode_Bridge_Round_D9.8mm
H1, H2, H3, H4: M3; MountingHole_3.2mm_M3
HS1: Kühlkörper; Heatsink_Aavid-TV5G_TO220_Horizontal
R1: 180; R_Axial_DIN0411_L9.9mm_D3.6mm_P12.70mm_Horizontal
R2: 560; R_Axial_DIN0309_L9.0mm_D3.2mm_P12.70mm_Horizontal
U14: B3170V; TO-220-3_Horizontal_TabDown
X1: AC: 8V/800mA; TerminalBlock_RND_205-00001_1x02_P5.00mm_Horizontal

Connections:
+5P: C2.1, C7.1, C8.1, C9.1, C10.1, C11.1, R1.2, U14.2 (VO); also elsewhere on the board
GND: C2.2, C5.2, C7.2, C8.2, C9.2, C10.2, C11.2, D3.1, R2.1; also elsewhere on the board
unnamed: C5.1, D3.3, U14.3 (VI)
unnamed: D3.2, X1.2
unnamed: D3.4, X1.1
unnamed: R1.1, R2.2, U14.1 (ADJ)

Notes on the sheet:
Quelle: jutecomp1.pdf S. 9
Quelle: JU+TE 08/1987, Seite 632-653
alternativ: DC: 10V/550mA
min. 50 mm^2 Kühlfläche
bei 12V Trafo: C2 auf 1000µF/16V ändern und stärkere Kühlung für U14 vorsehen


Board: 2 copper layers, 142.0 x 160.0 mm, 49 parts (0 on the bottom side), 78 nets.

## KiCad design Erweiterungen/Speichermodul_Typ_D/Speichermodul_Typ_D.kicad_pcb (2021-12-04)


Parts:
C3: 22nF; C_Disc_D4.3mm_W1.9mm_P5.00mm
U3: U2716; DIP-24_W15.24mm_Socket
X10: Sp.-Modul; PinHeader_1x29_P2.54mm_Horizontal

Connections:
+5P: C3.1, U3.21 (Upp), U3.24 (Udd), X10.28
/A0: U3.8 (A0), X10.17
/A1: U3.7 (A1), X10.18
/A2: U3.6 (A2), X10.19
/A3: U3.5 (A3), X10.20
/A4: U3.4 (A4), X10.21
/A5: U3.3 (A5), X10.22
/A6: U3.2 (A6), X10.23
/A7: U3.1 (A7), X10.24
/A8: U3.23 (A8), X10.4
/A9: U3.22 (A9), X10.5
/A10: U3.19 (A10), X10.6
/D0: U3.9 (D0), X10.16
/D1: U3.10 (D1), X10.15
/D2: U3.11 (D2), X10.14
/D3: U3.13 (D3), X10.13
/D4: U3.14 (D4), X10.12
/D5: U3.15 (D5), X10.11
/D6: U3.16 (D6), X10.10
/D7: U3.17 (D7), X10.9
/~CSB: U3.18 (~CE), U3.20 (~OE), X10.2
GND: C3.2, U3.12 (Uss), X10.25

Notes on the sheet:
2 kByte EPROM-Speicher
Quelle: jutecomp2.pdf S.32
EPROM 2 für 4k-System
Quelle: JU+TE 3/1989


Board: 2 copper layers, 76.0 x 36.0 mm, 3 parts (0 on the bottom side), 22 nets.

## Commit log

2021-07-26 initiale Version
    [Tiny2k-Hauptplatine.sch, Tiny2k-Magnetbandanschluss.sch, Tiny2k-Speichermodul.sch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]
2021-08-27 Speichervarianten bzw. Belegung ergänzt
    [Tiny2k.sch]
2021-10-26 Tiny 6k Videoerweiterung (Schaltplan) ergänzt
    [Tiny6k_Video-Adresssteuerung.sch, Tiny6k_Video-Ausgang.sch, Tiny6k_Video-Datensteuerung.sch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]
2021-10-26 Schaltplan annotiert
    [Tiny6k_Video-Adresssteuerung.sch, Tiny6k_Video-Ausgang.sch, Tiny6k_Video-Datensteuerung.sch]
2021-11-23 Hauptprozessor und Speichermodul ergänzt, komplette Überarbeitung
    [Tiny6k_Prozessor_Kompaktvariante.sch, Tiny6k_Video-Adresssteuerung.sch, Tiny6k_Video-Ausgang.sch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]
2021-11-24 Dateien umbenannt
    [Speichermodul_Typ_C.sch, Tiny6k_Hauptprozessor.sch, Tiny6k_Steuerung_Video-RAM.sch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]
2021-11-25 Ausbaustufen Video präzisiert
    [Speichermodul_Typ_C.sch, Tiny6k_Hauptprozessor.sch, Tiny6k_Steuerung_Video-RAM.sch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]
2021-11-25 csv-Stückliste ergänzt
    [Tiny6k_kompakt__Stueckliste.csv]
2021-11-27 C200 korrigiert, Footprints ergänzt
    [Speichermodul_Typ_C.sch, Tiny6k_Hauptprozessor.sch, Tiny6k_Steuerung_Video-RAM.sch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]
2021-12-04 Verzeichnisse umbenannt
    [Speichermodul_Typ_C.sch, Tiny2k-Hauptplatine.sch, Tiny2k-Magnetbandanschluss.sch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]
2021-12-04 Reorgansiation, tlw. Layouts ergänzt, Fehlerkorrektur
    [Speichermodul_A-B_Cu.gbr, Speichermodul_A-Edge_Cuts.gbr, Speichermodul_A-F_Cu.gbr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]
2021-12-05 RAM-Stütze ergänzt (Schaltplan)
    [Ramstuetze.sch]
2021-12-05 EPROM-Programmierzusatz (Schaltplan) ergänzt
    [EPROM-Programmierzusatz.sch]
2021-12-05 Magnetbandinterface 4k-System (Schaltplan) ergänzt
    [Magnetbandinterface_4k-System.sch]
2021-12-05 Referenz korrigiert
    [Magnetbandinterface_4k-System.sch]
2021-12-05 S3004-Interface (Schaltplan) ergänzt
    [S3004-Interface.sch]
2021-12-06 V.24-Schnittstelle (Schaltplan) ergänzt
    [V24-Interface.sch]
2021-12-06 IFSS (Schaltplan) ergänzt
    [IFSS-Interface.sch]
2021-12-06 EFS-Stecker korrigiert
    [IFSS-Interface.sch]
2021-12-06 AD-Wandler (Schaltplan) ergänzt
    [AD-Wandler.sch]
2021-12-06 Magnetbandanschluss (Platine) hinzugefügt, PDFs umbenannt
    [Magnetbandanschluss.kicad_pcb, Magnetbandanschluss.sch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]
2021-12-08 Videoerweiterung ergänzt (Schaltplan)
    [Videoerweiterung.sch, Videoerweiterung_Ausgabe.sch, Videoerweiterung_Prozessor.sch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]
2021-12-13 Übersichtlichkeit erhöht
    [Tiny6k_Steuerung_Video-RAM.sch]
2021-12-13 Vcc Anschluss am RAM korrigiert
    [Tiny6k_Hauptprozessor.sch]
2021-12-14 Kommentar zur Spannungsversorgung
    [Speichermodul_Typ_B.sch]
2021-12-14 Platine für Tastatur ergänzt
    [Tastatur-B_Cu.gbr, Tastatur-B_Mask.gbr, Tastatur-B_Paste.gbr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]
2021-12-14 Platine für Magnetbandinterface 4k-System ergänzt
    [Magnetbandinterface_4k-System.kicad_pcb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]
2021-12-14 Kommentar ergänzt
    [Magnetbandinterface_4k-System.sch]
2021-12-14 S3004-Interface präzisiert (und annotiert)
    [S3004-Interface.sch]
2021-12-17 Portübersicht ergänzt
    [JU+TE-Computer_Portbelegung_Uebersicht.xlsx]
2021-12-17 Portübersicht erweitert
    [JU+TE-Computer_Portbelegung_Uebersicht.xlsx]
2021-12-20 Platine für Videomodul ergänzt
    [Videoerweiterung-B_Cu.gbr, Videoerweiterung-B_Mask.gbr, Videoerweiterung-B_Paste.gbr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]
2022-02-01 Videoerweiterung 2021 hinzugefügt
    [Videoerweiterung-B_Adhes.gbr, Videoerweiterung-B_CrtYd.gbr, Videoerweiterung-B_Cu.gbr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]
2022-02-01 kleinere Korrekturen
    [Videoerweiterung_2021.csv]
2022-02-05 Bilder Magnetbandinterface ergänzt
2022-02-05 R20 gedreht
    [Videoerweiterung.kicad_pcb, Videoerweiterung_Ausgabe.sch]
2023-12-13 PCB korrigiert
    [Videoerweiterung.kicad_pcb]
2024-01-21 change: add diodes on keyboard column lines, resolve #1
    [Tiny6k_Hauptprozessor.sch, Tiny6k_kompakt__Stueckliste.csv]
